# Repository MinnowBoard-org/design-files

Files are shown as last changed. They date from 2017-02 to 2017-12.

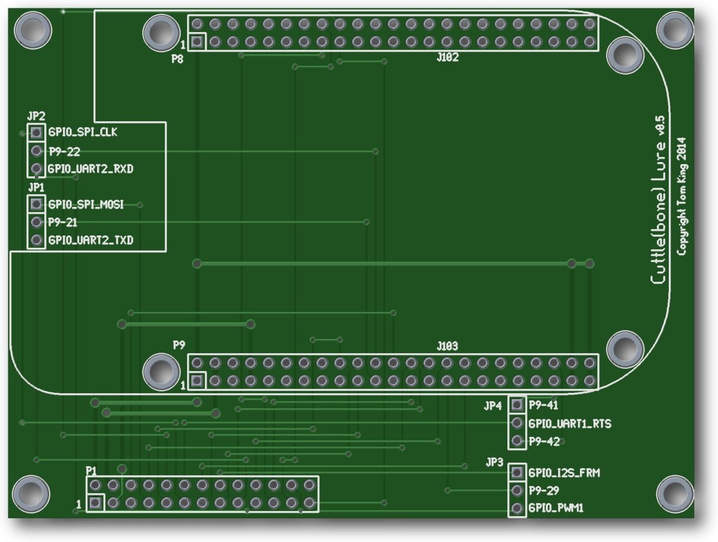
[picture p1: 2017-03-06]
expansion-boards-lures/cuttle-bone-lure/hardware/cuttle_lure_front.jpg

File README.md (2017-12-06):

# MinnowBoard.org Hardware Design Files

## PURPOSE:
The `/design-files` repository is the target folder for official [MinnowBoard.org] hardware design files. Such files may include: design schematics, printed circult board (PCB) design database(s), PCB gerber files, PCB manufacturing files, bill of materials (BOM), 3D models, mechanical step files, thermal models, multiple versions for different design tools, some firmware, CPLD code, FPGA code, etc. 

## LICENSING:
*All files are subject to the associated licensing stated within each directory.* [MinnowBoard.org] is founded with a goal for full open source, defaulting to [Creative Commons Attribution 4.0](https://creativecommons.org/licenses/by/4.0/) for hardware and [MIT](https://opensource.org/licenses/MIT) license for code....to let developers take the files and develop without licensing burden. We stick to this as much as possible. For a deep read, see MinnowBoard.org [Terms of Service and Intellectual Property Rights](https://www.minnowboard.org/terms-of-service). If you have questions, [Contact us.](https://www.minnowboard.org/help)

## SAFETY AND REGULATORY:
### The Disclaimer:
>The files for MinnowBoard reference designs do not guarantee regulatory compliance.  The developer is responsible for all aspects of regulatory evaluation, reporting and registration when modifying and/or incorporating any element of these reference designs into a host device.

### What it means:
Our goal is for developers to easily prototype their innovative idea with optimized MinnowBoard hardware/software/firmware, but this isn't the end goal. We ALSO want to enable developers to easily PRODUCTIZE and bring their idea to market. Such a product must meet the legal, safety, regulatory, commerce, etc, requirements for the target distribution geography. Thus, we spend extra time and effort to design our developer boards to already meet the electrical, EMI/EMC, safety, etc requirements for most global countries, and further, we test to those standards in licensed labs. We will often share the reports as reference baseline for developers considering design modifications. 
>Example: The current MinnowBoard target for EMI/EMC emissions in the United States is open board FCC Title 47 Part 15 Class B, which generally allows distribution to both commercial and residential environments. (Most developer boards are not even close to this).

*The Takeaway:* We do our best to minimize the effort required to achieve regulatory compliance on developer production design derivatives, but you are responsible for all aspects of regulatory compliance for your modification designs.

[MinnowBoard.org]: https://minnowboard.org/

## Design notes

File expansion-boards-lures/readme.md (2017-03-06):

Breakout boards called "Lures" expand functionality of the MinnowBoard MAX by connecting to either the low- or high-speed
expansion connectors. Lures are owned and supported by their respective owners and manufacturers. The community can give 
you best effort support; issues should be taken to the respective manufacturers and designers.

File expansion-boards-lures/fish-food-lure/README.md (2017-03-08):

# lure-fish-food

Fish Food Lure, breadboard adapter for the MinnowBoard MAX / Turbot compatible boards (because you feed bread to fish).   

Fish Food Lure enables fast prototyping on a breadboard, connects to the MinnowBoard using a ribbon cable.      

Designed and released by Jose Navarro. 

Released under the Creative Commons Attribution 3.0 License     
https://creativecommons.org/licenses/by/3.0/   

Designed using DipTrace 3.0

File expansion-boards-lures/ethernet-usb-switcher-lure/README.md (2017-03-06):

# lure-lse-eth-usb-switch
Ethernet and USB Switcher controlled via the LSE for MinnowBoard MAX / Turbot compatible boards  

This Lure enables the physical disconnection of the Ethernet and USB ports of the device connected to this Lure. You may use this Lure to remotely enable environments, testing tasks, etc. 

Diptrace was used for the creation of this project.

Licensed under the Creative Commons Attribution Share-Alike 3.0 License.

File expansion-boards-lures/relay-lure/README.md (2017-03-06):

# lure-lse-relay  
"Relay Lure" for MinnowBoard MAX / Turbot compatible boards Low Speed Expansion (LSE) header  

Features
4-channel Relay Lure that can handle ~6A, 110VAC / ~4A, 30VDC per channel(Take appropriate precautions when handling this board).  
Screw in Block terminals with Normally Closed and Normally open connections(5mm Pitch).   
GPIOs are protected using Optocouplers.    
Experimental header to connect an HC-06 type Bluetooth module to a UART port, to enable the control of the MinnowBoard with another Bluetooth enabled devices. 

---------------------------------------------

"Big Relay Lure" for MinnowBoard MAX / Turbot compatible boards Low Speed Expansion (LSE) header 

Features
8-channel Relay Lure that can handle ~6A, 110VAC / ~4A, 30VDC per channel(Take appropriate precautions when handling this board).  
Screw in Block terminals with Normally Closed and Normally open connections(9.52mm Pitch).   
GPIOs are protected using Optocouplers. 
1-Wire devices hub, devices can be hooked up via RJ11 connectors and/or screw in block terminals.
The "Big Relay Lure" is an external Lure with 4 holes(2.5mm diameter) for standoffs, connects to the MinnowBoard via a Ribbon Cable.  

Both Designs made in Diptrace 3.0

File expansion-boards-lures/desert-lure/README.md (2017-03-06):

# DesertLure
A lure for the MinnowBoard Max & MinnowBoard Turbot.  Copyright (C) 2015 Smallworks, LLC

This design is made with [EAGLE CAD](http://www.cadsoftusa.com/eagle-pcb-design-software/about-eagle/) 

This work is licensed under a Creative Commons Attribution-ShareAlike 4.0 International License
[  
*Licensing CC BY-SA 4.0*](http://creativecommons.org/licenses/by-sa/4.0/)

It may be used for Educational, Personal, or Commercial Use, provided you keep these notices,
attribution, and share-alike. When you apply these licenses to material you create, 
it meets the Freedom Defined definition of a "Free Cultural Work". 
Free cultural works are the ones that can be most readily used, shared, 
and remixed by others, and go furthest toward creating a commons of freely reusable materials.

-------------------------------------------------------------------------------------------

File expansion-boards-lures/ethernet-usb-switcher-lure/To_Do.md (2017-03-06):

To do list

Use Diptrace 2.9 Beta or wait for final relase to make use of the Differential Pairs utility. 

Move Ethernet and USB ports so they are closer together in order to keep the data paths shorter.

Use a separate transistor to drive each relay in order to prevent overloading the 2 transistors in darlington array.  

Done:
- Make power paths bigger to prevent power issues if 1 OZ copper manufacturing process is choosen(Which is the most common). 
- Remove the 5V regulator as it is an overkill part of the design.

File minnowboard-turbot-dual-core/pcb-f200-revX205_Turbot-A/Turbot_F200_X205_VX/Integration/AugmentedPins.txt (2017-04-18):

------------------------------------------------------------------------
            Part/Reference             | Pin | Augmented Net Name
------------------------------------------------------------------------
 Part 4124-0013                        |
       U41                             |    7| <unconnected pin>
       U41                             |   17| <unconnected pin>

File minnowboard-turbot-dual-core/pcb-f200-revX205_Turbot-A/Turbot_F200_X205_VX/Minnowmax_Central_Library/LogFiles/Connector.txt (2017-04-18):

	SLB2LMC  -  Add Symbol Information to LMC. Version 16.0.0.1
	(c) Copyright Mentor Graphics Corporation 2003.
	All Rights Reserved.

Reading Library Path Information...
Reading Font Information...
Reading Text Property Information...
Reading Pin Type Information...
Processing Connector
	Symbol CON_HIER_BI
	Symbol CON_HIER_I
	Symbol CON_HIER_IQ
	Symbol CON_HIER_O
	Symbol CON_HIER_OQ
	Symbol CON_HIER_T
	Symbol CON_INTER_BI
	Symbol CON_INTER_I
	Symbol CON_INTER_IQ
	Symbol CON_INTER_O
	Symbol CON_INTER_OQ
	Symbol CON_INTER_T
	Symbol CON_INTRA
	Symbol CONNP
	Symbol CONNS
	Symbol ESPL1
	Symbol ESROPE
	Symbol RWTERM
SLB2LMC utility complete

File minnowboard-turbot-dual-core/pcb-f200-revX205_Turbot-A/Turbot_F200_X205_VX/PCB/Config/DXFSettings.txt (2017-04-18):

.FILETYPE DXF_EXPORT_SETTINGS
.VERSION "VB99.1"
.DATE "09/17/2015 15:18:10"

!  This file contains settings for the most recent DXF export session

.UNITS in

.SCHEME "AssyBot"
 ..SCHEME_LOCATION Local

.FILL_PADS 0

.BOARD_CONTENTS 0

.MIRROR_OUTPUT 0

.ITEM "Assembly Outlines Btm"
 ..LAYER "Assembly_Outlines_Btm"
 ..EXPORT 1

.ITEM "Assembly Ref Des Btm"
 ..LAYER "Assembly_Ref_Des_Btm"
 ..EXPORT 1

.ITEM "Board Outline"
 ..LAYER "Board_Outline"
 ..EXPORT 1

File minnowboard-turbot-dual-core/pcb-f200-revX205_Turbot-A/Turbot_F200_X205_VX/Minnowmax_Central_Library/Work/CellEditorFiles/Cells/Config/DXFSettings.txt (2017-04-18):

.FILETYPE DXF_EXPORT_SETTINGS
.VERSION "VB99.1"
.DATE "05/28/2007 22:27:46"

!  This file contains settings for the most recent DXF export session

.UNITS th

.SCHEME "Default"
 ..SCHEME_LOCATION Local

.ITEM "Assembly Outlines Top"
 ..LAYER "Assembly_Outlines_Top"
 ..EXPORT 1

.ITEM "Board Origin"
 ..LAYER "Board_Origin"
 ..EXPORT 1

.ITEM "Board Outline"
 ..LAYER "Board_Outline"
 ..EXPORT 1

.ITEM "Cell_Info"
 ..LAYER "Cell_Info"
 ..EXPORT 1

.ITEM "Mounting Hole Pads Layer 1"
 ..LAYER "Mounting_Hole_Pads_Layer_Top"
 ..EXPORT 1

.ITEM "Mounting Hole Pads Layer 2"
 ..LAYER "Mounting_Hole_Pads_Layer_Bottom"
 ..EXPORT 1

.ITEM "Mounting Holes Layer 1"
 ..LAYER "Mounting_Holes_Layer_Top"
 ..EXPORT 1

.ITEM "Mounting Holes Layer 2"
 ..LAYER "Mounting_Holes_Layer_Bottom"
 ..EXPORT 1

.ITEM "NC Drill Origin"
 ..LAYER "NC_Drill_Origin"
 ..EXPORT 1

.ITEM "Placement Outlines Top"
 ..LAYER "Placement_Outlines_Top"
 ..EXPORT 1

.ITEM "Route Obstructs Layer 1"
 ..LAYER "Route_Obstructs_Layer_Top"
 ..EXPORT 1

.ITEM "Route Obstructs Layer 2"
 ..LAYER "Route_Obstructs_Layer_Bottom"
 ..EXPORT 1

.ITEM "Silkscreen Outlines Top"
 ..LAYER "Silkscreen_Outlines_Top"
 ..EXPORT 1

.ITEM "Soldermask Pads Btm"
 ..LAYER "Soldermask_Pads_Btm"
 ..EXPORT 1

.ITEM "Soldermask Pads Top"
 ..LAYER "Soldermask_Pads_Top"
 ..EXPORT 1

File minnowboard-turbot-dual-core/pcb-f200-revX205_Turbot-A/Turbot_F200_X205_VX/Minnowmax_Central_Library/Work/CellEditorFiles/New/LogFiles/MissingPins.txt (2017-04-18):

Missing Pins Log

Date : 11:19:29 AM Dec 01, 2012

During load of this design, cells within the design have been found missing pins or mounting holes
compared to the cell as defined in the cell library.  In order to maintain data integrity, these cells need
to be reset from the cell library and forward annotation needs to be run.  This process will cause any 
layout cell edits to be lost for the cells listed below.

"Ref Des" "qfn" has 48 pin(s) within Layout and 0 pin(s) within the Cell Library.

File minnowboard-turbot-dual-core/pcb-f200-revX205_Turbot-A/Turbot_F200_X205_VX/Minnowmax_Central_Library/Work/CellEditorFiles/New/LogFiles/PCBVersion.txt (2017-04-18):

 Version: EXP2005.3_070529.00 2005.3

Environment Variables:
----------------------
HOMEDRIVE = "C:"
HOMEPATH = "\Documents and Settings\XPMUser"
MGC_HOME = "C:/MentorGraphics/2005EXP/MGC_HOME.ixn"
OS = "Windows_NT"
PATH = "C:\MentorGraphics\2005EXP\SDD_HOME\common\win32\bin;C:\MentorGraphics\2005EXP\SDD_HOME\common\win32\lib;C:\MentorGraphics\2005EXP\SDD_HOME\common\win32\_bin;C:\MentorGraphics\2005EXP\SDD_HOME\wg\win32\bin;C:\MentorGraphics\2005EXP\SDD_HOME\wg\win32\lib;C:\MentorGraphics\2005EXP\SDD_HOME\common\win32\bin;C:\MentorGraphics\2005EXP\SDD_HOME\common\win32\lib;C:\WINDOWS\system32;C:\WINDOWS;C:\WINDOWS\System32\Wbem;C:/MentorGraphics/2005EXP/MGC_HOME.ixn\bin;C:/MentorGraphics/2005EXP/MGC_HOME.ixn\lib;C:/MentorGraphics/2005EXP/MGC_HOME.ixn\bin;C:/MentorGraphics/2005EXP/MGC_HOME.ixn\lib;C:\OrCAD\OrCAD_10.5\tools\bin;C:\OrCAD\OrCAD_10.5\tools\fet\bin;C:\OrCAD\OrCAD_10.5\tools\Capture;C:\Cadence\PSD_14.2\tools\pcb\bin;C:\Cadence\PSD_14.2\tools\bin;C:\Cadence\PSD_14.2\tools\jre\bin;C:\Cadence\PSD_14.2\tools\fet\bin;C:\Cadence\PSD_14.2\tools\specctra\bin;C:\Cadence\PSD_14.2\tools\libutil\bin"
SDD_HOME = "C:\MentorGraphics\2005EXP\SDD_HOME"
TEMP = "C:\DOCUME~1\XPMUser\LOCALS~1\Temp"
TMP = "C:\DOCUME~1\XPMUser\LOCALS~1\Temp"

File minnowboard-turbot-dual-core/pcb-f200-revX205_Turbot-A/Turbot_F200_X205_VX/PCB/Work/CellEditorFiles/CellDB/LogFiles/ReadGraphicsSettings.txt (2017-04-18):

                         Read Graphics Settings Log File
                         -------------------------------

                      10:01 AM Thursday, December 03, 2015
                                   Job Name: 

Attempting to read Graphics Settings file <Graphics Settings.hkp>

The settings file full pathname is <C:\Turbot\Turbot_F200_X205_VX\PCB\Work\CellEditorFiles\CellDB\Config\Graphics Settings.hkp>

Found 2 views, but 3 are required.

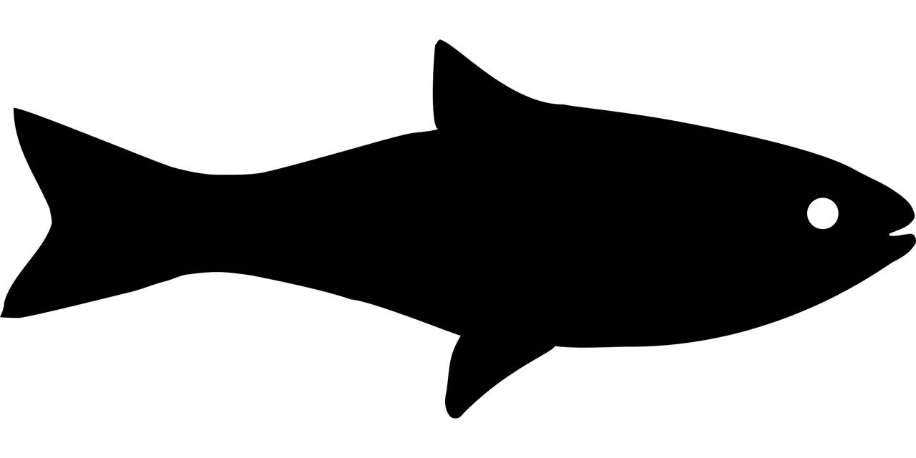
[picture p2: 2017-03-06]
expansion-boards-lures/relay-lure/Big Relay Board/Design Files/fish-1294822_1280.tiff

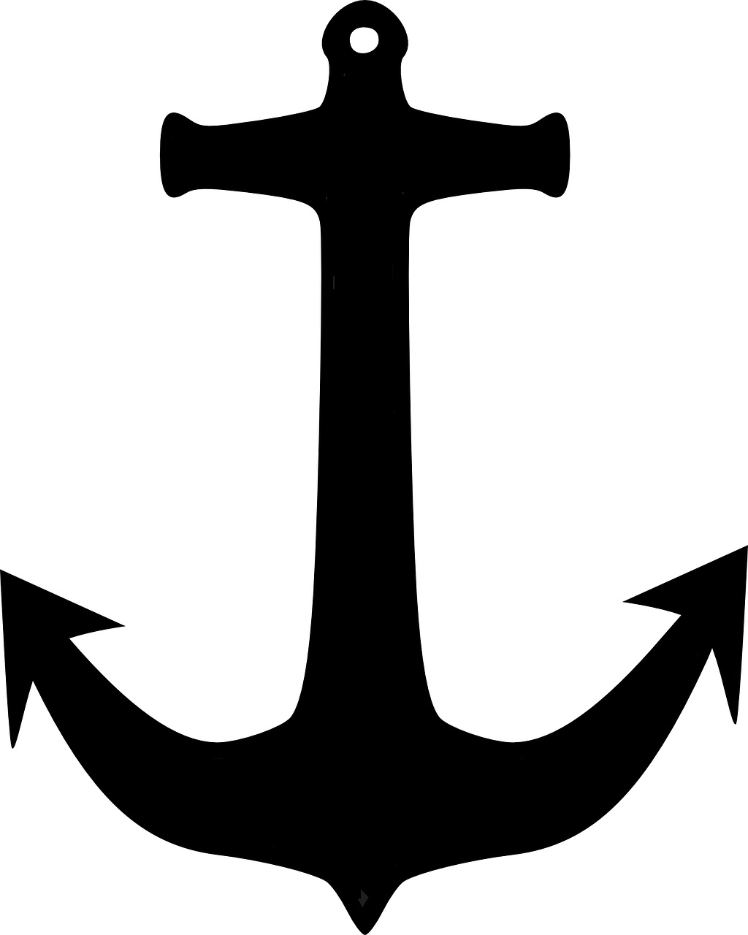
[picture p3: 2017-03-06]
expansion-boards-lures/fish-food-lure/Design files/anchor-297206_1280.jpg

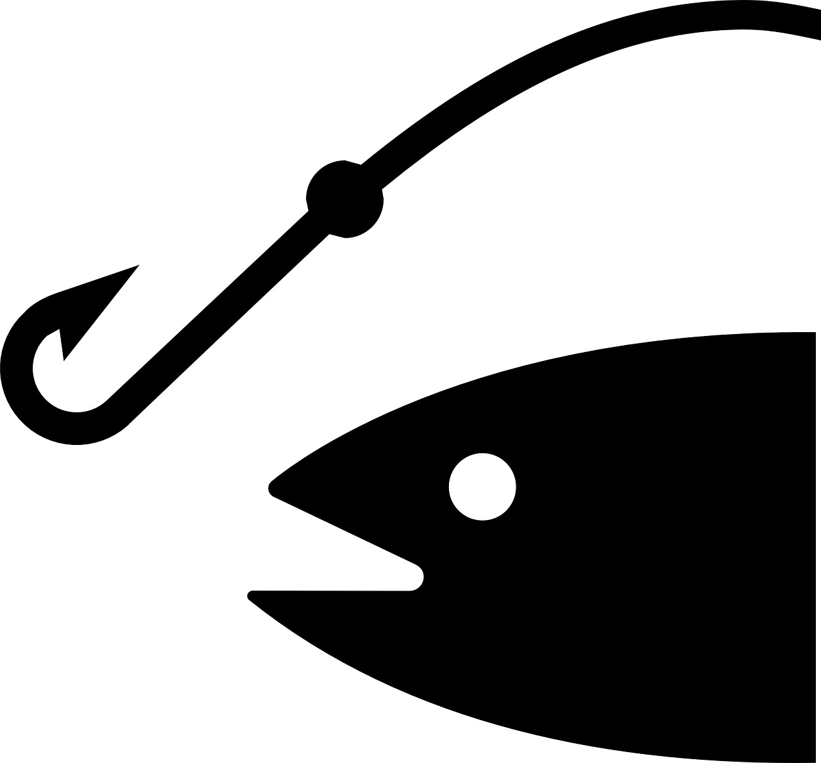
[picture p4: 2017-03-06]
expansion-boards-lures/fish-food-lure/Design files/fish-304097_1280.jpg

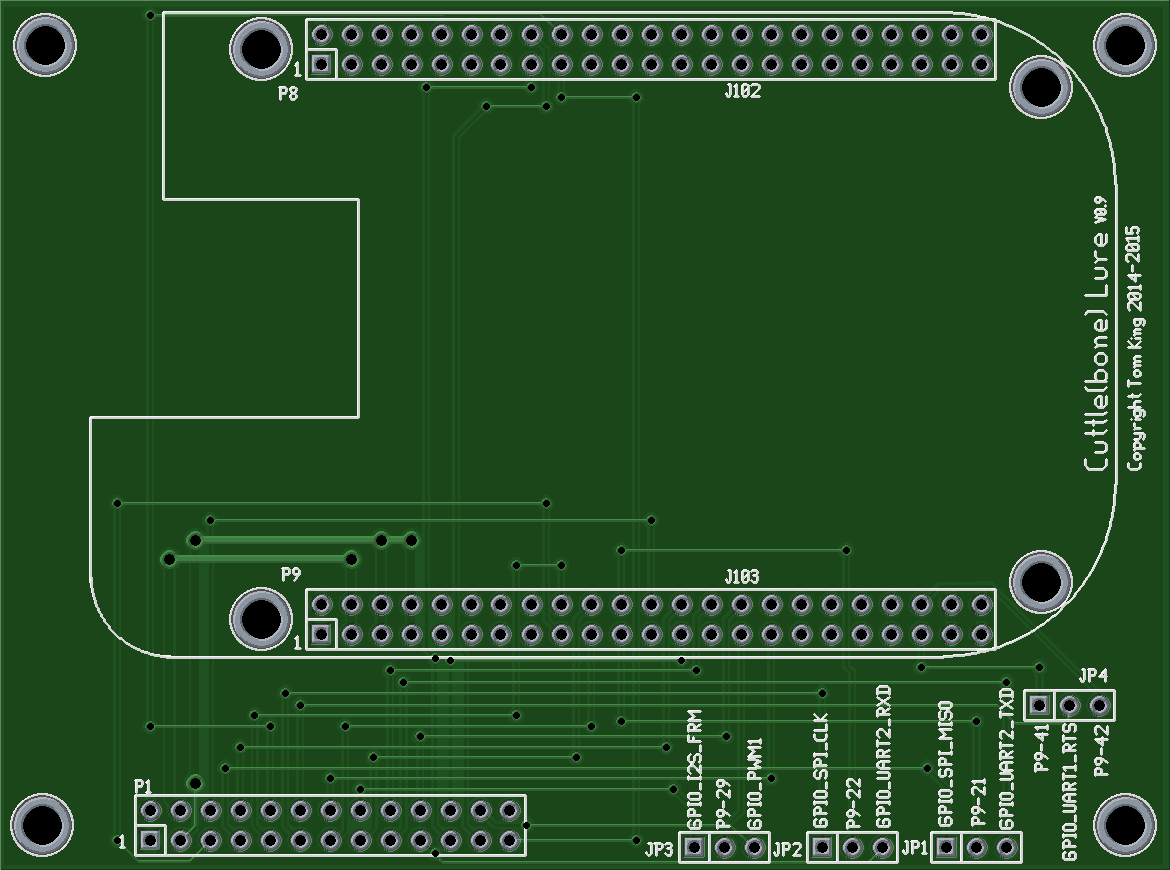
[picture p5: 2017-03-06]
expansion-boards-lures/cuttle-bone-lure/hardware/cuttle_lure_v0.9.png

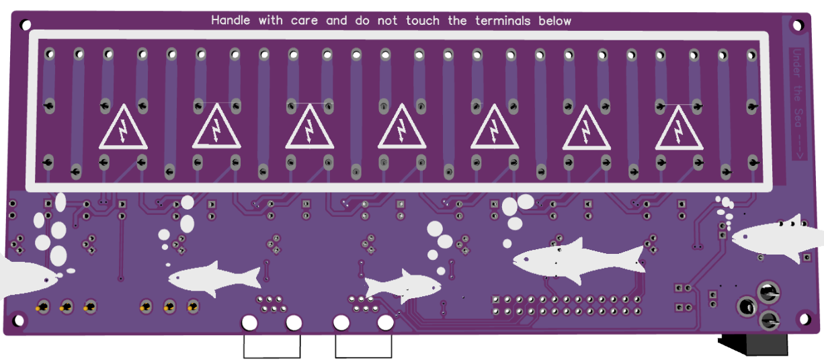
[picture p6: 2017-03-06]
expansion-boards-lures/relay-lure/Big Relay Board/Big Relay Lure back.png

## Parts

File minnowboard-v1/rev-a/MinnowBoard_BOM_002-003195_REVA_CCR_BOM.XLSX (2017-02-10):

Item_no | Part_class | Part_no | Rev | Descript | Partmfgr | Mfgr_pt_no | Qty | Ref_des
1 | PCB | 000-0002806 | A | MINNOW BOARD | GENR | 000-0002806 | 1 | PCB1
2 | BATTERY | 353-0003073 |  | BATT,COIN,12.5MM,VET MT | MPD | BS-1225-PC | 1 | BH1
3 | RES | 110-0002124 |  | 0603,0R00,JUMPER,1/10W | PANASONI | ERJ-3GEY0R00V | 2 | FB1, FB3
4 | CAP-SMT | 123-0001157 |  | 0805,10UF,10V,X5R,10% | KEMET | C0805C106K8PACTU | 41 | C1, C2, C22, C32, C41, C65, C66, C67, C68, C69, C70, C79, C81, C82, C88, C90, C115, C271, C272, C275, C276, C279, C280, C284, C297, C298, C303, C306, C307, C310, C323, C336, C337, C347, C348, C349, C361, C365, C380, C390, C391
5 | CAP-SMT | 123-0001144 |  | 0603,4.7UF,10V,X5R,10% | TAIYO_YUDEN | LMK107BJ475KA-T | 14 | C10, C20, C26, C109, C160, C376, C377, C379, C381, C386, C389, C397, C398, C409
6 | CAP-SMT | 123-0001032 |  | 0402,0.01UF,16V,X7R,10% | AVX | 0402YC103KAT2A | 20 | C100, C118, C119, C126, C132, C138, C139, C144, C149, C152, C155, C162, C166, C180, C181, C182, C183, C281, C282, C283
7 | CAP-SMT | 123-0001115 |  | 0402,47PF,50V,C0G/NP0,5% | MURATA | GRM1555C1H470JZ01D | 4 | C107, C108, C239, C290
8 | CAP-SMT | 123-0001045 |  | 0402,0.047UF,25V,X7R,10% | TAIYO_YUDEN | TMK105B7473KV-F | 2 | C141, C143
9 | CAP-SMT | 123-0001078 |  | 0402,12PF,50V,C0G/NP0,5% | MURATA | GRM1555C1H120JZ01D | 2 | C156, C157
10 | CAP-SMT | 123-0001095 |  | 0402,2.2UF,6.3V,X5R,20% | MURATA | GRM155R60J225ME15D | 17 | C16, C25, C104, C106, C135, C171, C203, C204, C206, C213, C218, C219, C223, C226, C228, C421, C422
11 | CAP-SMT | 123-0003096 |  | 1411,47UF,6.3V,10% | NICHICON | F930J476KBA | 8 | C174, C175, C338, C341, C343, C344, C345, C346
12 | CAP-SMT | 123-0003098 |  | 0402,820PF,50V,C0G/NPO,5% | MURATA | GRM1555C1H821JA01D | 3 | C185, C202, C212
13 | CAP-SMT | 123-0003097 |  | 0402,200PF,50V,C0G/NP0,5% | MURATA | GRM1555C1H201JA01D | 3 | C205, C208, C222
14 | CAP-SMT | 123-0001060 |  | 0402,0.22UF,6.3V,X5R,10% | TAIYO_YUDEN | JMK105BJ224KV-F | 4 | C247, C263, C378, C403
15 | CAP-SMT | 123-0003064 |  | 220UF,10V,20% | PANASONI | EEE-FK1A221XP | 8 | C350, C372, C384, C394, C395, C396, C417, C418
16 | CAP-SMT | 123-0003611 |  | 0402,1000PF,6.3V,X5R,10% | MURATA | GRM155R60J102KA01D | 1 | C388
17 | CAP-SMT | 123-0001074 |  | 0402,100PF,50V,C0G/NP0,5% | MURATA | GRM1555C1H101JA01D | 9 | C49, C51, C61, C63, C64, C148, C151, C161, C165
18 | CAP-SMT | 123-0003092 |  | 1206,1UF,16V,X7R,10% | TDK | C3216X7R1C105K/0.85 | 1 | C58
19 | CAP-SMT | 123-0001092 |  | 0402,1UF,6.3V,X5R,10% | MURATA | GRM155R60J105KE19D | 83 | C6, C17, C18, C19, C47, C50, C56, C80, C125, C140, C158, C163, C168, C169, C170, C178, C187, C191, C193, C194, C195, C196, C197, C198, C199, C200, C201, C234, C237, C238, C240, C241, C242, C243, C244, C245, C246, C248, C249, C250, C251, C252, C253, C254,C255, C256, C257, C258, C259, C260, C261, C262, C264, C265, C287, C288, C289, C291, C292, C293, C294, C295, C296, C314, C315, C316, C317, C318, C319, C320, C321, C322, C342, C351, C352, C356, C357, C370, C373, C400, C401, C402, C1044
20 | CAP-SMT | 123-0003093 |  | 0402,2700PF,50V,X7R,10% | MURATA | GRM155R71H272KA01D | 8 | C7, C13, C34, C35, C117, C137, C266, C268
21 | CAP-SMT | 123-0003102 |  | 0805,22UF,10V,X5R,20% | TAIYO_YUDEN | LMK212BJ226MG-T | 11 | C71, C87, C91, C92, C186, C231, C232, C360, C362, C405, C406
22 | CAP-SMT | 123-0001082 |  | 0402,18PF,50V,C0G/NP0,5% | AVX | 04025A180JAT2A | 2 | C72, C74
23 | CAP-SMT | 123-0003347 |  | 0402,20PF,50V,C0G/NP0,5% | YAGEO | CC0402JRNPO9BN200 | 2 | C75, C86
24 | CAP-SMT | 123-0001046 |  | 0402,0.1UF,16V,X5R,10% | MURATA | GRM155R61C104KA88B | 162 | C8, C14, C15, C23, C24, C27, C28, C29, C30, C31, C33, C36, C37, C38, C39, C40, C42, C43, C44, C45, C46, C48, C52, C53, C54, C55, C57, C59, C60, C62, C73, C76, C77, C78, C83, C84, C85, C94, C96, C97, C98, C99, C101, C102, C105, C114, C116, C122, C123, C124, C127, C128, C129, C130, C131, C133, C134, C136, C142, C145, C146, C147, C150, C153, C154, C159, C164, C167, C172, C173, C176, C177, C179, C184, C188, C189, C190, C192, C207, C209, C210, C211, C214, C215, C216, C217, C220, C221, C224, C225, C227, C229, C230, C233, C236, C267, C269, C270, C273, C274, C277, C278, C285, C286, C299, C300, C301, C302, C304, C305, C308, C309, C311, C312, C313, C324, C325, C326, C327, C328, C329, C330, C331, C332, C333, C334, C335, C339, C340, C353, C354, C355, C358, C359, C364, C366, C367, C368, C369, C371, C374, C375, C382, C385, C387, C392, C393, C399, C404, C407, C408, C410, C411, C412, C413, C414, C415, C420, C423, C424, C1043, C235
25 | CAP-SMT | 123-0003088 |  | 0402,470PF,50V,C0G/NP0,5% | MURATA | GRM1555C1H471JA01D | 4 | C89, C93, C95, C419
26 | LED | 131-0001743 |  | 0603,GREEN/CLEAR | LITEON | LTST-C190GKT | 4 | D11, D12, D13, D15
27 | LED | 131-0001747 |  | 0603,RED/CLEAR | LITEON | LTST-C190CKT | 1 | D14
28 | DIODE | 130-0001371 |  | 0603,TVS,24 VDC,ESD | LITTLEFUSE | PGB1010603MR | 4 | D2, D3, D4, D5
29 | DIODE | 130-0003105 |  | ZENER,3.3V,500MW,SOD123 | DIODES_I | MMSZ5226B-7-F | 1 | D6
30 | DIODE | 130-0003083 |  | TVS,1500W,5V,DO-214AB | LITTLEFUSE | SMCJ5.0CA | 1 | D7
31 | DIODE | 130-0003078 |  | SCHOTTKY,30V,200MA,SOT23 | DIODES_I | BAT54TA | 1 | D9
32 | FUSE | 152-0003279 |  | 1206,PTC RESET,0.75A,8V | LITTLEFUSE | 1206L075THYR | 1 | F2
33 | FERRITE | 126-0003085 |  | 0603,120R,500MA | MURATA | BLM18BB121SN1D | 8 | FB2, FB4, FB8, FB9, FB10, FB11, FB12, FB13
34 | FERRITE | 126-0001427 |  | 0805,150R,800MA | LAIRD_S | LI0805H151R-10 | 2 | FB6, FB7
35 | CONN/HDR | 158-0001276 |  | RCPT,HDMI,R/A | FCI | 10029449-001RLF | 1 | J1
36 | CONN/HDR | 258-0001299 |  | 3 POS,SGLE,STR,TIN | SULLINS | PEC03SAAN | 1 | J10
37 | CONN/HDR | 258-0003129 |  | 8 POS,DUAL,TIN | FCI | 67997-408HLF | 1 | J11
38 | CONN/HDR | 258-0003669 |  | MAG45 JACK W/LED GIGABIT | LINK-PP | LPJG16314A4NL | 1 | J12
39 | CONN/HDR | 158-0003076 |  | RCPT,STD,MICRO,USB,TYPE B | FCI | 10103594-0001LF | 1 | J14
40 | CONN/HDR | 258-0001330 |  | JACK,PWR,2.1MM | CUI | PJ-002A | 1 | J15
41 | CONN/HDR | 258-0002513 |  | 2 POS,DUAL,TIN | FCI | 67997-402HLF | 2 | J2, J13
42 | CONN/HDR | 258-0003610 |  | 7 POS,SERIAL,GOLD,SATA | MOLEX | 0470804005 | 1 | J3
43 | CONN/HDR | 258-0002845 |  | 4 POS,SGLE,STR,TIN | SULLINS | PEC04SAAN | 1 | J4
44 | CONN/HDR | 158-0003130 |  | 100 POS,FH,GOLD,.8MM | TE_CONN | 1-5177986-4 | 1 | J8
45 | CONN/HDR | 258-0002540 |  | 10 POS,DUAL,TIN | FCI | 67997-410HLF | 1 | J9
46 | INDUCTOR | 125-0003114 |  | 4.7UH,30%,1.5A | TDK | VLCF4028T-4R7N1R5-2 | 1 | L12
47 | INDUCTOR | 125-0003106 |  | 1.5UH,30%,3.6A | TAIYO_YUDEN | NR5040T1R5N | 3 | L13, L14, L17
48 | INDUCTOR | 125-0003066 |  | 1.5UH,30%,2.5A | PANASONIC | ELL-6PG1R5N | 2 | L15, L16
49 | INDUCTOR | 125-0003169 |  | 1.0UH,30%,2.0A | TDK | VLF3012ST-1R0N2R0 | 1 | L19
50 | FILTER | 127-0003065 |  | COM MODE 90R0 | PANASONIC | EXC-24CG900U | 4 | L2, L3, L4, L5
51 | INDUCTOR | 125-0003117 |  | 1.8UH,30%,2A | TDK | VLCF5020T-1R8N2R0 | 1 | L20
52 | INDUCTOR | 125-0003103 |  | 1210,20%,4.7UH,1000MA | MURATA | LQH32PN4R7NN0L | 1 | L21
53 | FERRITE | 126-0001421 |  | 0603,300R,500MA | TDK | MMZ1608R301A | 7 | L6, L7, L8, L9, L10, L11, L18
54 | CONN/HDR | 158-0001269 |  | MICRO SD,PUSH-PUSH | ALPS | SCHA5B0200 | 1 | P1
55 | CONN/HDR | 158-0003524 |  | 5 POS,STEREO JACK,3.5MM,GRN | CUI | SJ1-3515-SMT-TR-GR | 1 | P3
56 | CONN/HDR | 158-0003523 |  | 5 POS,STEREO JACK,3.5MM,BLE | CUI | SJ1-3515-SMT-TR-BE | 1 | P2
57 | CONN/HDR | 158-0001279 |  | RCPT,USB MINI,R/A | HIROSE | UX60SC-MB-5ST(80) | 1 | PP4
58 | CONN/HDR | 258-0001344 |  | RCPT,USB,TYPE A,R/A,DUAL | FCI | 72309-8034BLF | 1 | P5
59 | TRANSIS | 132-0002279 |  | NPN/NPN,W/RES,50V,SMINI6 | PANASONIC | DMC564040R | 3 | Q1, Q2, Q8
60 | TRANSIS | 132-0002268 |  | MOSFET,N-CH,50V,200MA,SOT23 | DIODES_INC | BSS138-7-F | 5 | Q3, Q4, Q5, Q6, Q7
61 | TRANSIS | 132-0003412 |  | MOSFET,P-CH,20V,460MA,SOT523 | DIODES_INC | DMG1013T-7 | 1 | Q9
62 | RES | 110-0003145 |  | 0402,56R2,1/16W,1% | VISHAY_T | CRCW040256R2FKTD | 31 | R1, R2, R3, R4, R5, R6, R7, R8, R9, R15, R16, R17, R18, R19, R22, R23, R24, R35, R36, R39, R40, R43, R66, R67, R84, R86, R332, R333, R21, R334, R340
63 | RES | 110-0001877 |  | 0402,10K0,1/16W,1% | KOA | RK73H1ETTP1002F | 84 | R10, R11, R25, R31, R32, R46, R50, R51, R61, R62, R70, R75, R92, R106, R108, R118, R122, R164, R165, R171, R182, R188, R213, R214, R215, R216, R224, R229, R231, R242, R243, R244, R245, R246, R247, R248, R256, R260, R274, R280, R281, R287, R295, R297, R299, R303, R315, R321, R322, R323, R324, R327, R339, R345, R347, R348, R349, R350, R372, R374, R375, R377, R386, R387, R388, R393, R411, R415, R416, R417, R420, R422, R430, R431, R432, R433, R444, R449, R451, R452, R454, R457, R467, R629
64 | RES | 110-0002076 |  | 0402,51K0,1/16W,1% | STACKPOLE | RMCF0402FT51K0 | 1 | R12
65 | RES | 110-0002014 |  | 0402,33R0,1/16W,1% | KOA | RK73HETTP33R0F | 20 | R140, R142, R284, R285, R286, R289, R290, R291, R292, R293, R294, R298, R312, R313, R355, R358, R413, R414, R438, R439
66 | RES | 110-0003049 |  | 0402,249R,1/10W,1% | PANASONIC | ERJ-2RKF2490X | 1 | R141
67 | RES | 110-0003137 |  | 0402,24R9,1/16W,1% | VISHAY_T | CRCW040224R9FKED | 4 | R167, R169, R425, R426
68 | RES | 110-0002002 |  | 0402,330R,1/16W,1% | KOA | RK73H1ETTP3300F | 4 | R173, R174, R195, R210
69 | RES | 110-0003196 |  | 0402,0R56,1/10W,5% | CTS | 73L1R56J | 6 | R175, R185, R186, R196, R197, R212
70 | RES | 110-0003167 |  | 0805,0R01,1/8W,1% | VISHAY_T | RL0805FR-070R01L | 4 | R176, R187, R211, R241
71 | RES | 110-0002558 |  | 0402,22R0,1/10W,1% | PANASONIC | ERJ-2RKF22R0X | 14 | R179, R180, R189, R190, R191, R192, R329, R330, R338, R346, R351, R352, R353, R354
72 | RES | 110-0002625 |  | 0402,470R,1/16W,1% | VISHAY_T | CRCW0402470RFKED | 1 | R184
73 | RES | 110-0002048 |  | 0402,49K9,1/16W,1% | STACKPOLE | RMCF0402FT49K9 | 5 | R199, R202, R203, R206, R207
74 | RES | 110-0003143 |  | 0402,39R2,1/16W,1% | VISHAY_T | CRCW040239R2FKED | 6 | R20, R33, R34, R37, R38, R55
75 | RES | 110-0002047 |  | 0402,499R,1/16W,1% | ROHM | MCR01MZPF4990 | 5 | R200, R201, R204, R205, R208
76 | RES | 110-0003655 |  | 0402,39K0,1/16W,1% | YAGEO | RC0402FR-0739KL | 1 | R234
77 | RES | 110-0002103 |  | 0402,68K0,1/10W,1% | PANASONIC | ERJ-2RKF6802X | 1 | R235
78 | RES | 110-0003656 |  | 0402,5K10,1/16W,1% | YAGEO | RC0402FR-075K1L | 1 | R249
79 | RES | 110-0003140 |  | 0402,300R,1/16W,1% | VISHAY_T | CRCW0402300RFKED | 5 | R250, R251, R252, R253, R263
80 | RES | 110-0001985 |  | 0402,2K20,1/16W,1% | STACKPOLE | RMCF0402FT2K20 | 3 | R254, R255, R626
81 | RES | 110-0002050 |  | 0402,49R9,1/16W,1% | KOA | RK73H1ETTP49R9F | 10 | R26, R74, R116, R117, R145, R146, R364, R365, R391, R392
82 | RES | 110-0002090 |  | 0402,5K60,1/16W,1% | KOA | RK73H1ETTP5601F | 2 | R268, R269
83 | RES | 110-0003657 |  | 0603,10M0,1/10W,5% | PANASONIC | ERJ-3GEYJ106V | 1 | R27
84 | RES | 110-0003141 |  | 0402,35R7,1/16W,1% | VISHAY_T | CRCW040235R7FKED | 2 | R275, R361
85 | RES | 110-0003136 |  | 0402,191R,1/16W,1% | VISHAY_T | CRCW0402191RFKED | 1 | R277
86 | RES | 110-0002576 |  | 0402,20K0,1/16W,1% | VISHAY_T | CRCW040220K0FKED | 2 | R28, R266
87 | RES | 110-0002074 |  | 0402,510R,1/16W,1% | YAGEO | RC0402FR-07510RL | 2 | R29, R48
88 | RES | 110-0001925 |  | 0402,1K00,1/16W,1% | STACKPOLE | RMCF0402FT1K00 | 46 | R30, R45, R49, R71, R77, R89, R90, R101, R107, R114, R115, R130, R131, R132, R133, R135, R181, R193, R209, R236, R262, R267, R270, R271, R272, R310, R317, R320, R337, R368, R369, R394, R395, R396, R397, R398, R399, R403, R447, R468, R623, R624, R625,R473,R474,R475
89 | RES | 110-0003062 |  | 0402,750R,1/10W,1% | PANASONIC | ERJ-2RKF7500X | 1 | R304
90 | RES | 110-0001896 |  | 0402,12K0,1/16W,1% | ROHM | MCR01MZPF1202 | 7 | R341, R344, R371, R378, R380, R382, R383
91 | RES | 110-0003144 |  | 0402,54R9,1/16W,1% | VISHAY_T | CRCW040254R9FKED | 2 | R356, R363
92 | RES | 110-0003139 |  | 0402,27R4,1/16W,1% | VISHAY_T | CRCW040227R4FKED | 2 | R357, R362
93 | RES | 110-0003048 |  | 0402,2K43,1/10W,1% | PANASONIC | ERJ-2RKF2431X | 1 | R359
94 | RES | 110-0001884 |  | 0402,10R0,1/16W,1% | KOA | RK73H1ETTP10R0F | 5 | R406, R407, R408, R409, R442
95 | RES | 110-0002061 |  | 0402,4K70,1/16W,1% | KOA | RK73H1ETTP4701F | 4 | R412, R436, R437, R465
96 | RES | 110-0001935 |  | 0402,1K50,1/16W,1% | NIC | NRC04F1501TRF | 1 | R421
97 | RES | 110-0001860 |  | 0402,100K,1/16W,1% | KOA | RK73H1ETTP1003F | 2 | R427, R428
98 | RES | 110-0001988 |  | 0402,2K37,1/16W,1% | STACKPOLE | RMCF0402FT2K37 | 1 | R435
99 | RES | 110-0003142 |  | 0402,374R,1/16W,1% | VISHAY_T | CRCW0402374RFKED | 1 | R443
100 | RES | 110-0002166 |  | 0805,0R00,JUMPER,1/8W | ROHM | MCR10EZPJ000 | 1 | R462
101 | RES | 110-0003138 |  | 0402,27R0,1/16W,1% | VISHAY_T | CRCW040227R0FKED | 2 | R469, R470
102 | RES | 110-0003135 |  | 0402,18R2,1/16W,1% | VISHAY_T | CRCW040218R2FKED | 2 | R47, R360
103 | RES | 110-0002038 |  | 0402,470K,1/16W,1% | NIC | NRC04F4703TRF | 1 | R471
104 | RES | 110-0001979 |  | 0402,280K,1/16W,1% | NIC | NRC04F2803TRF | 1 | R472
106 | RES | 110-0003053 |  | 0402,3K16,1/10W,1% | PANASONIC | ERJ-2RKF3161X | 2 | R53, R54
107 | RES | 110-0001853 |  | 0402,0R00,JUMPER,1/16W | KOA | RK73Z1ETTP | 3 | R58, R73, R459
108 | RES | 110-0001962 |  | 0402,220R,1/16W,1% | KOA | RK73H1ETTP2200F | 3 | R60, R237, R238
109 | RES | 110-0001869 |  | 0402,100R,1/16W,1% | ROHM | MCR01MZPF1000 | 15 | R72, R111, R258, R259, R283, R288, R296, R300, R307, R308, R309, R331, R400, R401, R448
110 | RES | 110-0001983 |  | 0402,2K00,1/16W,1% | VISHAY_T | CRCW04022K00FKED | 4 | R88, R134, R336, R404
111 | FUSE | 152-0003075 |  | 0805,PTC RESET,0.1A,15VDC | BEL_FUSE | 0ZCE0010FF2G | 1 | RT1
112 | SWITCH | 150-0003112 |  | TACTILE,SPST-NO,0.05A,12V | E-SWITCH | TL3320AF100Q | 6 | S1, S2, S3, S4, S5, S6
113 | MEMORY | 142-0003128 |  | DDR2,SDRAM,2GB,800MHZ,60FBGA | MICRON | MT47H256M8EB-25E:C | 4 | U1, U4, U26, U27
114 | IC | 140-0001653 |  | SWITCH,PWR DIST,QUAD,16-SOIC | TI | TPS2054BD | 1 | U10
115 | IC | 140-0003118 |  | FLASH SPI,32MBIT,8WSON | WINBOND | W25Q32FVZPIG | 1 | U11
116 | IC | 140-0001576 |  | INVTR,SGLE,1INPUT,SC705 | TI | SN74LVC1G06DCKR | 1 | U12
117 | IC | 140-0003032 |  | PMIC FOR INTEL ATOM PROCESSOR | DIALOG_SEMI | DA6011-03HDA2 | 1 | U13
118 | IC | 140-0003126 |  | NON-INV,TRANSLTR,4BIT,14TSSOP | TI | TXS0104EPWR | 2 | U14, U36
119 | IC | 140-0003343 |  | INVTR,SCHMITT,TRIG,SOT23-5 | TI | SN74LVC1G14DBVR | 2 | U15, U16
120 | IC | 140-0001631 |  | REG,LDO,FIXED,3.3V,400MA,SOT23 | TI | TPS73633DBVR | 1 | U17
121 | IC | 140-0003168 |  | 2-INPUT,AND,GATE,SOT-23-5 | TI | SN74LVC1G08DBVR | 3 | U18, U19, U30
122 | TRANSMIT | 143-0003110 |  | SDVO-DVI VAST LANE | SIL_IMAG | SII1362ACLU | 1 | U2
123 | IC | 140-0001566 |  | ESD SOLUTION,4CH,W/CLAMP,6-SON | TI | TPD4S012DRYR | 3 | U20, U21, U23
124 | IC | 140-0003132 |  | USB TO EART,1CH,5V,SSOP | FTDI | FT230XS-R | 1 | U22
125 | IC | 140-0001562 |  | ESD PROTECTION,ARRAY,6CH,10-UQFN | TI | TPD6E001RSER | 1 | U24
126 | IC | 140-0001560 |  | ESD PROTECTION,ARRAY,2CH,SOT-5 | TI | TPD2E001DRL | 1 | U25
127 | IC | 140-0003101 |  | TEMP,SENSE,DIGITAL,W/TT,8MSOP | TI | LM95245CIMM/NOPB | 1 | U28
128 | IC | 140-0003124 |  | SWITCH,LOAD,ULOW,RDS,6-DSBGA | TI | TPS22922YZPR | 1 | U29
129 | AUDIO | 159-0003120 |  | CODEC,HD,2CH | REALTEK | ALC262-VD2-GR | 1 | U3
130 | TRANSIS | 132-0003109 |  | MOSFET,N/P-CH,12V,8-SOIC | VISHAY_T | SI7540DP-T1-E3 | 3 | U31, U32, U33
131 | IC | 140-0001625 |  | REG,LDO,500MA,8-SOIC | TI | TL5209DR | 1 | U34
132 | IC | 140-0003125 |  | REG,LDO,1.8V,0.2A,SOT23-5 | TI | TPS79318DBVR | 1 | U35
133 | IC | 140-0003649 |  | XLATR,QUAD,BI-DIREC,14-TSSOP | NXP | GTL2005PW,118 | 1 | U37
134 | IC | 140-0003127 |  | PROCESSOR,ATOM,1000MHZ,676-FCBGA | INTEL | CT80618005841AA-SLJ33 | 1 | U5
135 | IC | 140-0003134 |  | PLATFORM CONTROLLER HUB | INTEL | CS82TPCF-SLJ42 | 1 | U6
136 | IC | 140-0001520 |  | BUFF/DVR,NON-INVERT,SC705 | TI | SN74LVC1G07DCKR | 2 | U7, U8
137 | IC | 140-0001672 |  | TRANSCVR,PHY,10/100/1000 | ATHEROS | AR8031-AL1A | 1 | U9
138 | CRYSTAL | 245-0003350 |  | 14.31818MHZ,20PF | ECS | ECS-143-20-46X | 1 | Y1
139 | CRYSTAL | 245-0003349 |  | 25.00000MHZ,20PF | ECS | ECS-250-20-46X | 1 | Y3
140 | CRYSTAL | 145-0003173 |  | 32.768 KHZ,12.5PF,CYLINDER | CITIZEN | CFS308-32.768KDZF-UB | 1 | Y5
141 | RES | 110-0002124 |  | 0603,0R00,JUMPER,1/10W | PANASONIC | ERJ-3GEY0R00V | 2 | FB1, FB3
999 | DNI | 997-0001407 |  | DO NOT INSTALL | CCO | DNI | 221 | C11, C12, C120, C121, C3, C4, C21, C110, C111, C113, C5, C112, C9, C103, D1, D10, D8, F1, FB5, GH1, GH2, GH3, GH4, J5, J7, L1, MTG1, MTG2, MTG3, MTG4, R119, R143, R144, R178, R198, R223, R239, R240, R278, R279, R301, R302, R314, R316, R328, R445, R446, R154, R155, R156, R157, R158, R159, R160, R161, R162, R163, R170, R177, R217, R218, R219, R220, R221, R222, R226, R227, R230, R232, R233, R318, R319, R325, R326, R335, R342, R343, R366, R384, R385, R402, R423, R429, R434, R461, R622,TP25, Y2, Y4, Y6, R56, R57, R68, R69, R78, R80, R81, R83, R87, R91, R93, R94, R95, R96, R98, R99, R100, R102, R103, R104, R109, R110, R113, R120, R121, R123, R124, R125, R126, R127, R128, R129, R136, R137, R138, R139, R147, R148, R149, R150, R151, R152,R621, R418, R44, R52, R63, R76, R172, R183, R228, R261, R311, R410, R450, R627, R628, R476, R59, R618, R619, R620, R97, R112, TP2, TP3, TP4, TP5, TP6, TP7, TP8, TP9, TP10, TP11, TP12, TP13, TP14, TP15, TP16, TP17, TP18, TP19, TP20, TP21, TP22, TP23, TP24

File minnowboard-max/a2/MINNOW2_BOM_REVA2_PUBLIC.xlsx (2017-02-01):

MINNOWBOARD2 Revised: Sunday, November 16, 2014
002-0004205 Revision: A2
Bill Of Materials November 16,2014 21:23:32
Item | Quantity | Reference | Part | PCB Footprint | TOLERANCE | VOLTAGE | CURRENT | CCO_NUMBER | INSTALLED
1 | 45 | R5,FB12,R18,R20,R22,R26,R36,R41,R42,R43,R46,R48,R51,R59,R65,R66,R72,R73,R74,R91,R98,R99,R103,R107,R108,R122,R127,R128,R129,R130,R151,R178,R192,R199,R216,R227,R243,R248,R261,R293,R300,R302,R306,R353,R354 | 0R0 | R0402 |  |  |  | 110-0001853
2 | 17 | R50,R82,R119,R147,R155,R156,R157,R173,R174,R180,R182,R273,R274,R309,R322,R324,R340 | 100K | R0402 | 1% |  |  | 110-0001859
3 | 45 | R2,R13,R14,R28,R29,R30,R55,R71,R75,R83,R84,R97,R102,R116,R118,R120,R123,R124,R133,R152,R163,R164,R165,R190,R191,R211,R220,R221,R231,R237,R254,R266,R267,R268,R276,R295,R296,R319,R323,R334,R335,R336,R337,R338,R339 | 10K0 | R0402 | 1% |  |  | 110-0001875
4 | 1 | R294 | 150K | R0402 |  |  |  | 110-0001904
5 | 20 | R6,R7,R15,R16,R17,R69,R78,R87,R94,R134,R162,R186,R187,R208,R234,R253,R259,R278,R288,R321 | 1K00 | R0402 |  |  |  | 110-0001923
6 | 2 | R188,R264 | 1M00 | R0402 |  |  |  | 110-0001941
7 | 2 | R68,R88 | 1R00 | R0402 |  |  |  | 110-0001950
8 | 1 | R206 | 200K | R0402 |  |  |  | 110-0001951
9 | 3 | R3,R90,R196 | 200R | R0402 |  |  |  | 110-0001954
10 | 4 | R60,R61,R256,R279 | 20K0 | R0402 |  |  |  | 110-0001957
11 | 2 | R100,R228 | 20R0 | R0402 |  |  |  | 110-0001959
12 | 3 | R179,R207,R252 | 220R | R0402 |  |  |  | 110-0001960
13 | 4 | R11,R12,R269,R270 | 22R0 | R0402 |  |  |  | 110-0001967
14 | 4 | R139,R140,R327,R332 | 240R | R0402 |  |  |  | 110-0001971
15 | 19 | R27,R44,R45,R47,R49,R52,R53,R54,R56,R57,R111,R113,R117,R171,R172,R177,R236,R257,R307 | 2K20 | R0402 |  |  |  | 110-0001984
16 | 1 | R193 | 2K70 | R0402 |  |  |  | 110-0001989
17 | 1 | R106 | 330R | R0402 |  |  |  | 110-0002000
18 | 1 | R142 | 33K | R0402 | 1% |  |  | 110-0002007
19 | 7 | R158,R159,R160,R175,R176,R181,R308 | 33R0 | R0402 |  |  |  | 110-0002012
20 | 1 | R136 | 40K2 | R0402 |  |  |  | 110-0002029
21 | 1 | R109 | 499K | R0402 |  |  |  | 110-0002045
22 | 1 | R215 | 4K02 | R0402 |  |  |  | 110-0002053
23 | 16 | R23,R32,R33,R125,R126,R137,R138,R143,R144,R149,R282,R283,R310,R325,R326,R333 | 4K70 | R0402 |  |  |  | 110-0002058
24 | 2 | R146,R148 | 4K75 | R0402 |  |  |  | 110-0002067
25 | 5 | R8,R9,R10,R19,R21 | 51R0 | R0402 | 1% |  |  | 110-0002078
26 | 3 | R104,R197,R224 | 69R8 | R0402 |  |  |  | 110-0002104
27 | 14 | FB7,FB8,FB9,FB10,R204,R222,R230,R251,R263,R265,R275,R277,R286,R297 | 0R00 | R0603 |  |  |  | 110-0002124
28 | 1 | R80 | 1R00 | R0603 |  |  |  | 110-0002140
29 | 1 | R205 | 0R00 | R0805 |  |  |  | 110-0002166
30 | 1 | R226 | 37K4 | R0402 |  |  |  | 110-0002543
31 | 3 | R24,R150,R225 | 12K1 | R0402 |  |  |  | 110-0002560
32 | 3 | R38,R39,R213 | 150R | R0402 |  |  |  | 110-0002631
33 | 2 | R202,R244 | 18K7 | R0402 |  |  |  | 110-0002725
34 | 1 | R153 | 27K4 | R0402 |  |  |  | 110-0002726
35 | 5 | R37,R64,R81,R89,R320 | 10R0 | R0402 |  |  |  | 110-0003033
36 | 1 | R200 | 2K43 | R0402 | 1% |  |  | 110-0003048
37 | 5 | R238,R240,R241,R242,R258 | 49R9 | R0402 |  |  |  | 110-0003059
38 | 1 | R145 | 0R01 | R0805 | 1% |  |  | 110-0003167
39 | 1 | R34 | 6K04 | R0402 |  |  |  | 110-0003781
40 | 2 | R198,R245 | 6K98 | R0402 |  |  |  | 110-0003933
41 | 1 | R132 | 2R20 | R1206 |  |  |  | 110-0004465
42 | 2 | R271,R290 | 2R20 | R0603 |  |  |  | 110-0004466
43 | 2 | R291,R298 | 4R70 | R0603 |  |  |  | 110-0004467
44 | 2 | R101,R201 | 16R9 | R0402 |  |  |  | 110-0004468
45 | 1 | R284 | 29R4 | R0402 |  |  |  | 110-0004470
46 | 2 | R304,R305 | 30R0 | R0402 |  |  |  | 110-0004471
47 | 2 | R77,R185 | 45R3 | R0402 |  |  |  | 110-0004472
48 | 1 | R214 | 47R5 | R0402 |  |  |  | 110-0004473
49 | 1 | R255 | 73R2 | R0402 |  |  |  | 110-0004474
50 | 1 | R281 | 162R | R0402 |  |  |  | 110-0004475
51 | 3 | R217,R218,R239 | 402R | R0402 |  |  |  | 110-0004476
52 | 1 | R212 | 1K24 | R0402 |  |  |  | 110-0004478
53 | 2 | R95,R96 | 1K91 | R0402 |  |  |  | 110-0004479
54 | 1 | R280 | 23R2 | R0402 |  |  |  | 110-0004480
55 | 1 | R92 | 2K32 | R0402 |  |  |  | 110-0004481
56 | 1 | R105 | 2K49 | R0402 |  |  |  | 110-0004482
57 | 1 | R70 | 2K55 | R0402 |  |  |  | 110-0004483
58 | 2 | R85,R250 | 2K61 | R0402 |  |  |  | 110-0004484
59 | 2 | R203,R229 | 3K83 | R0402 |  |  |  | 110-0004489
60 | 1 | R25 | 9K53 | R0402 |  |  |  | 110-0004490
61 | 2 | R67,R86 | 11K0 | R0402 |  |  |  | 110-0004493
62 | 1 | R35 | 23K7 | R0402 |  |  |  | 110-0004494
63 | 3 | R194,R246,R247 | 80K6 | R0402 |  |  |  | 110-0004496
64 | 1 | R131 | 121K | R0402 |  |  |  | 110-0004497
65 | 1 | R135 | 143K | R0402 |  |  |  | 110-0004498
66 | 1 | R195 | 169K | R0402 |  |  |  | 110-0004499
67 | 1 | R76 | 10M0 | R0402 |  |  |  | 110-0004500
68 | 1 | R40 | 357R | R0402 | 1% |  |  | 110-0004695
69 | 24 | R311,R312,R313,R314,R315,R316,R317,R318,R328,R329,R330,R331,R341,R342,R343,R344,R345,R346,R347,R348,R349,R350,R351,R352 | 36R0 | R0402 | 1% |  |  | 110-0004790
70 | 1 | R63 | 2K67 | R0402 | 1% |  |  | 110-0005198
71 | 1 | R93 | 2K21 | R0402 | 1% |  |  | 110-0005199
72 | 2 | R262,R285 | NTC-10K | R0402 |  |  |  | 113-0004491
73 | 2 | R272,R287 | NTC-470K | R0402 |  |  |  | 113-0004492
74 | 11 | C10,C11,C12,C13,C35,C47,C173,C177,C178,C179,C180 | 0.01uF | C0402 |  | 25V |  | 123-0001038
75 | 2 | C40,C59 | 0.047uF | C0402 | 10% | 16V |  | 123-0001044
76 | 106 | C1,C3,C4,C5,C14,C15,C17,C18,C20,C22,C25,C29,C30,C31,C32,C38,C41,C50,C51,C52,C53,C54,C55,C56,C58,C60,C65,C70,C71,C72,C73,C82,C84,C92,C93,C94,C96,C104,C105,C122,C124,C131,C133,C136,C138,C139,C153,C154,C155,C158,C165,C167,C168,C191,C192,C202,C203,C205,C206,C207,C208,C210,C212,C232,C234,C235,C237,C254,C275,C277,C283,C284,C287,C288,C289,C291,C293,C300,C301,C306,C307,C309,C311,C320,C323,C327,C329,C332,C337,C339,C343,C344,C345,C346,C347,C348,C349,C350,C351,C352,C353,C354,C355,C356,C357,C375 | 0.1uF | C0402 |  | 25V |  | 123-0001056
77 | 70 | C2,C26,C27,C34,C37,C44,C46,C57,C97,C113,C116,C117,C160,C163,C170,C171,C172,C174,C181,C182,C183,C193,C194,C195,C196,C197,C198,C199,C200,C213,C214,C215,C216,C217,C218,C219,C220,C221,C222,C223,C236,C239,C242,C243,C244,C245,C246,C255,C256,C257,C258,C259,C260,C261,C262,C263,C264,C265,C266,C271,C272,C273,C274,C276,C285,C286,C292,C338,C340,C341 | 1.0uF | C0402 |  | 16V |  | 123-0001066
78 | 4 | C48,C184,C189,C226 | 1000pF | C0402 |  | 50V |  | 123-0001069
79 | 1 | C49 | 10pF | C0402 |  | 50V |  | 123-0001076
80 | 2 | C42,C43 | 18pF | C0402 |  | 50V |  | 123-0001082
81 | 2 | C270,C296 | 2200pF | C0402 |  | 50V |  | 123-0001099
82 | 1 | C63 | 220pF | C0402 |  | 50V |  | 123-0001101
83 | 2 | C106,C152 | 22pF | C0402 |  | 50V |  | 123-0001102
84 | 5 | C119,C175,C176,C252,C253 | 27pF | C0402 |  | 50V |  | 123-0001107
85 | 1 | C228 | 33pF | C0402 |  | 50V |  | 123-0001110
86 | 1 | C188 | 470pF | C0402 |  | 50V |  | 123-0001113
87 | 3 | C157,C238,C240 | 4.7uF | C0603 | 10% | 10V |  | 123-0001144
88 | 59 | C7,C21,C66,C67,C68,C74,C75,C78,C79,C80,C81,C83,C86,C88,C89,C90,C91,C98,C99,C101,C102,C103,C120,C121,C126,C127,C128,C137,C140,C141,C164,C201,C224,C225,C248,C249,C268,C269,C278,C279,C280,C281,C282,C294,C295,C297,C298,C303,C304,C305,C308,C312,C313,C314,C315,C316,C317,C328,C334 | 22uF | C0805 |  | 16V |  | 123-0001176
89 | 2 | C149,C150 | 2.2uF | C0402 |  | 10V |  | 123-0003258
90 | 5 | C45,C190,C204,C325,C342 | 0.22uF | C0402 |  | 16V |  | 123-0003769
91 | 1 | C358 | 4700PF | C0402 |  | 25V |  | 123-0004458
92 | 2 | C187,C227 | 560PF | C0402 |  | 50V |  | 123-0004461
93 | 29 | C6,C8,C19,C28,C95,C107,C115,C118,C151,C156,C159,C162,C230,C241,C247,C250,C251,C267,C299,C302,C324,C326,C335,C336,C359,C360,C361,C362,C367 | 10uF | C0603 | 20% | 16V |  | 123-0004691
94 | 32 | C108,C109,C110,C111,C123,C125,C130,C132,C134,C135,C142,C143,C144,C145,C146,C147,C318,C319,C321,C322,C330,C333,C363,C364,C365,C366,C368,C369,C370,C371,C372,C373 | 0.47uF | C0603 | 10% | 10V |  | 123-0004765
95 | 4 | C36,C39,C61,C62 | 0.033uF | C0603 | 10% | 25V |  | 123-0004777
96 | 4 | C76,C77,C87,C129 | 330uF | C7343 | 20% | 2V |  | 123-0005035
97 | 1 | C185 | 68pF | 402 |  | 50V |  | 123-0005081
98 | 2 | L9,L10 | 0.33uH | CHOKE_PT5D1MM_SMD |  |  | 20A | 125-0004453
99 | 1 | L11 | PIND-1U-SMD-0603-11A-MAG-X | CHOKE_PT6D2MM_SMD_2P |  |  |  | 125-0004454
100 | 1 | L8 | IND-4.7U-S-X | CHOKE_NLC252018_SMD_2P |  |  |  | 125-0004455
101 | 1 | L3 | PIND-2.2U-SMD-0603-8A-MAG | CHOKE_PT6D2MM_SMD_2P |  |  |  | 125-0004501
102 | 1 | L7 | FB_220R_2.2A | SM-7351-IND-0603 | 25% |  |  | 126-0001418
103 | 1 | FB3 | FB_600R_1.3A | FB0603 |  |  |  | 126-0001423
104 | 10 | FB1,FB2,L4,FB4,L5,FB5,L6,FB11,L12,L13 | FB_120R_3A | FB0603 |  |  |  | 126-0004457
105 | 2 | L1,L2 | BKP2125HS221-T | FB0805 |  |  | 2A | 126-0004781
106 | 4 | CHOKE1,CHOKE2,CHOKE3,CHOKE4 | ACM2012-900 | CHOKE4_0805 |  |  | 400mA | 127-0004392
107 | 5 | D3,D4,D6,D11,D12 | BAT54A-S | BAT54_132_2 |  |  |  | 130-0004403
108 | 2 | Q2,Q9 | BAV99-7-F-S-X | SOT23_3L |  |  |  | 130-0004413
109 | 2 | D7,D9 | D5V0L1B2LP-7B | 2-XFDFN |  |  |  | 130-0004506
110 | 3 | D5,D8,D10 | BAT54C-S | BAT54_132_2 |  |  |  | 130-0004793
111 | 2 | D1,D2 | LTST-C191TBKT | LED_0603 |  |  |  | 131-0004505
112 | 1 | Q8 | BSS138 | SOT23_GSD |  |  |  | 132-0002268
113 | 1 | U36 | IRF9321 | SOP8_W150_PT50 |  |  |  | 132-0004414
114 | 2 | U11,U12 | SK8603190L | HSO8-F4-B |  |  |  | 132-0004418
115 | 5 | Q7,Q10,Q11,Q12,Q14 | 2N7002K | SOT23_GSD |  |  |  | 132-0004419
116 | 1 | Q4 | MMBT3904 | SOT23_EBC |  |  |  | 132-0004420
117 | 3 | Q5,Q6,Q13 | RXR035N03 | SOT23_GDS_2 |  |  |  | 132-0004421
118 | 2 | U31,U34 | FDMS3660S | PQFN8 |  |  |  | 132-0004423
119 | 2 | Q1,Q3 | MBT3904 | SOT-363 |  |  |  | 132-0004425
120 | 1 | U23 | TPD2E001 | U_5_DRL |  |  |  | 140-0001560
121 | 1 | U22 | TPD6E001 | U_10_RSE |  |  |  | 140-0001562
122 | 2 | U8,U9 | TPD4S012 | U_6_DRY |  |  |  | 140-0001566
123 | 2 | U26,U30 | 74LVC1G08DBVR | SOT23-5 |  |  |  | 140-0003168
124 | 3 | U25,U28,U39 | SN74LVC1G14DBVR | SOT23-5 |  |  |  | 140-0003343
125 | 1 | U2 | TPD12S016PW | SSOP24_256P_222LS |  |  |  | 140-0004333
126 | 1 | U29 | TPD4USB30 | FPC_4P10_R_1 |  |  |  | 140-0004396
127 | 1 | U13 | NB670 | FCQFN16_RT7290A_NB669 |  |  |  | 140-0004416
128 | 1 | U35 | NCT3012S-X | ESOP8_W150_PT50-90X90 |  |  |  | 140-0004417
129 | 1 | U27 | ISL95837HRZ-T | QFN40_PT04-92HD89C_1 |  |  |  | 140-0004422
130 | 1 | U37 | NB675-X | QFN21_NB675 |  |  |  | 140-0004424
131 | 1 | U33 | M24C02-WMN6TP-X | SOP8_W150_PT50 |  |  |  | 140-0004507
132 | 1 | LAN1 | RTL8111GS-CG-X | QFN32_PT04_NCP81102 |  |  |  | 140-0004509
133 | 1 | U38 | APL5912KAC-TRGS-X | SOP8_W150_PT50_3X2D5MM |  |  |  | 140-0004525
134 | 2 | U21,U24 | APL5933 | SOP8_W150_PT50-104X120 |  |  |  | 140-0004526
135 | 1 | U1 | SN74AUP1G34 | SOT23-5 |  |  |  | 140-0004540
136 | 2 | U5,U6 | TXS0102YZP | DSBGA-8 |  |  |  | 140-0004571
137 | 8 | U7,U10,U14,U15,U16,U17,U18,U19 | TXS0104EYZT | DSBGA-12 |  |  |  | 140-0004575
138 | 1 | U4 | TS3A27518EZQS | bga24_E5_P5_3x3 |  |  |  | 140-0004579
139 | 1 | CPU1 | BAYTRAIL_I | FCBGA-1170 |  |  |  | 140-0004628
140 | 1 | U20 | NCP606 | DFN6_3x3P3MM |  |  | 500mA | 140-0004677
141 | 1 | U32 | TPS2066DR | so8-25x75 |  |  |  | 140-0004778
142 | 4 | MEM1,MEM2,MEM3,MEM4 | MICRON MT41K256M16HA | FBGA96_DDR3 |  |  |  | 142-0002686
143 | 1 | U3 | MICRON N25Q064A | so8_w200 |  |  |  | 142-0004364
144 | 1 | Y1 | 32.768KHz, ABRACON | 2-SMD |  |  |  | 145-0004789
145 | 2 | Y2,Y3 | 25.00MHz | XTAL-FSX3M_4P_SMD |  |  |  | 145-0004792
146 | 1 | F1 | FUSE-2A-08-LR-X | FUSE_0805 |  |  |  | 152-0001482
147 | 1 | P2 | SCHA5B0200 | SD-MICRO-SCHA5B0300 |  |  |  | 158-0001269
148 | 1 | P1 | microHDMI_TH | CONN19_HDMI-1 |  |  |  | 158-0004513
149 | 1 | J10 | 5177985-2 | SMT-5177985-2 |  |  |  | 158-0004534
150 | 1 | SW1 | B3F-1000 | SM-SW-SPST-4-4 |  |  |  | 250-0002256
151 | 1 | J9 | RAPC712 | RAPC712 |  |  |  | 258-0001330
152 | 1 | J3 | 470804005 | SATA_RA |  |  |  | 258-0003610
153 | 1 | J8 | RJ-45 Gigabit | 6605814-6 |  |  |  | 258-0003669
154 | 1 | USB1 | DUAL_USB_2.0_3.0 | usb13_dual |  |  |  | 258-0004503
155 | 1 | J1 | HEADER 4x2 | HDR2x4 |  |  |  | 258-0004612
156 | 1 | J4 | SIP6_RA | SIP6 |  |  |  | 258-0004869
157 | 1 | JP1 | HDR-26 | HDR2x13 |  |  |  | 258-0005019
158 | 1 | MP1 | GDT-X8 | SMT_HEATSINK |  |  |  | 356-0005295
159 | 68 | SEE DNI PARTS EXPANDED LIST BELOW |  |  |  |  |  | DO NOT INSTALL
DNI PARTS EXPANDED LIST
Item | Quantity | Reference | Part | PCB Footprint | TOLERANCE | VOLTAGE | CURRENT | CCO_NUMBER | INSTALLED
1 | 6 | R121,R166,R167,R168,R232,R235 | 0R0 | R0402 |  |  |  | 110-0001853 | DNI
2 | 5 | R154,R292,R299,R301,R303 | 100K | R0402 | 1% |  |  | 110-0001859 | DNI
3 | 11 | R31,R112,R114,R169,R170,R183,R189,R209,R210,R219,R260 | 10K0 | R0402 | 1% |  |  | 110-0001875 | DNI
4 | 1 | R79 | 15K | R0402 |  |  |  | 110-0001909 | DNI
5 | 2 | R233,R289 | 1K00 | R0402 |  |  |  | 110-0001923 | DNI
6 | 1 | R141 | 200K | R0402 |  |  |  | 110-0001951 | DNI
7 | 1 | R161 | 20K0 | R0402 |  |  |  | 110-0001957 | DNI
8 | 3 | R1,R58,R115 | 2K20 | R0402 |  |  |  | 110-0001984 | DNI
9 | 1 | R110 | 499K | R0402 |  |  |  | 110-0002045 | DNI
10 | 1 | R4 | 4K70 | R0402 |  |  |  | 110-0002058 | DNI
11 | 1 | R223 | 69R8 | R0402 |  |  |  | 110-0002104 | DNI
12 | 1 | R184 | 402R | R0402 |  |  |  | 110-0004476 | DNI
13 | 2 | R62,R249 | 649R | R0402 |  |  |  | 110-0004477 | DNI
14 | 8 | C85,C100,C112,C114,C166,C209,C231,C290 | 0.1uF | C0402 |  | 25V |  | 123-0001056 | DNI
15 | 1 | C33 | 1.0uF | C0402 |  | 16V |  | 123-0001066 | DNI
16 | 1 | C310 | 100pF | C0402 |  | 50V |  | 123-0001074 | DNI
17 | 2 | C69,C374 | 10pF | C0402 |  | 50V |  | 123-0001076 | DNI
18 | 2 | C9,C23 | 150pF | C0402 |  | 50V |  | 123-0001079 | DNI
19 | 2 | C24,C229 | 2200pF | C0402 |  | 50V |  | 123-0001099 | DNI
20 | 2 | C64,C186 | 330pF | C0402 |  | 50V |  | 123-0001109 | DNI
21 | 5 | C148,C161,C169,C211,C233 | 8200pF | C1808 |  | 1000V |  | 123-0004408 | DNI
22 | 1 | C16 | 150pF | C1808 |  | 1000V |  | 123-0004415 | DNI
23 | 1 | C331 | 3.3PF | C0402 |  | 25V |  | 123-0004462 | DNI
24 | 1 | FB6 | FB_120R_3A | FB0603 |  |  |  | 126-0004457 | DNI
25 | 3 | J5,J6,J7 | JUMPER | SIP2 |  |  |  | 258-0002513 | DNI
26 | 1 | J2 | SIP2_FAN | WALL2_100LS |  |  |  | 258-0004524 | DNI
27 | 1 | BAT1 | COIN BATTERY, BR-1225 | N/A |  | 3V |  | 353-0003072 | DNI
28 | 1 | BH1 | BATT HOLDER, BS-1225-PC | BATT3_190X610 |  | 3V |  | 353-0003073 | DNI

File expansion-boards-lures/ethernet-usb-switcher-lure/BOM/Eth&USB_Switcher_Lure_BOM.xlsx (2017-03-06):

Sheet: Project
Ethernet&USB remote switcher
Mouser # | Mfr. # | Manufacturer | Desc. | RoHS | Lifecycle | Customer Part # | Order Qty. | Price (USD)
755-BA033CC0FP-E2 | BA033CC0FP-E2 | ROHM Semiconductor | LDO Voltage Regulators REG 1A 3.3V | RoHS Compliant |  |  | 1 | $1.10
279-CBT25J10K | CBT25J10K | TE Connectivity | Carbon Composition Resistors 10 KOhms 1/4W 250V | RoHS Compliant |  |  | 2 | $0.16
279-CBT25J68R | CBT25J68R | TE Connectivity | Carbon Composition Resistors 68 Ohms 1/4W 250V | RoHS Compliant |  |  | 1 | $0.29
610-2N2222 | 2N2222 | Central Semiconductor | Bipolar Transistors - BJT NPN Silicon | RoHS Compliant |  |  | 4 | $1.79
696-SLX-LX5093ID | SLX-LX5093ID | Lumex | Standard LEDs - Through Hole 5mm LED Lamps | RoHS Compliant |  |  | 1 | $0.06
512-1N4001 | 1N4001 | Fairchild Semiconductor | Rectifiers Vr/50V Io/1A T/R | RoHS Compliant |  |  | 3 | $0.16
77-VJ1206Y104KXJPBC | VJ1206Y104KXJPW1BC | Vishay | Multilayer Ceramic Capacitors MLCC - SMD/SMT 1206 0.1uF 16volts X7R 10% | RoHS Compliant |  |  | 1 | $0.10
647-UMA1C4R7MCD2TP | UMA1C4R7MCD2TP | Nichicon | Aluminum Electrolytic Capacitors - Leaded 4.7UF 16V 85c | RoHS Compliant |  |  | 2 | $0.12
647-UFG1C470MEM | UFG1C470MEM | Nichicon | Aluminum Electrolytic Capacitors - Leaded 16volts 47uF 85c 6.3x11 2.5LS | RoHS Compliant |  |  | 1 | $0.45
750-1N4001T-G | 1N4001T-G | Comchip Technology | Rectifiers 1A 50V Rectifier Diode | RoHS Compliant |  |  | 2 | $0.24
769-TXD2-3V | TXD2-3V | Panasonic | Low Signal Relays - PCB 2 Form C 2A 30VDC 3VDC | RoHS Compliant |  |  | 6 | $3.77
512-2N3904BU | 2N3904BU | Fairchild Semiconductor | Bipolar Transistors - BJT NPN Transistor General Purpose | RoHS Compliant |  |  | 4 | $0.17
538-43202-8816 | 43202-8816 | Molex | Modular Connectors / Ethernet Connectors RA L-PRO MOD JCK SHLDED FNT POS | RoHS Compliant |  |  | 2 | $2.55
571-292304-1 | 292304-1 | TE Connectivity | USB Connectors 4P 'B' RECEPTACLE | RoHS Compliant |  |  | 1 | $1.70
571-292303-3 | 292303-3 | TE Connectivity | USB Connectors TYPE A R/A RCPT ASSY THRU HOLE | RoHS Compliant |  |  | 1 | $1.21
855-M20-7831346 | M20-7831346 | Harwin | Headers & Wire Housings 13+13 DIL VERTICAL SOCKET TIN | RoHS Compliant |  |  | 1 | $2.36
490-PJ-002B | PJ-002B | CUI Inc. | DC Power Connectors Power Jacks | RoHS Compliant | New At Mouser |  | 1 | $0.93

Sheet: Reference
RefDes | Name | Value | Part | Manufacturer | Quantity | Datasheet
3V | BA033CC0FP-E2 | 3.3V | Part 1 |  | 1
5V | UA78M05CKVURG3 | 5V | Part 1 |  | 1 | http://www.mouser.com/ds/2/405/ua78m05-534325.pdf
C1 | CAP100RP | 47uF | Part 1 |  | 1
C2 | CAP100RP | 4.7uF | Part 1 |  | 1
C3 | CAP100RP | 4.7uF | Part 1 |  | 1
C4 | CAP_1206 | 0.1uF | Part 1 |  | 1
D1 | DIODE | 1N4001 | Part 1 |  | 1
D2 | LED |  | Part 1 |  | 1
D3 | DIODE | 1N4001 | Part 1 |  | 1
D4 | DIODE | 1N4001 | Part 1 |  | 1
J1 | 43202-8816 |  | Part 1 |  | 1
J2 | 292304-1 |  | Part 1 | TE Connectivity | 1 | http://documents.tycoelectronics.com/commerce/DocumentDelivery/DDEController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
J3 | 292303-3 |  | Part 1 | TE Connectivity | 1 | http://documents.tycoelectronics.com/commerce/DocumentDelivery/DDEController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
J4 | PJ-002B |  | Part 1 |  | 1
J5 | 5-146253-4 |  | Part 1 |  | 1
J6 | 5-146253-1 |  | Part 1 |  | 1
J7 | 43202-8816 |  | Part 1 |  | 1
K1 | TXD2-3V |  | Part 1 |  | 1
K2 | TXD2-3V |  | Part 1 |  | 1
K3 | TXD2-3V |  | Part 1 |  | 1
K4 | TXD2-3V |  | Part 1 |  | 1
K5 | TXD2-3V |  | Part 1 |  | 1
K6 | TXD2-3V |  | Part 1 |  | 1
Q1 | 2N2222 |  | Part 1 |  | 1
Q2 | 2N2222 |  | Part 1 |  | 1
Q3 | 2N2222 |  | Part 1 |  | 1
Q4 | 2N2222 |  | Part 1 |  | 1
R1 | RES | 330 | Part 1 |  | 1
R9 | RES | 10k | Part 1 |  | 1
R10 | RES | 10k | Part 1 |  | 1
U2 | MBoardMaxHDR26 | 26pinHeader | Part 1 |  | 1

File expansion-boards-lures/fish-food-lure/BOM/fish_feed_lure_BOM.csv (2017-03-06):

RefDes | Value | Name | Manufacturer part | Manufacturer | Quantity | Link | Replacement
26pin | 929834-01-13 | 13 position pin strip | 929834-01-13 | 3M Electronic Solutions Division | 2 | http://www.mouser.com/ProductDetail/3M/929834-01-13/?qs=FRjC07T2dBSSXUzZuwV4UQ%3d%3d | http://www.mouser.com/ProductDetail/Wurth-Electronics/61301311121/
D1 | Green LED | DIODE_0805 | SML-LXT0805GW-TRLumex |  | 1 | http://www.mouser.com/Search/ProductDetail.aspx
D2 | Red LED | DIODE_0805 | SML-LXT0805IW-TR | Lumex | 1 | http://www.mouser.com/Search/ProductDetail.aspx
R1 | 180 ohms | RES_0805 ERJ-6GEYJ181V | ERJ-6GEYJ181V | Panasonic | 1 | http://www.mouser.com/Search/ProductDetail.aspx
R2 | 68 ohms | RES_0805 SG73S2ATTD680J | SG73S2ATTD680J | KOA Speer | 1 | http://www.mouser.com/Search/ProductDetail.aspx
ShroudedHeader | 61202621621 | Shrouded MAX / Turbot Compatible LSE | 61202621621 | Wurth Electronics | 1 | http://www.mouser.com/Search/ProductDetail.aspx

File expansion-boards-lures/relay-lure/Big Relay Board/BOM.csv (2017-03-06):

RefDes | Value | Name | Pattern | Manufacturer | Quantity | Datasheet
3.3V | 3.3V | BA033CC0FP-E2 | TO252-3(4)/10x6.6x2.28 | ROHM | 1
3pin5mm1 | BT1 | 1935174 | 3pin5mm | Phoenix Contact | 1
3pin5mm2 | BT2 | 1935174 | 3pin5mm | Phoenix Contact | 1
3pin9.52mm1 |  | ESPM03200 | 3pin9.52mm | Amphenol Pcd | 1
3pin9.52mm2 |  | ESPM03200 | 3pin9.52mm | Amphenol Pcd | 1
3pin9.52mm3 |  | ESPM03200 | 3pin9.52mm | Amphenol Pcd | 1
3pin9.52mm4 |  | ESPM03200 | 3pin9.52mm | Amphenol Pcd | 1
3pin9.52mm5 |  | ESPM03200 | 3pin9.52mm | Amphenol Pcd | 1
3pin9.52mm6 |  | ESPM03200 | 3pin9.52mm | Amphenol Pcd | 1
3pin9.52mm7 |  | ESPM03200 | 3pin9.52mm | Amphenol Pcd | 1
3pin9.52mm8 |  | ESPM03200 | 3pin9.52mm | Amphenol Pcd | 1
F1 |  | FUSE F1206A2R00FWTR\500 | RES_1206 | AVX | 1
J1 |  | PJ-002AH | PJ-002A | CUI | 1
J2 |  | 87758-02 | HDR-2x1T/2x2/2x4 | Molex | 1
J3 |  | 87758-02 | HDR-2x1T/2x2/2x4 | Molex | 1
J4 |  | 87758-02 | HDR-2x1T/2x2/2x4 | Molex | 1
J5 |  | 87758-02 | HDR-2x1T/2x2/2x4 | Molex | 1
K1 |  | G5LE-14-DC5 | G5LE | Omron | 1
K2 |  | G5LE-14-DC5 | G5LE | Omron | 1
K3 |  | G5LE-14-DC5 | G5LE | Omron | 1
K4 |  | G5LE-14-DC5 | G5LE | Omron | 1
K5 |  | G5LE-14-DC5 | G5LE | Omron | 1
K6 |  | G5LE-14-DC5 | G5LE | Omron | 1
K7 |  | G5LE-14-DC5 | G5LE | Omron | 1
K8 |  | G5LE-14-DC5 | G5LE | Omron | 1
OC1 |  | VO617A | DIP-4 | Vishay Semiconductors | 1 | http://www.vishay.com/doc?83666
OC2 |  | VO617A | DIP-4 | Vishay Semiconductors | 1 | http://www.vishay.com/doc?83666
OC3 |  | VO617A | DIP-4 | Vishay Semiconductors | 1 | http://www.vishay.com/doc?83666
OC4 |  | VO617A | DIP-4 | Vishay Semiconductors | 1 | http://www.vishay.com/doc?83666
OC5 |  | VO617A | DIP-4 | Vishay Semiconductors | 1 | http://www.vishay.com/doc?83666
OC6 |  | VO617A | DIP-4 | Vishay Semiconductors | 1 | http://www.vishay.com/doc?83666
OC7 |  | VO617A | DIP-4 | Vishay Semiconductors | 1 | http://www.vishay.com/doc?83666
OC8 |  | VO617A | DIP-4 | Vishay Semiconductors | 1 | http://www.vishay.com/doc?83666
RJ-1 |  | RJE01-660-01 | RJE01-660-01 | Amphenol | 1
RJ-2 |  | RJE01-660-01 | RJE01-660-01 | Amphenol | 1
ShroudedHeader |  | 61202621621 | Copy_of_shroudedheader26 | Wurth Electronics | 1
U1 |  | MMBD4148 | MMBD4148 | Fairchild | 1
U2 |  | MMBD4148 | MMBD4148 | Fairchild | 1
U3 |  | MMBD4148 | MMBD4148 | Fairchild | 1
U4 |  | MMBD4148 | MMBD4148 | Fairchild | 1
U5 |  | MMBD4148 | MMBD4148 | Fairchild | 1
U6 |  | MMBD4148 | MMBD4148 | Fairchild | 1
U7 |  | MMBD4148 | MMBD4148 | Fairchild | 1
U8 |  | MMBD4148 | MMBD4148 | Fairchild | 1
U9 |  | DS2482S-100 | SOIC-8/150mil | Maxim | 1 | http://datasheets.maxim-ic.com/en/ds/DS2482-100.pdf
U11 |  | OKI-78SR-5/1.5-W36H-C | OKI-78SR-5/1.5-W36H-C | Murata | 1
C1 | 4.7uF | CAP_0805 | CAP_0805 |  | 1
C2 | 4.7uF | CAP_0805 | CAP_0805 |  | 1
C3 | 0.1uF | CAP_0805 | CAP_0805 |  | 1
C4 | 4.7uF | CAP_0805 | CAP_0805 |  | 1
D1 | 1N4001 | DIODE | DO-35 |  | 1
LED1 |  | DIODE_0805 | DIO_0805 |  | 1
LED2 |  | DIODE_0805 | DIO_0805 |  | 1
LED3 |  | DIODE_0805 | DIO_0805 |  | 1
LED4 |  | DIODE_0805 | DIO_0805 |  | 1
LED5 |  | DIODE_0805 | DIO_0805 |  | 1
LED6 |  | DIODE_0805 | DIO_0805 |  | 1
LED7 |  | DIODE_0805 | DIO_0805 |  | 1
LED8 |  | DIODE_0805 | DIO_0805 |  | 1
Q1 |  | 2N2222 | TO-18 |  | 1
Q2 |  | 2N2222 | TO-18 |  | 1
Q3 |  | 2N2222 | TO-18 |  | 1
Q4 |  | 2N2222 | TO-18 |  | 1
Q5 |  | 2N2222 | TO-18 |  | 1
Q6 |  | 2N2222 | TO-18 |  | 1
Q7 |  | 2N2222 | TO-18 |  | 1
Q8 |  | 2N2222 | TO-18 |  | 1
R1 | Rup | RES_0805 | RES_0805 |  | 1
R2 | Rup | RES_0805 | RES_0805 |  | 1
R3 | 390 | RES_0805 | RES_0805 |  | 1
R4 | 180 | RES_0805 | RES_0805 |  | 1
R5 | 390 | RES_0805 | RES_0805 |  | 1
R6 | 180 | RES_0805 | RES_0805 |  | 1
R7 | 390 | RES_0805 | RES_0805 |  | 1
R8 | 180 | RES_0805 | RES_0805 |  | 1
R9 | 390 | RES_0805 | RES_0805 |  | 1
R10 | 180 | RES_0805 | RES_0805 |  | 1
R11 | 390 | RES_0805 | RES_0805 |  | 1
R12 | 180 | RES_0805 | RES_0805 |  | 1
R13 | 390 | RES_0805 | RES_0805 |  | 1
R14 | 180 | RES_0805 | RES_0805 |  | 1
R15 | 390 | RES_0805 | RES_0805 |  | 1
R16 | 180 | RES_0805 | RES_0805 |  | 1
R17 | 390 | RES_0805 | RES_0805 |  | 1
R18 | 180 | RES_0805 | RES_0805 |  | 1

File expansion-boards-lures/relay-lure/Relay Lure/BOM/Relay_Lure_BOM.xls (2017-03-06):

MinnowBoard MAX/Turbot Relay Lure
Mouser # | Mfr. # | Manufacturer | Desc. | RoHS | Lifecycle | Customer Part # | Order Qty. | Price (USD) | Ext.: (USD) | Direct Link
651-1935174 | 1935174 | Phoenix Contact | Fixed Terminal Blocks PT 1.5/3-5.0-H | RoHS Compliant |  |  | 4 | $0.52 | $2.08 | http://www.mouser.com/Search/ProductDetail.aspx?R=1935174virtualkey65100000virtualkey651-1935174
653-G5LE-14-DC5 | G5LE-14-DC5 | Omron | General Purpose Relays Power PCB Relay SPDT Sealed 5VDC | RoHS Compliant |  |  | 4 | $1.35 | $5.40 | http://www.mouser.com/Search/ProductDetail.aspx
610-2N2222 | 2N2222 | Central Semiconductor | Bipolar Transistors - BJT NPN Silicon | RoHS Compliant |  |  | 4 | $1.79 | $7.16 | http://www.mouser.com/Search/ProductDetail.aspx?R=2N2222virtualkey61000000virtualkey610-2N2222
855-M20-7831346 | M20-7831346 | Harwin | Headers & Wire Housings 13+13 DIL VERTICAL SOCKET TIN | RoHS Compliant |  |  | 1 | $2.36 | $2.36 | http://www.mouser.com/Search/ProductDetail.aspx
512-MMBD4148 | MMBD4148 | Fairchild Semiconductor | Diodes - General Purpose, Power, Switching High Cond Ult Fst Di | RoHS Compliant |  |  | 4 | $0.17 | $0.68 | http://www.mouser.com/Search/ProductDetail.aspx?R=MMBD4148virtualkey51210000virtualkey512-MMBD4148
652-CR0805JW-391ELF | CR0805-JW-391ELF | Bourns | Thick Film Resistors - SMD 390ohm 5% | RoHS Compliant By Exemption |  |  | 4 | $0.10 | $0.40 | http://www.mouser.com/Search/ProductDetail.aspx
78-VO617A | VO617A | Vishay | Transistor Output Optocouplers Phototransistor Out CTR 50-600% | RoHS Compliant |  |  | 4 | $0.60 | $2.40 | http://www.mouser.com/Search/ProductDetail.aspx?R=VO617Avirtualkey61370000virtualkey78-VO617A
667-ERJ-6GEYJ181V | ERJ-6GEYJ181V | Panasonic | Thick Film Resistors - SMD 0805 180ohms 5% Tol | RoHS Compliant By Exemption |  |  | 4 | $0.09 | $0.36 | http://www.mouser.com/Search/ProductDetail.aspx
696-SML-LXT0805IW | SML-LXT0805IW-TR | Lumex | Standard LEDs - SMD 0805 Thin PCB Red | RoHS Compliant |  |  | 4 | $0.35 | $1.40 | http://www.mouser.com/Search/ProductDetail.aspx

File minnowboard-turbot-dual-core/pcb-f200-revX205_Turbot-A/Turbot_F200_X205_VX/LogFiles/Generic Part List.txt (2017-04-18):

# Output for Turbot
# Generated 7/28/2015 1:50:33 PM
# Part Number	Cell	Symbol	Reference Designator	Partition
#-------------------------------------------------------------------
110-0001853	RES_1	R0402	Turbot_F200_X200
999-0000002	TEST_PAD_1	TP30-SMD	Turbot_F200_X200
123-0001056	CAP_1	C0402	Turbot_F200_X200
110-0004695	RES_2	R0402	Turbot_F200_X200
110-0002631	RES_1	R0402	Turbot_F200_X200
110-0001984	RES_1	R0402	Turbot_F200_X200
140-0004628	INTEL_ATOM_E3825_5C,INTEL_ATOM_E3825_5A,INTEL_ATOM_E3825_5B,INTEL_ATOM_E3825_5D,INTEL_ATOM_E3825_5E,INTEL_ATOM_E3825_5F,INTEL_ATOM_E3825_5G,INTEL_ATOM_E3825_5H,INTEL_ATOM_E3825_5K,INTEL_ATOM_E3825_5L,INTEL_ATOM_E3825_5M,INTEL_ATOM_E3825_5J,INTEL_ATOM_E3825_5I	FCBGA-1170	Turbot_F200_X200
110-0004476	RES_1	R0402	Turbot_F200_X200
110-0001875	RES_2	R0402	Turbot_F200_X200
4222-0059	74_1G14	SC70_5A	Turbot_F200_X200
110-0004480	RES_1	R0402	Turbot_F200_X200
130-0004403	BAT54A_2	BAT54_132_2	Turbot_F200_X200
110-0002058	RES_1	R0402	Turbot_F200_X200
110-0004470	RES_1	R0402	Turbot_F200_X200
110-0001859	RES_2	R0402	Turbot_F200_X200
110-0004475	RES_1	R0402	Turbot_F200_X200
123-0001038	CAP_NP	C0402	Turbot_F200_X200
110-0001923	RES_1	R0402	Turbot_F200_X200
110-0001960	RES_2	R0402	Turbot_F200_X200
123-0004408	CAP_NP	C1808	Turbot_F200_X200
258-0003610	SATA_HEADER_RA_0	SATA_RA	Turbot_F200_X200
110-0003059	RES_1	R0402	Turbot_F200_X200
258-0002513	JUMPER1x2_0	SIP2	Turbot_F200_X200
110-0004474	RES_1	R0402	Turbot_F200_X200
123-0001107	CAP_1	C0402	Turbot_F200_X200
110-0001957	RES_1	R0402	Turbot_F200_X200
123-0001082	CAP_1	C0402	Turbot_F200_X200
123-0001066	CAP_1	C0402	Turbot_F200_X200
110-0002078	RES_2	R0402	Turbot_F200_X200
353-0003073	BATTERY_2	BATT3_190X610	Turbot_F200_X200
130-0004793	DIODE_DUAL_BAT54C_S	BAT54_132_2	Turbot_F200_X200
110-0002104	RES_1	R0402	Turbot_F200_X200
110-0004500	RES_1	R0402	Turbot_F200_X200
123-0001076	CAP_1	C0402	Turbot_F200_X200
353-0003072	COIN_BATTERY_1	N/A	Turbot_F200_X200
145-0004792	XTAL_4P	XTAL-FSX3M_4P_SMD	Turbot_F200_X200
110-0001959	RES_1	R0402	Turbot_F200_X200
110-0001941	RES_1	R0402	Turbot_F200_X200
145-0004789	XTAL_2P	2-SMD	Turbot_F200_X200
110-0004473	RES_1	R0402	Turbot_F200_X200
110-0004468	RES_1	R0402	Turbot_F200_X200
110-0002053	RES_1	R0402	Turbot_F200_X200
4327-0010	NTB0104_QFN12	SOT1174_12A	Turbot_F200_X200
110-0004478	RES_1	R0402	Turbot_F200_X200
110-0001967	RES_1	R0402	Turbot_F200_X200
258-0004869	SIP6_RA	SIP6	Turbot_F200_X200
110-0004472	RES_1	R0402	Turbot_F200_X200
4327-0009	TXS0102_D8	SOT833_8A	Turbot_F200_X200
110-0002000	RES_1	R0402	Turbot_F200_X200
123-0001176	CAP_1	C0805	Turbot_F200_X200
999-0000003	TEST_PAD_1	TP30-SMD	Turbot_F200_X200
123-0004691	CAP_NP	C0603	Turbot_F200_X200
123-0001144	CAP_NP	C0603	Turbot_F200_X200
110-0002124	RES_1	R0603	Turbot_F200_X200
126-0004457	FB0805	FB0603	Turbot_F200_X200
126-0001423	INDUCTOR_1	FB0603	Turbot_F200_X200
999-0000004	UP_HOLE_CPU_HS	HOLE_C276D165PTB	Turbot_F200_X200
258-0004524	FAN_JUMPER1x2	WALL2_100LS	Turbot_F200_X200
356-0005295	UP_CPU_HEATSINK_SMALL	SMT_HEATSINK	Turbot_F200_X200
130-0004506	ESD_SOD_XFDFN_P	2-XFDFN	Turbot_F200_X200
142-0002686	MICRON_MT41K256M16HA	FBGA96_DDR3	Turbot_F200_X200
123-0004765	CAP_NP	C0603	Turbot_F200_X200
110-0001971	RES_1	R0402	Turbot_F200_X200
140-0004507	IC_SOP8_EEPROM_M24C02_WMN6TP_1	SOP8_W150_PT50	Turbot_F200_X200
123-0004462	CAP_1	C0402	Turbot_F200_X200
110-0004790	RES_2	R0402	Turbot_F200_X200
110-0004471	RES_1	R0402	Turbot_F200_X200
110-0002012	RES_2	R0402	Turbot_F200_X200
140-0001560	TPD2E001DRL_1	U_5_DRL	Turbot_F200_X200
140-0001562	TPD6E001RSE_1	U_10_RSE	Turbot_F200_X200
158-0001269	microSD_CONN_BOTTOM	SD-MICRO-SCHA5B0300	Turbot_F200_X200
127-0004392	COM_CHOKE_90_OHM	CHOKE4_0805	Turbot_F200_X200
2222-0016	CAP_VERT_HORIZ	C_0402G,C_0402H,C_0402C,C_0402D,C_0402F,C_0402J	Turbot_F200_X200
123-0004415	CAP_1	C1808	Turbot_F200_X200
140-0004333	TPD12S016_24TSSOP	SSOP24_256P_222LS	Turbot_F200_X200
158-0004513	CONN_HDMI_TYPED_TH	CONN19_HDMI-1	Turbot_F200_X200
126-0001418	BEAD_1	SM-7351-IND-0603	Turbot_F200_X200
1120-0119	RES_VERT_HORIZ	R_0402G,R_0402H,R_0402C,R_0402D,R_0402F,R_0402J	Turbot_F200_X200
132-0004419	2N7002K	SOT23_GSD	Turbot_F200_X200
140-0001566	PROT_TPD4S012_3	U_6_DRY	Turbot_F200_X200
126-0004781	BEAD_2	FB0805	Turbot_F200_X200
140-0004396	TPD4EUSB30_0	FPC_4P10_R_1	Turbot_F200_X200
258-0004503	USB_LPP_LPUSB1013_3	USB13_DUAL,usb13_dual	Turbot_F200_X200
152-0001482	FUSE_0	FUSE_0805	Turbot_F200_X200
4158-0037	TPS2052_D8HS	MSOP8A_HS_BV,MSOP8A_HS	Turbot_F200_X200
158-0004534	CONN_5177985_2	SMT-5177985-2	Turbot_F200_X200
140-0004540	SN74AUP1G34_DBV	SOT23-5	Turbot_F200_X200
110-0001954	RES_1	R0402	Turbot_F200_X200
4222-0046	74_1G08	SC70_5A	Turbot_F200_X200
258-0003669	CONN_RJ45_MAGJACK_GIGABIT	6605814-6	Turbot_F200_X200
140-0004509	RTL8111GS_0	QFN32_PT04_NCP81102	Turbot_F200_X200
125-0004455	INDUCTOR_IRON_1	CHOKE_NLC252018_SMD_2P	Turbot_F200_X200
110-0004482	RES_1	R0402	Turbot_F200_X200
4327-0008	NTB0104_QFN12	SOT1174_12A	Turbot_F200_X200
4318-0010	PCA9306_D8	VSSOP8A	Turbot_F200_X200
4356-0059	W25Q64B_D8	SO8_W200,SOIC8C,SOIC8C_SKT	Turbot_F200_X200
258-0004612	HEADER_4x2_1	HDR2X4,HDR2x4	Turbot_F200_X200
258-0005019	HDR13x2_0p1	HDR2X13,HDR2x13	Turbot_F200_X200
110-0001951	RES_1	R0402	Turbot_F200_X200
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

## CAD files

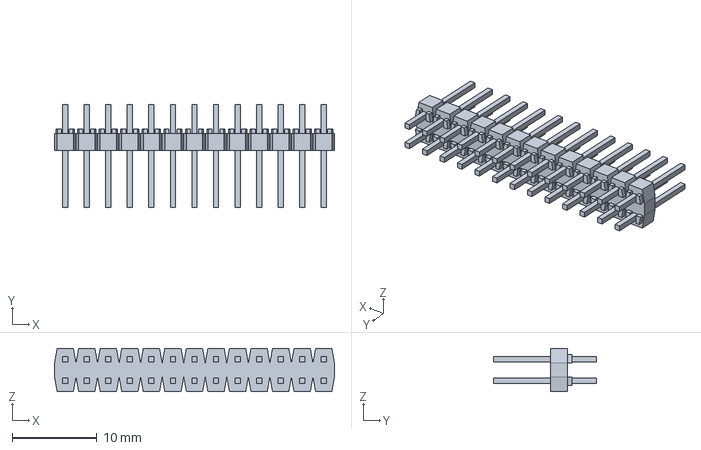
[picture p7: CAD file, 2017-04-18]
minnowboard-turbot-dual-core/pcb-f200-revX205_Turbot-A/STEPLibrary/HDR2X13_2p54mm.stp
33.0 x 12.2 x 5.08 mm

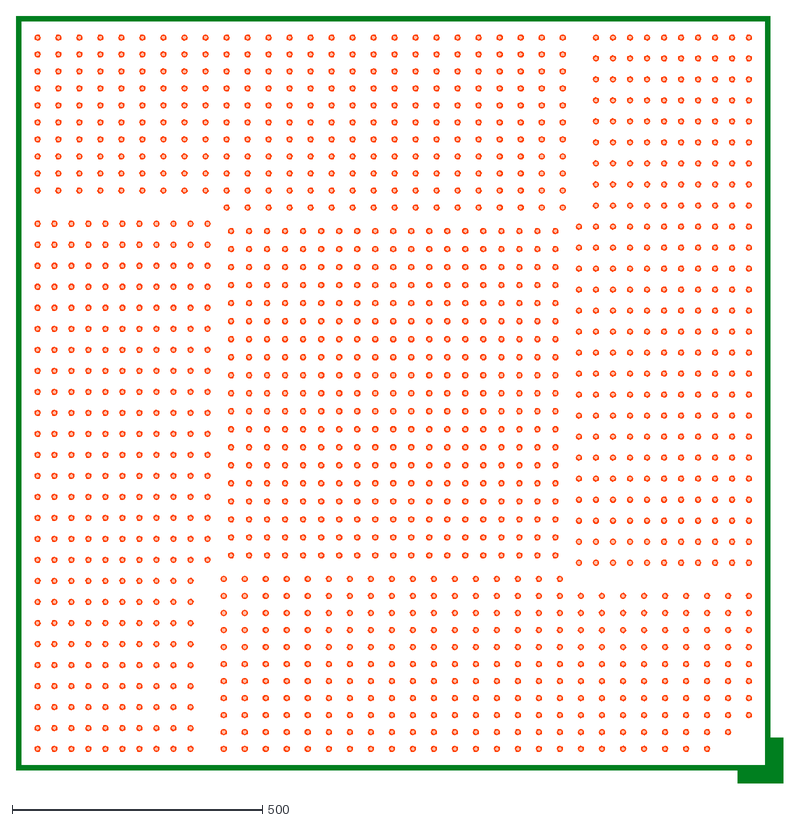
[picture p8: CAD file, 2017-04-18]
minnowboard-turbot-dual-core/pcb-f200-revX205_Turbot-A/Turbot_F200_X205_VX/Minnowmax_Central_Library/Output/TH_CONN184A_DDR.dxf
1533.0 x 1533.0

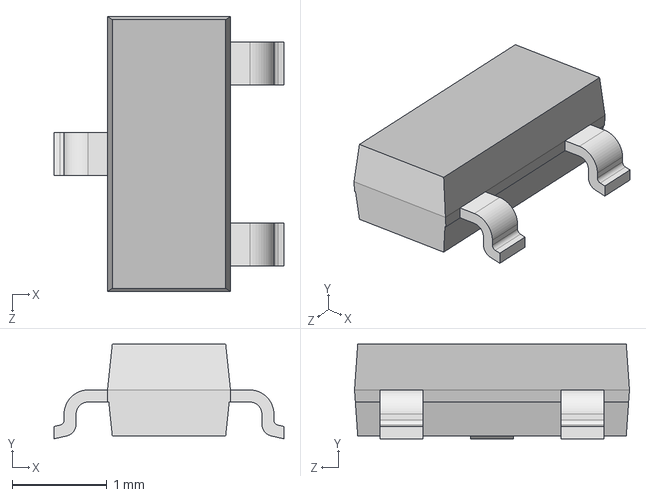
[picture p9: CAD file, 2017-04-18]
minnowboard-turbot-dual-core/pcb-f200-revX205_Turbot-A/Turbot_F200_X205_VX/PCB/Layout/3D/ImportedPartModels/SOT23.step
2.42 x 0.997 x 2.90 mm

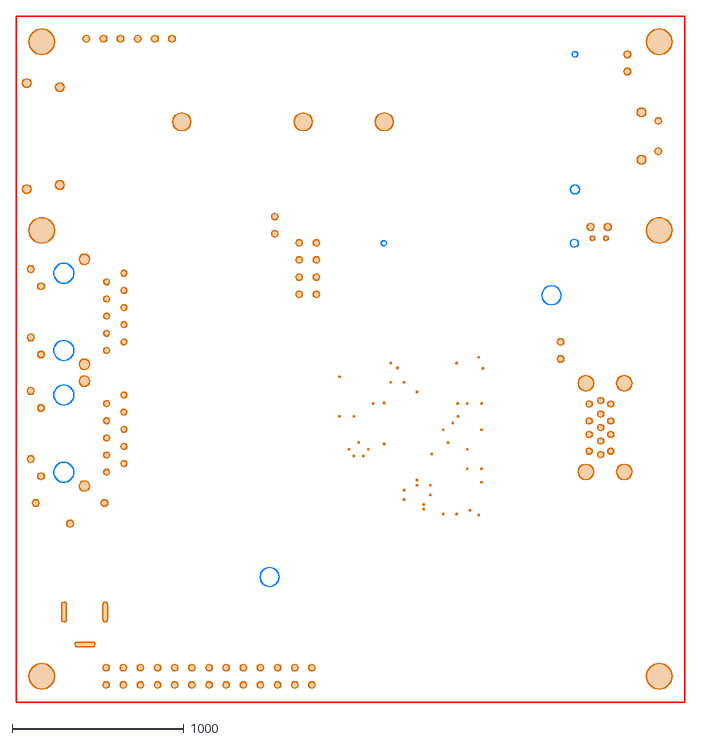
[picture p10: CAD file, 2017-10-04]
minnowboard-turbot-dual-E-Dual-and-Quadcore/F300_R201/Turbot-DualE_F300_Mounting_Part_Holes.dxf
3900.0 x 4000.0

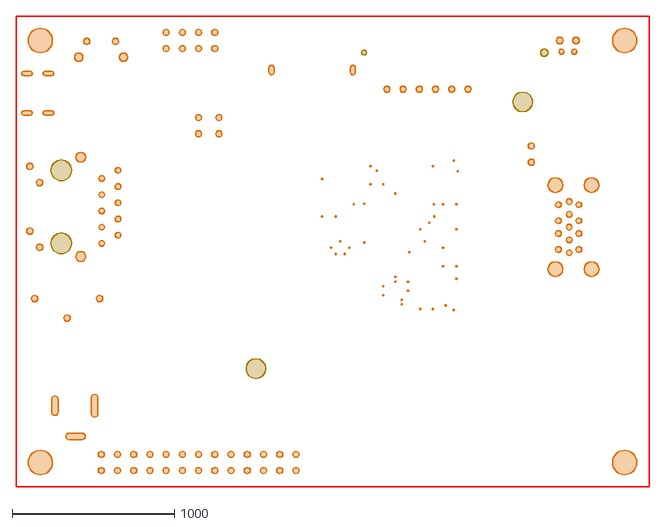
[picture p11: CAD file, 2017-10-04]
minnowboard-turbot-quad-core/F400_R302/TurbotB_F400.dxf
3900.0 x 2900.0

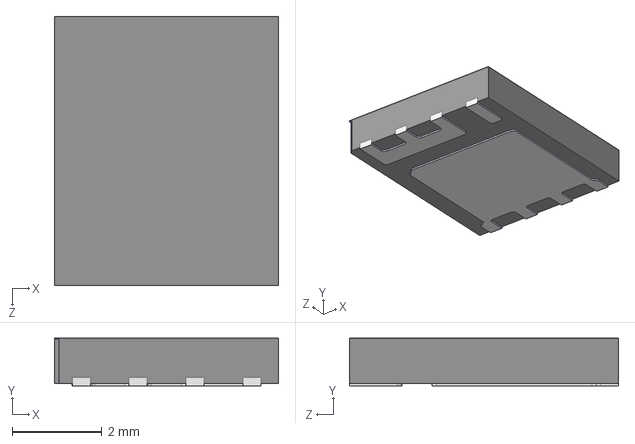
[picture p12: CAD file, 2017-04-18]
minnowboard-turbot-dual-core/pcb-f200-revX205_Turbot-A/STEPLibrary/PQFN5x6_V2.STEP
5.00 x 1.06 x 6.00 mm

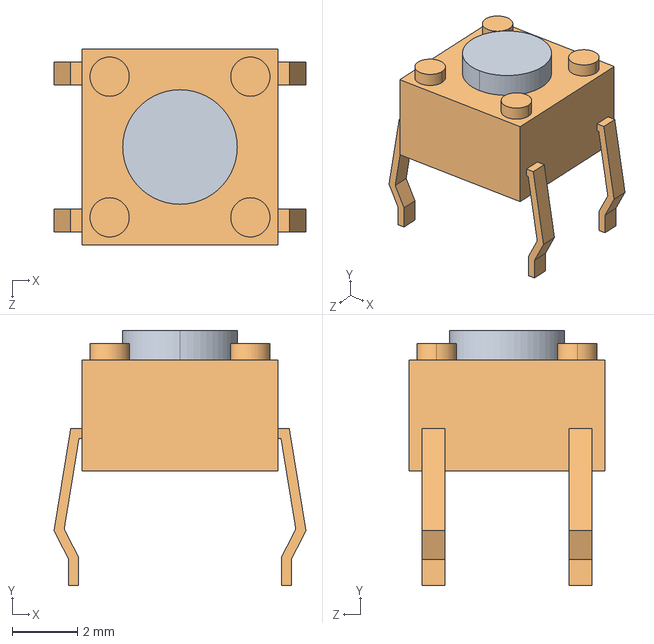
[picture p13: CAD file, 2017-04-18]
minnowboard-turbot-dual-core/pcb-f200-revX205_Turbot-A/Turbot_F200_X205_VX/PCB/Layout/3D/ImportedPartModels/B3F_1000.step
7.70 x 7.80 x 6.00 mm
B3F_1000_BUTTON
B3F_1000_BASE

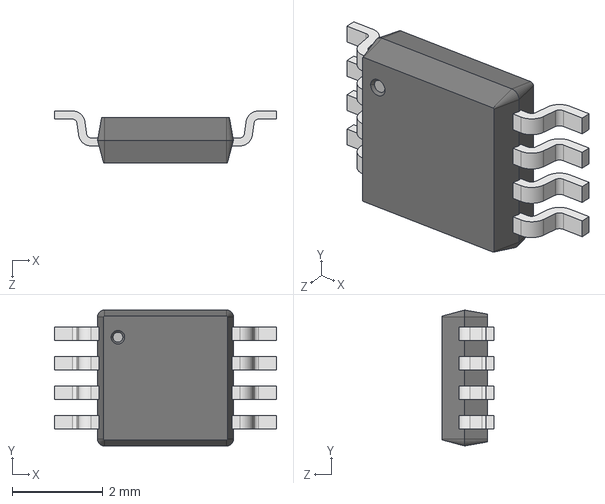
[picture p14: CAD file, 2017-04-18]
minnowboard-turbot-dual-core/pcb-f200-revX205_Turbot-A/STEPLibrary/MSOP8_3X3.step
4.90 x 3.00 x 1.15 mm

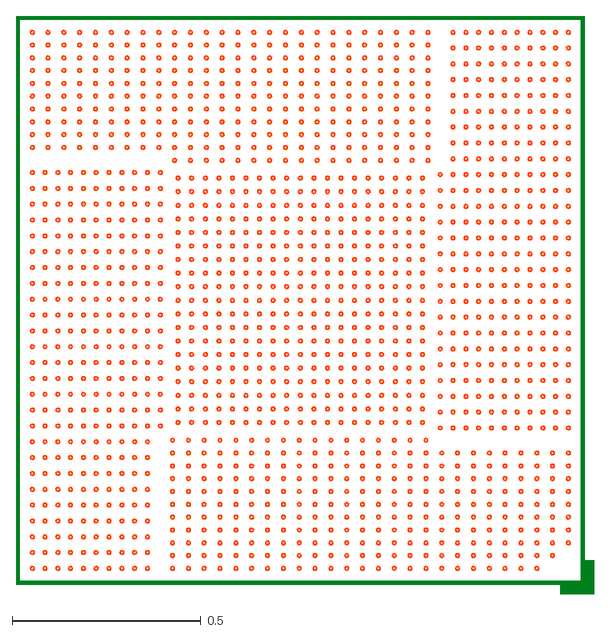
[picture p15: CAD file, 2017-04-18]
minnowboard-turbot-dual-core/pcb-f200-revX205_Turbot-A/Turbot_F200_X205_VX/Minnowmax_Central_Library/Output/1466_in.dxf
1.53 x 1.53

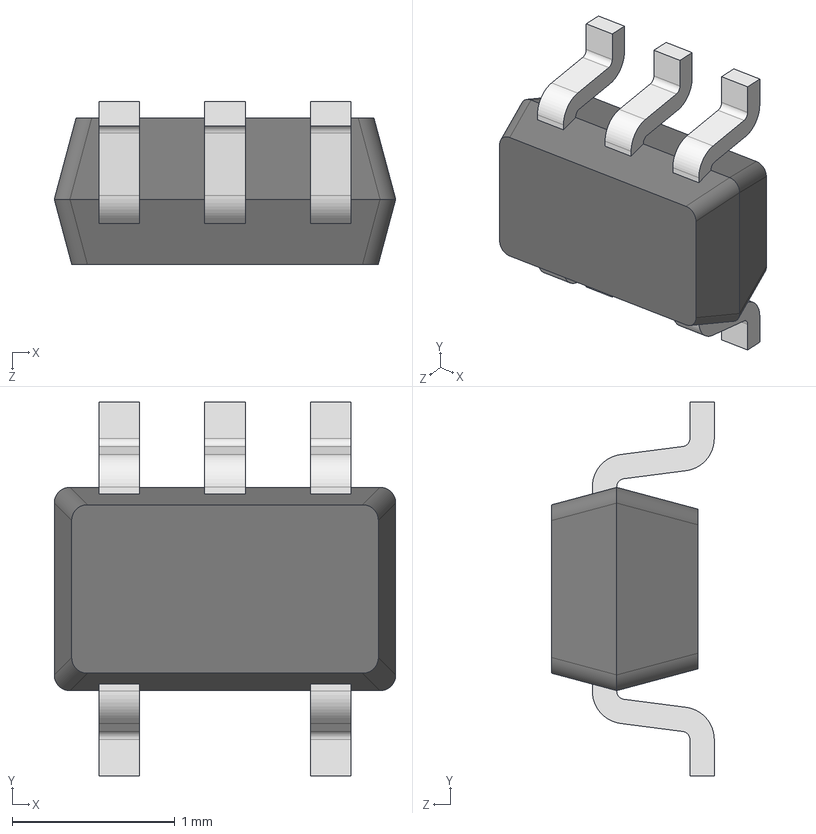
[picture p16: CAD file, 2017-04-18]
minnowboard-turbot-dual-core/pcb-f200-revX205_Turbot-A/Turbot_F200_X205_VX/PCB/Layout/3D/ImportedPartModels/SOT353_SC70_5.step
2.10 x 2.30 x 1.00 mm

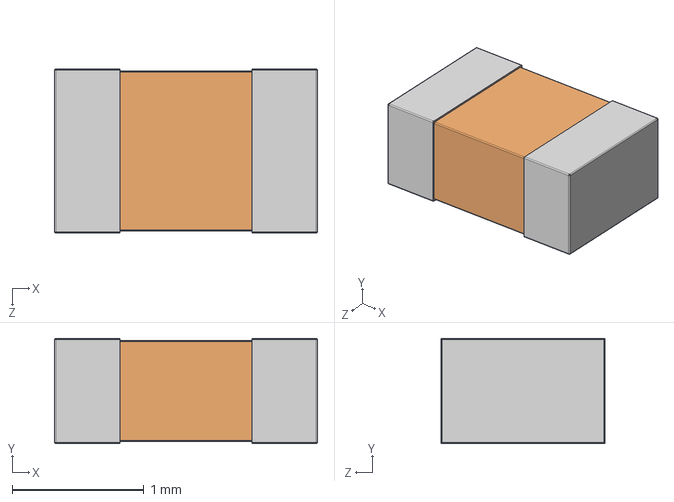
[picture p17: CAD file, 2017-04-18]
minnowboard-turbot-dual-core/pcb-f200-revX205_Turbot-A/STEPLibrary/0805C.step
2.00 x 0.8 x 1.25 mm

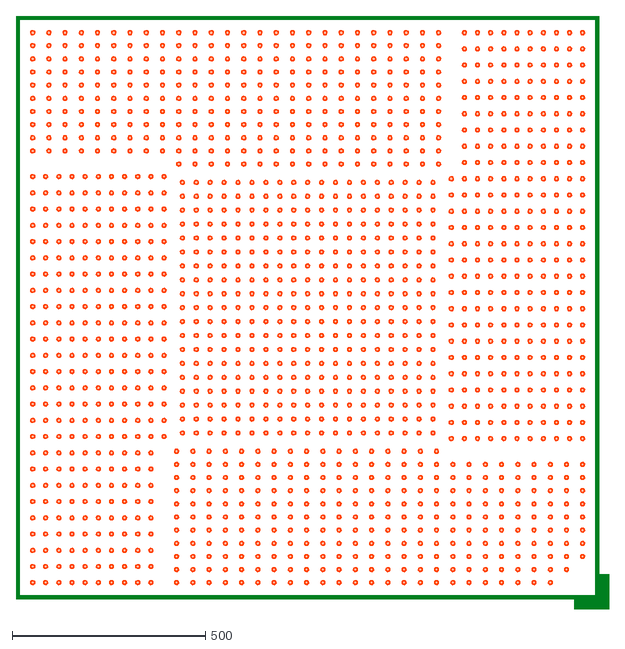
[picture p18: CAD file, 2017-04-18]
minnowboard-turbot-dual-core/pcb-f200-revX205_Turbot-A/Turbot_F200_X205_VX/Minnowmax_Central_Library/Output/1466.dxf
1533.0 x 1533.0

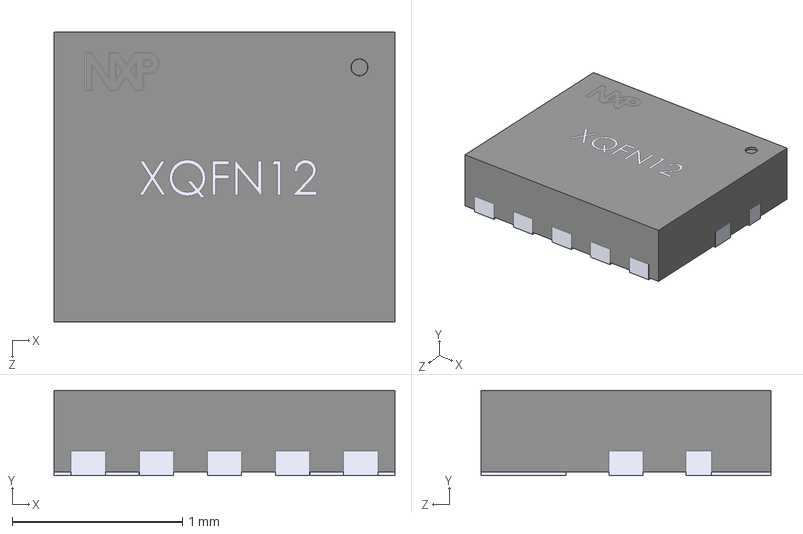
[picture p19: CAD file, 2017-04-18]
minnowboard-turbot-dual-core/pcb-f200-revX205_Turbot-A/Turbot_F200_X205_VX/PCB/Layout/3D/ImportedPartModels/XQFN12.step
2.00 x 0.5 x 1.70 mm

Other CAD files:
minnowboard-v1/rev-a/MinnowBoard_RevA_MFG/Minnow_RevA_DXF/Minnow_RevA_ASSY.dxf
minnowboard-v1/rev-a/MinnowBoard_RevA_MFG/Minnow_RevA_DXF/Minnow_RevA_FAB.dxf
minnowboard-turbot-dual-core/pcb-f200-revX205_Turbot-A/Turbot_F200_X205_VX/Minnowmax_Central_Library/Output/female.dxf
minnowboard-turbot-dual-core/pcb-f200-revX205_Turbot-A/STEPLibrary/0402C.step
minnowboard-turbot-dual-core/pcb-f200-revX205_Turbot-A/STEPLibrary/0402C_V3.step
minnowboard-turbot-dual-core/pcb-f200-revX205_Turbot-A/STEPLibrary/0402R.step
minnowboard-turbot-dual-core/pcb-f200-revX205_Turbot-A/STEPLibrary/0603C.step
minnowboard-turbot-dual-core/pcb-f200-revX205_Turbot-A/STEPLibrary/0603I.stp
minnowboard-turbot-dual-core/pcb-f200-revX205_Turbot-A/STEPLibrary/0603R.step
minnowboard-turbot-dual-core/pcb-f200-revX205_Turbot-A/STEPLibrary/0805R.step
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

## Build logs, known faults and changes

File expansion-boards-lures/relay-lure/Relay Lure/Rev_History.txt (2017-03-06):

Revision History:  

Rev 1.01 fixes:  
Removed 2  90 degree angles in 2 traces in the bottom layer, changes reflected in the PCB design file.   
In the top layer improved some of the traces entry points to the some pads of the relays.   
Improved U5 header trace routing.   

Rev 1.02:
Added dots as pin 1 identifier for the VO617A Optocouplers and added lettering on the bottom silk mentioning that this Lure is compatible with MinnowBoard MAX and Turbot.    

Rev 1.05: 
Updated library(minnowboard_lse.eli) that matches the pin numbering in the MinnowBoard MAX / Turbot boards, Schematic and PCB design files updated with this component, Schematic PDF and Gerber files updated.

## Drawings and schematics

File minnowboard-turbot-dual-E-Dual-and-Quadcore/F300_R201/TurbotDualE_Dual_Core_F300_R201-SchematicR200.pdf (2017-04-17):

# Rev : R200 TURBOT Dual-E

# DC-DC VOLTAGE

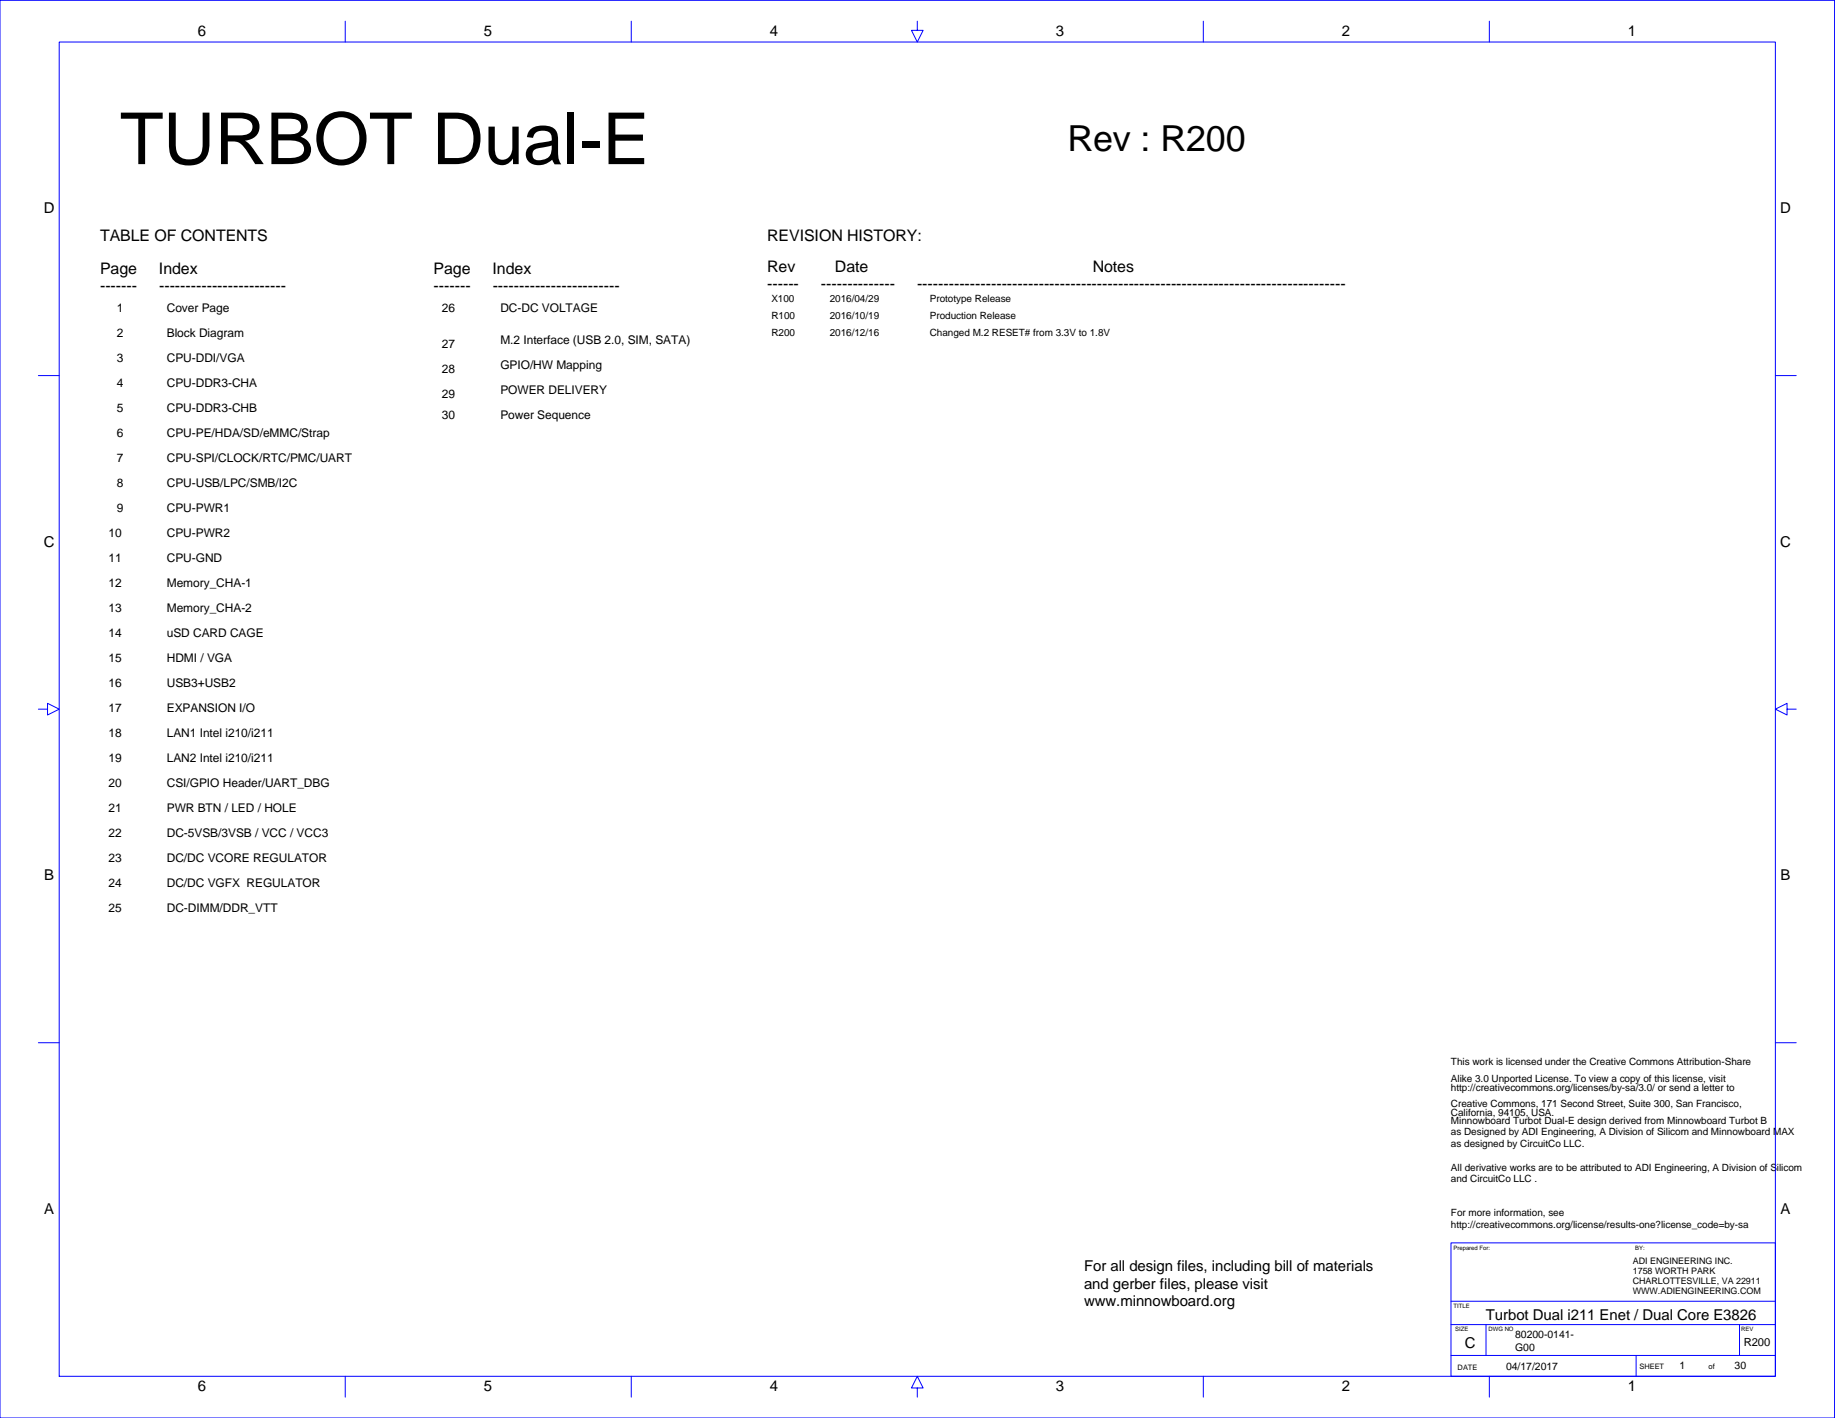
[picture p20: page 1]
REVISION HISTORY:; Page; Index; Rev; Date; Notes; TABLE OF CONTENTS; DATE; SHEET; SIZE; DWG NO; REV; Prepared For:; Prototype Release; Production Release; Changed M.2 RESET# from 3.3V to 1.8V

Cover Page
Block Diagram
CPU-DDI/VGA
CPU-DDR3-CHA
CPU-DDR3-CHB
CPU-PE/HDA/SD/eMMC/Strap
CPU-SPI/CLOCK/RTC/PMC/UART
CPU-USB/LPC/SMB/I2C
CPU-PWR1
CPU-PWR2
CPU-GND
Memory_CHA-1
Memory_CHA-2
uSD CARD CAGE
HDMI / VGA
USB3+USB2
EXPANSION I/O
LAN1 Intel i210/i211
LAN2 Intel i210/i211
CSI/GPIO Header/UART_DBG
PWR BTN / LED / HOLE
DC-5VSB/3VSB / VCC / VCC3
DC/DC VCORE REGULATOR
DC/DC VGFX REGULATOR
DC-DIMM/DDR_VTT

M.2 Interface (USB 2.0, SIM, SATA)
GPIO/HW Mapping
POWER DELIVERY
Power Sequence

This work is licensed under the Creative Commons Attribution-Share
Alike 3.0 Unported License. To view a copy of this license, visit
http://creativecommons.org/licenses/by-sa/3.0/ or send a letter to
Creative Commons, 171 Second Street, Suite 300, San Francisco,
California, 94105, USA.
Minnowboard Turbot Dual-E design derived from Minnowboard Turbot B
as Designed by ADI Engineering, A Division of Silicom and Minnowboard MAX
as designed by CircuitCo LLC.

All derivative works are to be attributed to ADI Engineering, A Division of Silicom
and CircuitCo LLC .

For more information, see
http://creativecommons.org/license/results-one?license_code=by-sa

ADI ENGINEERING INC.
1758 WORTH PARK
CHARLOTTESVILLE, VA 22911
WWW.ADIENGINEERING.COM

For all design files, including bill of materials
and gerber files, please visit
www.minnowboard.org

TITLE
Turbot Dual i211 Enet / Dual Core E3826

## page12/13

# Memory CH0

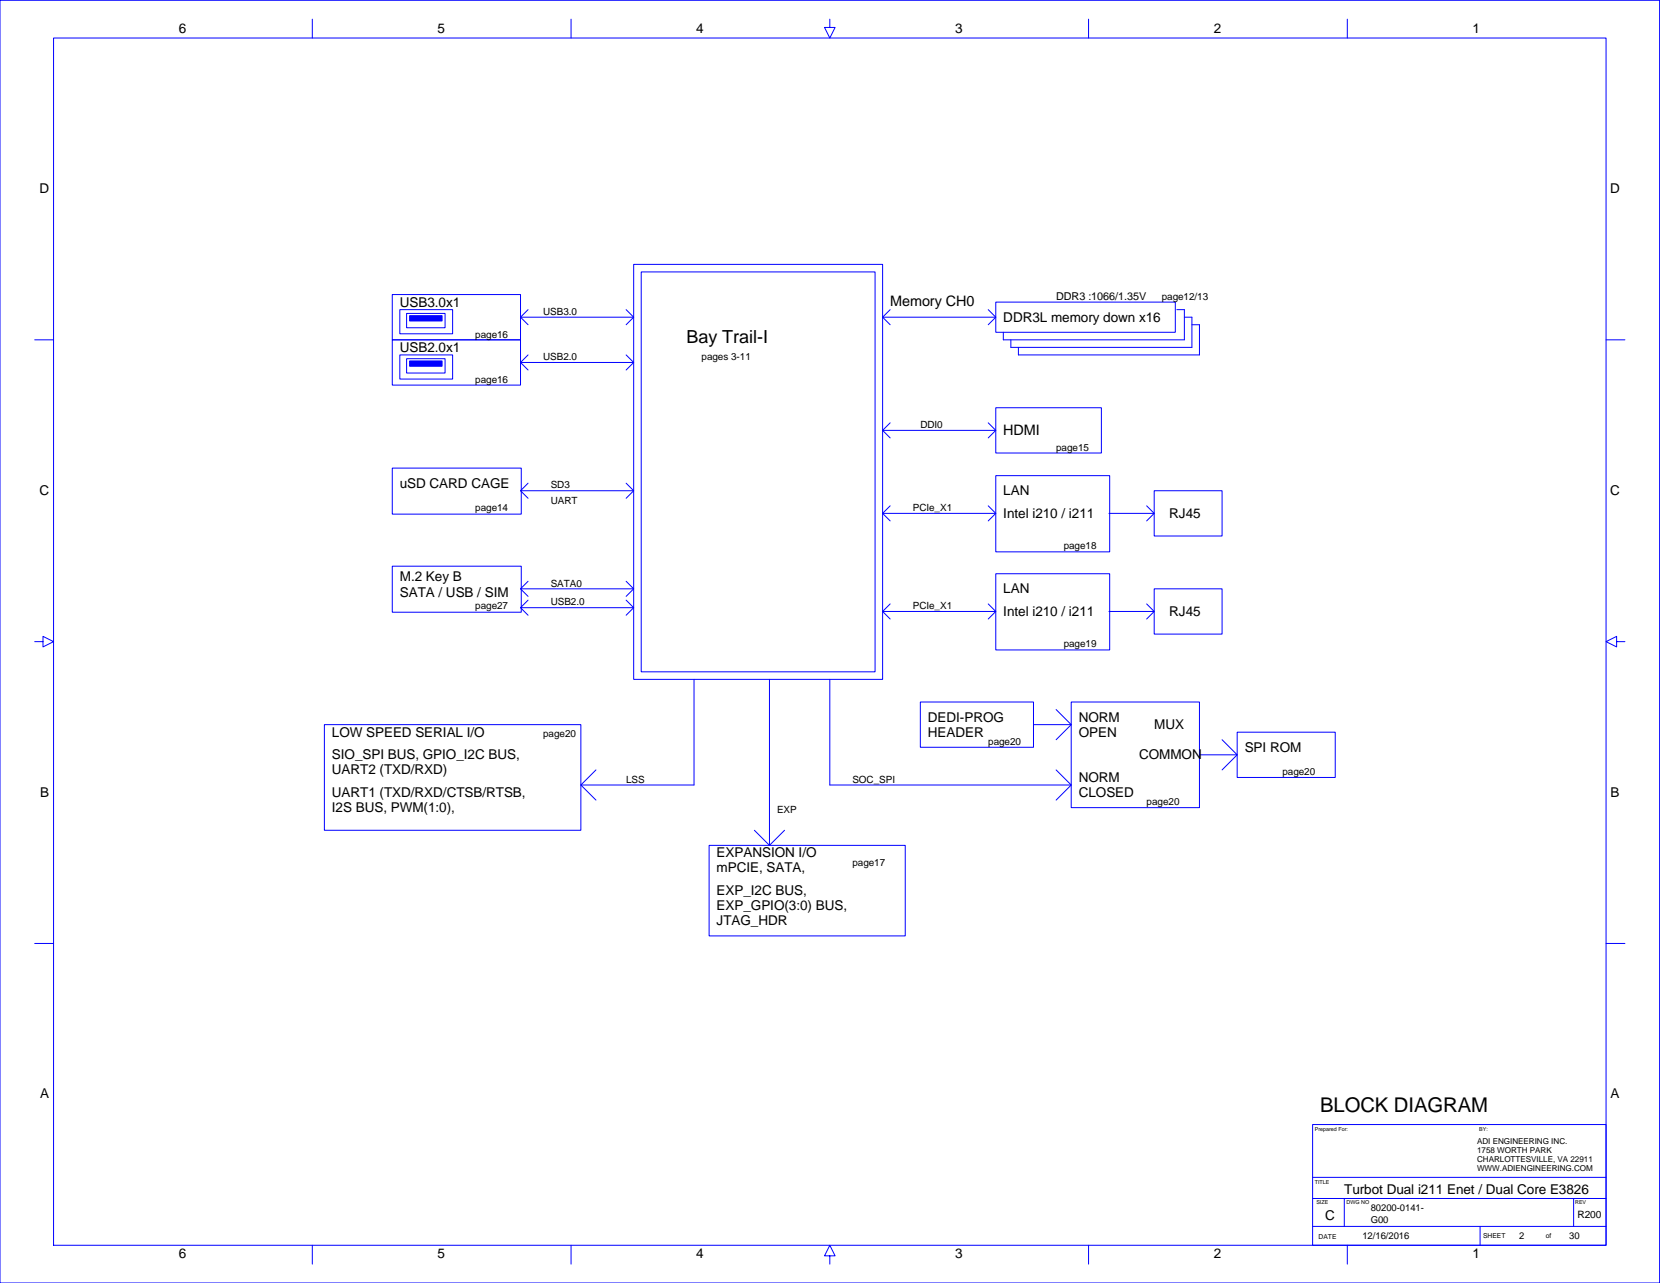
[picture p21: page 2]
pages 3-11; page20; COMMON; CLOSED; NORM; OPEN; MUX; HEADER; DEDI-PROG; EXP; LSS; page17; JTAG_HDR; EXP_GPIO(3:0) BUS,; EXP_I2C BUS,; mPCIE, SATA,; EXPANSION I/O; M.2 Key B; SATA0; page27; page19; page15; page14; page16; UART; USB2.0; USB2.0x1; USB3.0x1; USB3.0; DDI0; HDMI; SOC_SPI; SPI ROM; PCIe_X1; Intel i210 / i211; LAN; DDR3 :1066/1.35V DDR3L memory down x16; Bay Trail-I; BLOCK DIAGRAM; Prepared For:; page18; RJ45 PCIe_X1

uSD CARD CAGE

SATA / USB / SIM

LOW SPEED SERIAL I/O
SIO_SPI BUS, GPIO_I2C BUS,
UART2 (TXD/RXD)
UART1 (TXD/RXD/CTSB/RTSB,
I2S BUS, PWM(1:0),

ADI ENGINEERING INC.
1758 WORTH PARK
CHARLOTTESVILLE, VA 22911
WWW.ADIENGINEERING.COM

## for EDP ONLY

## STRAIGHT BIT ORDER is

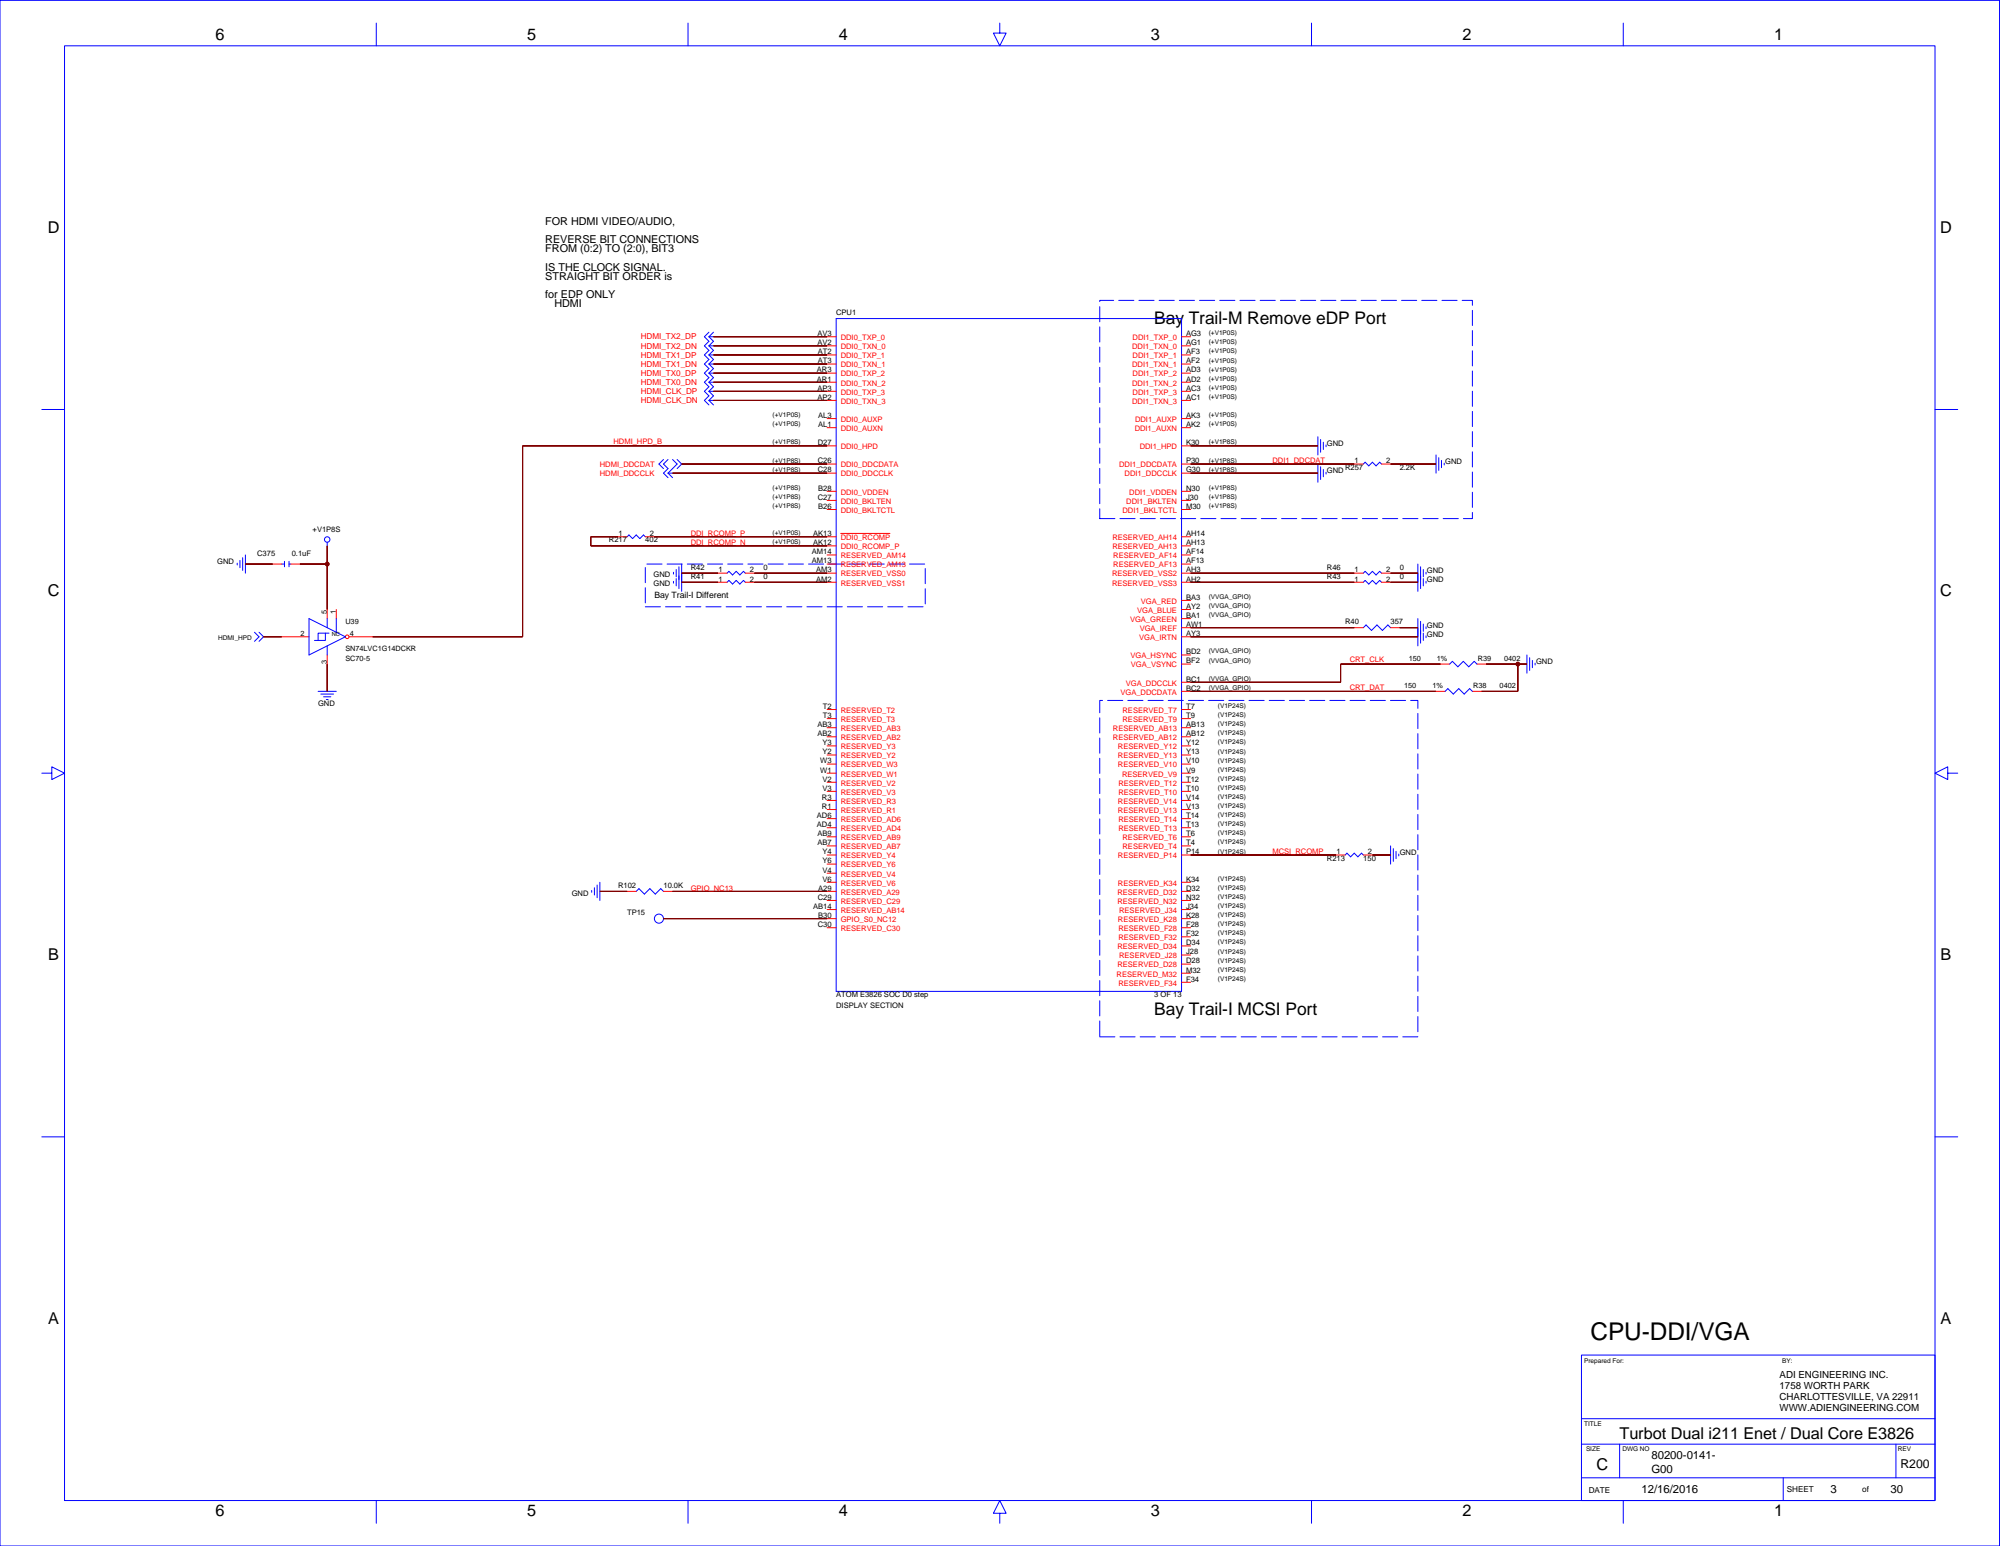
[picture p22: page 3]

FOR HDMI VIDEO/AUDIO,
REVERSE BIT CONNECTIONS
FROM (0:2) TO (2:0), BIT3
IS THE CLOCK SIGNAL.

Bay Trail-M Remove eDP Port

## ABCD

CD

## ABCD

CD

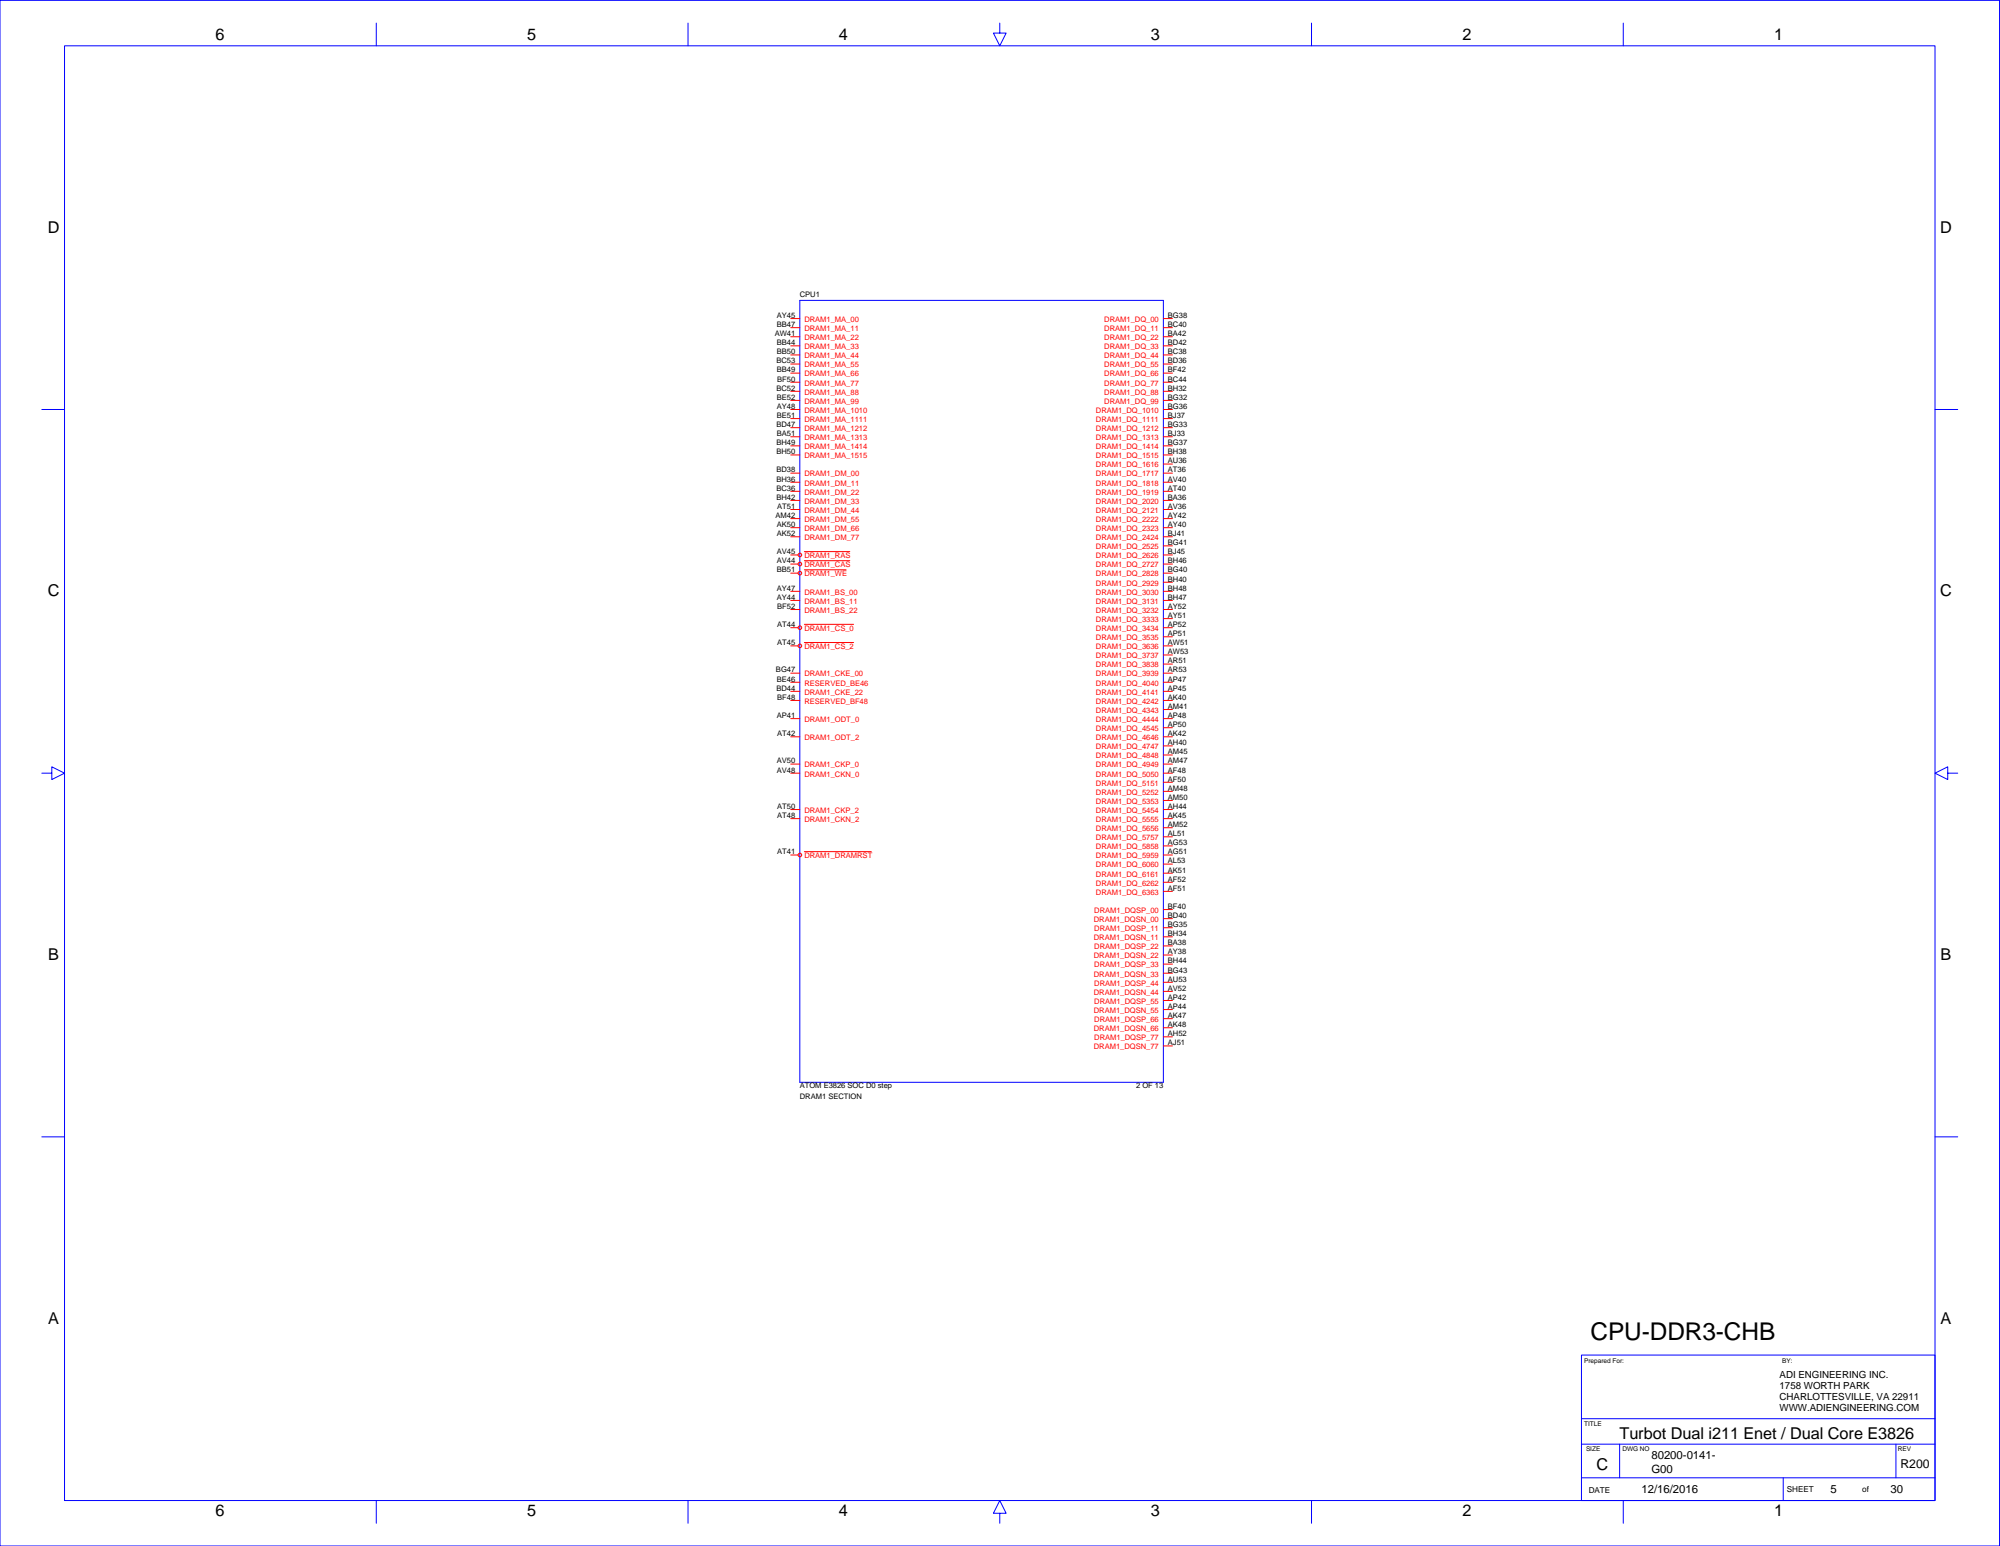
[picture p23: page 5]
DRAM1 SECTION; DRAM1_ODT_0; DRAM1_CKN_0; DRAM1_CKP_0; DRAM1_DRAMRST; DRAM1_CKN_2; DRAM1_CKP_2; DRAM1_DQSN_77; DRAM1_DQSP_77; DRAM1_DQSN_66; DRAM1_DQSP_66; DRAM1_DQSN_55; DRAM1_DQSP_55; DRAM1_DQSN_44; DRAM1_DQSP_44; DRAM1_DQSN_33; DRAM1_DQSP_33; DRAM1_DQSN_22; DRAM1_DQSP_22; DRAM1_DQSN_11; DRAM1_DQSP_11; DRAM1_DQSN_00; DRAM1_DQSP_00; DRAM1_DQ_6363; DRAM1_DQ_6262; DRAM1_DQ_6161; DRAM1_DQ_6060; DRAM1_DQ_5959; DRAM1_DQ_5858; DRAM1_DQ_5757; DRAM1_DQ_5656; DRAM1_DQ_5555; DRAM1_DQ_5454; DRAM1_DQ_5353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

ADI ENGINEERING INC.
1758 WORTH PARK
CHARLOTTESVILLE, VA 22911
WWW.ADIENGINEERING.COM

D

D

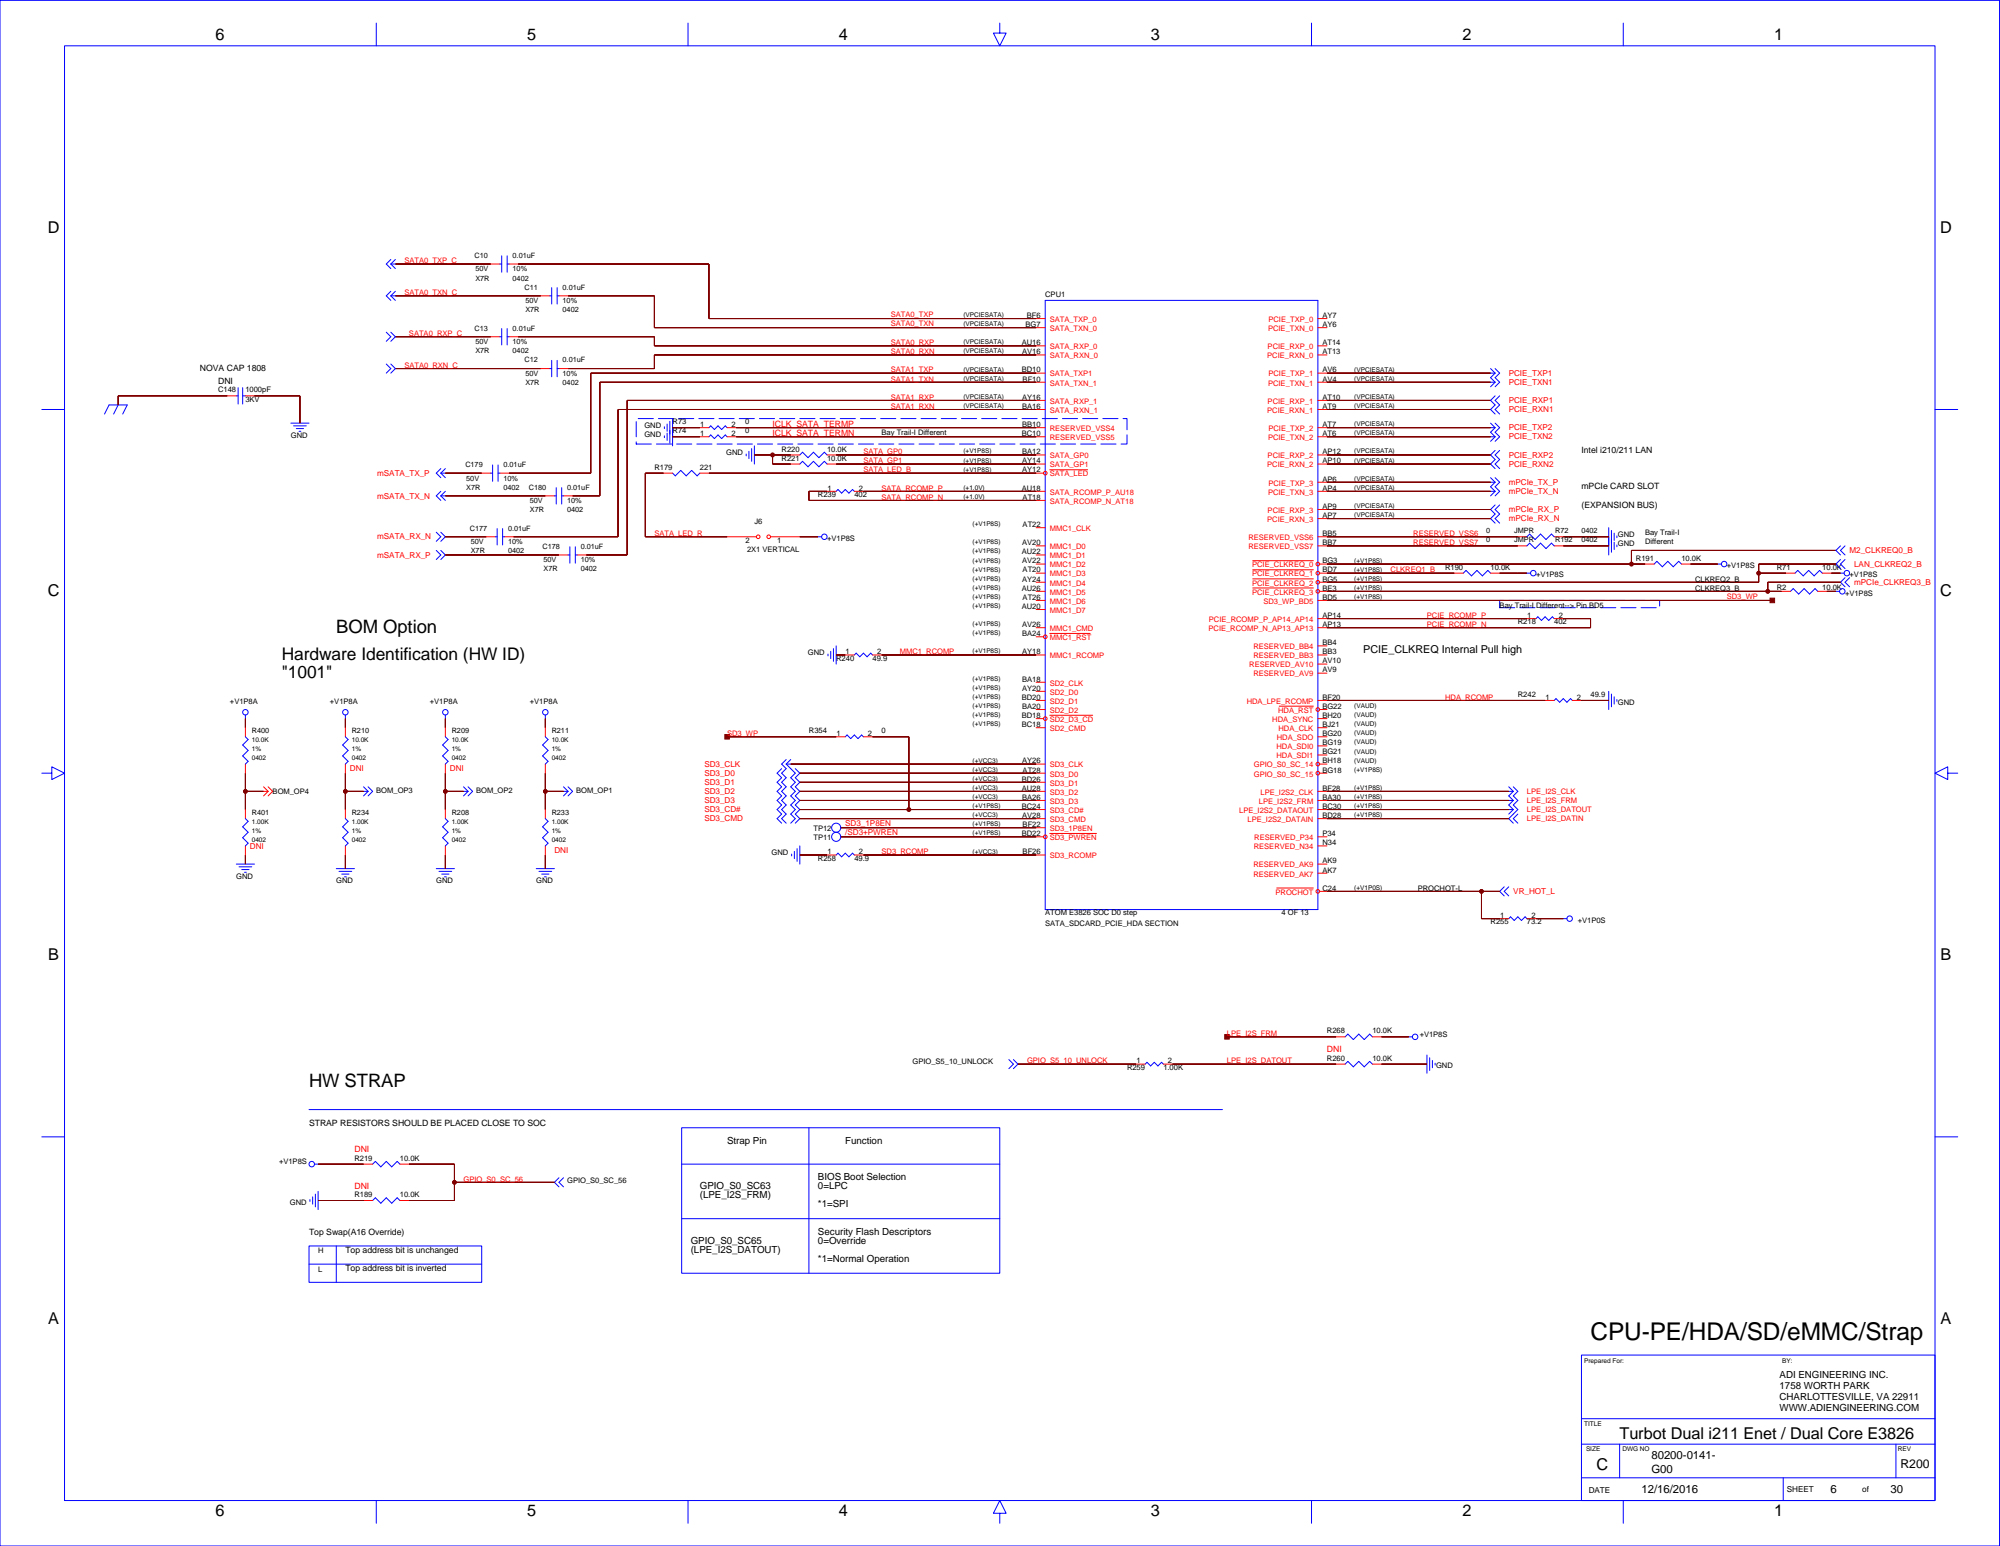
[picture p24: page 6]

Bay Trail-I Different--> Pin BD5

BOM Option
Hardware Identification (HW ID)

STRAP RESISTORS SHOULD BE PLACED CLOSE TO SOC

Top address bit is inverted

Top address bit is unchanged

CPU-PE/HDA/SD/eMMC/Strap

D

D

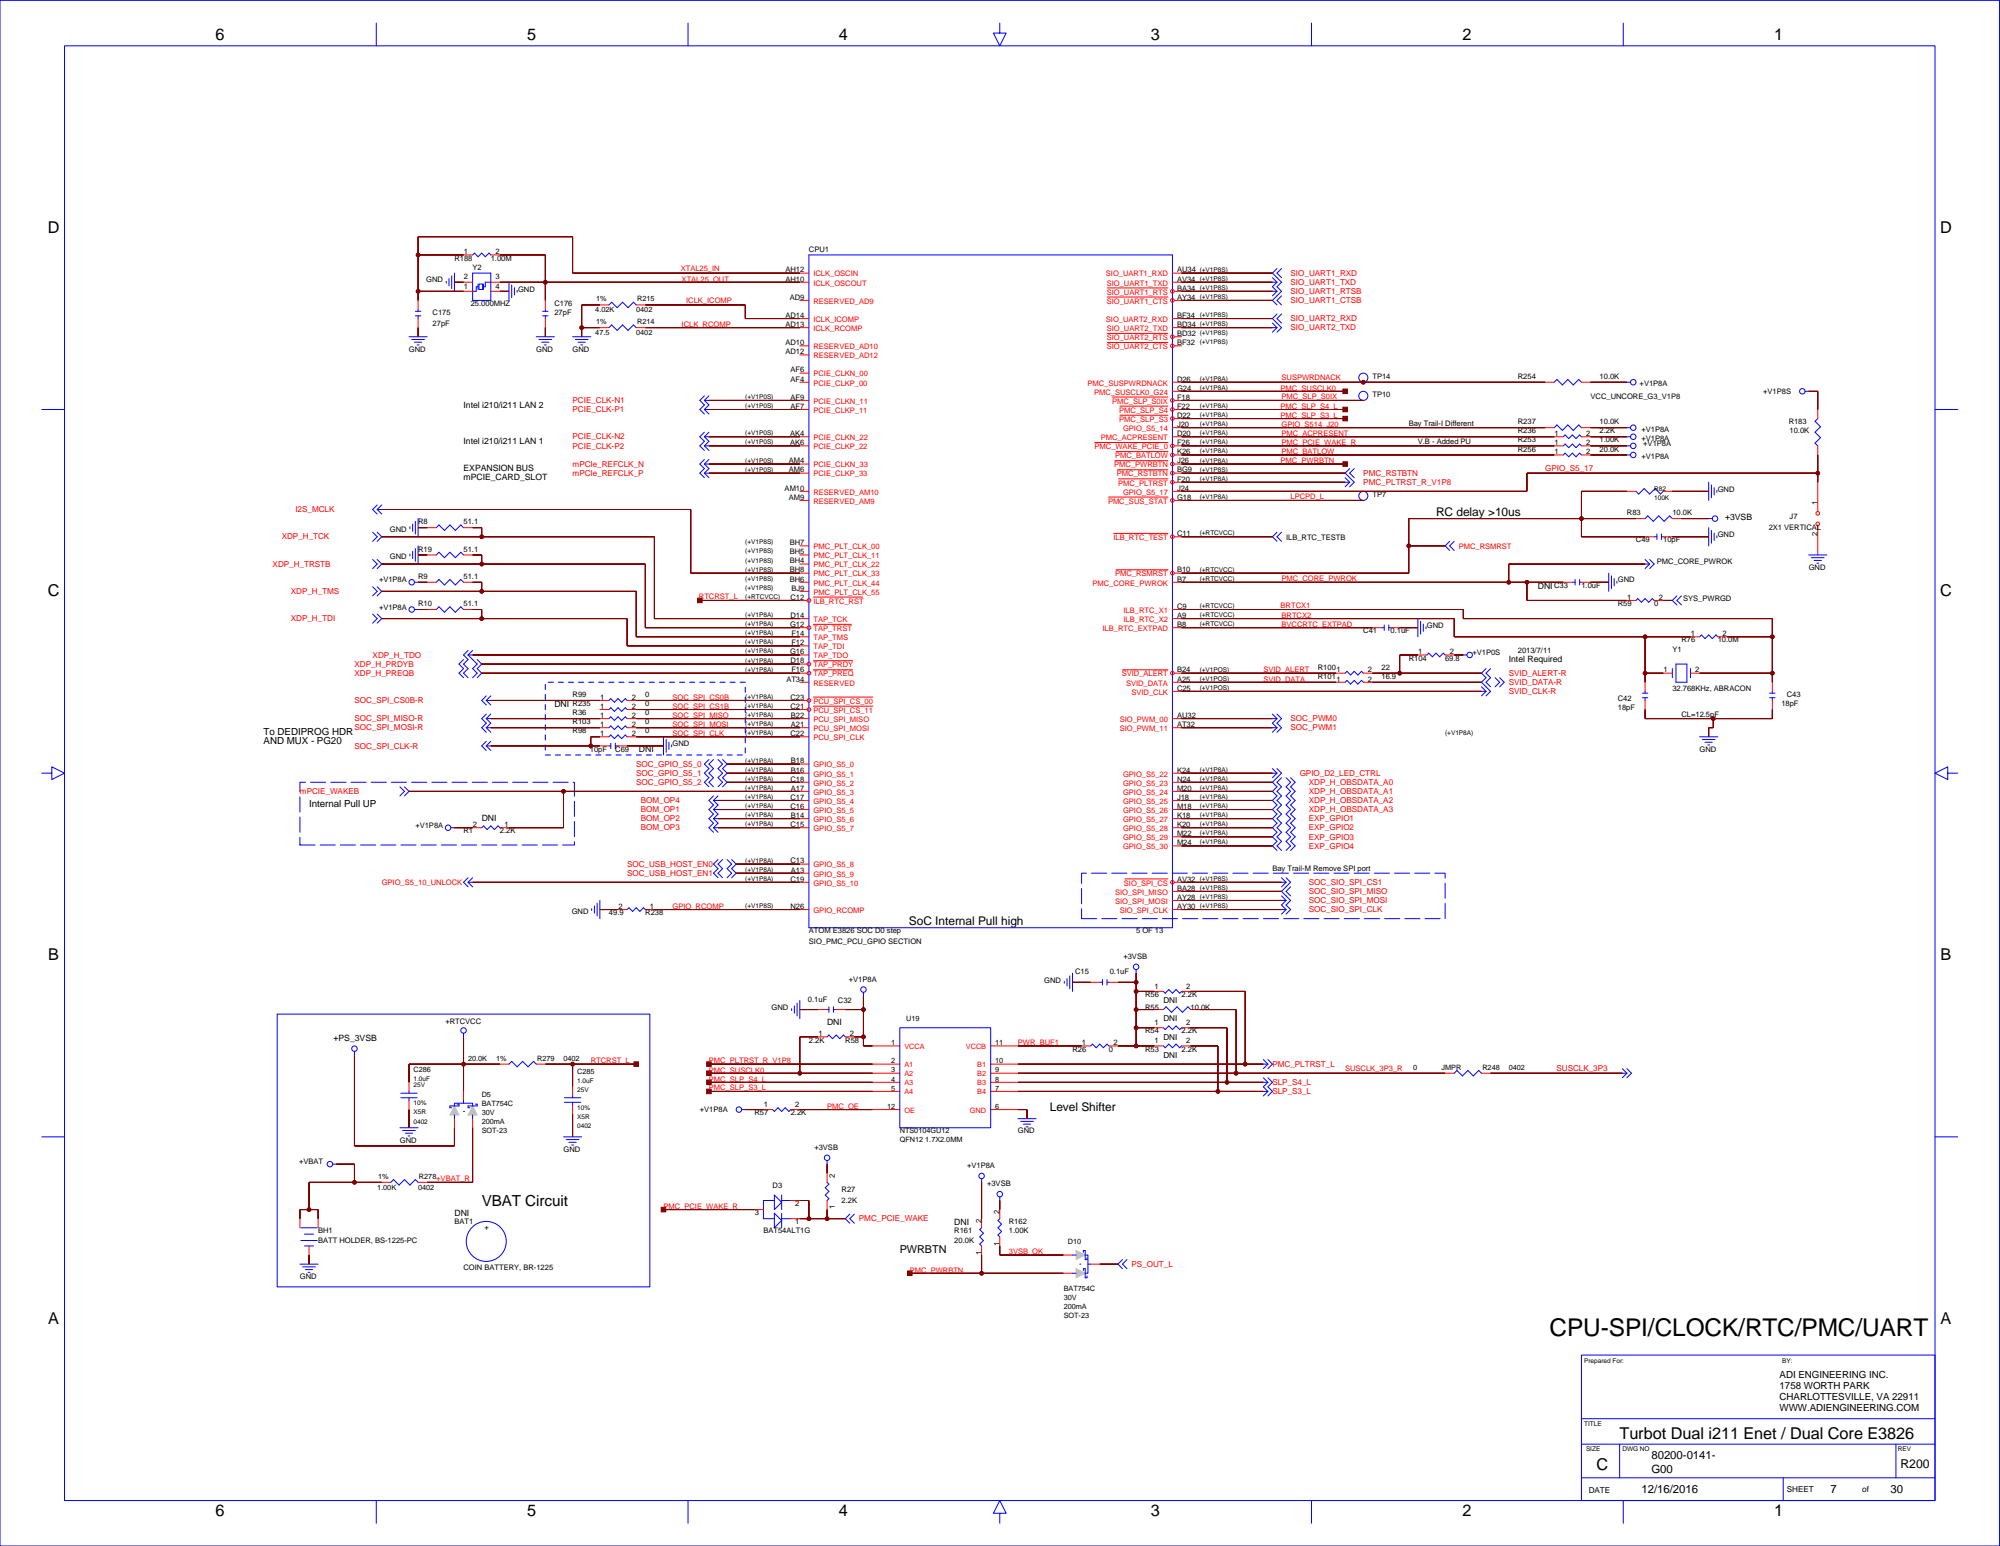
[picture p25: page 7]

Bay Trail-M Remove SPI port

SoC Internal Pull high

BATT HOLDER, BS-1225-PC

CPU-SPI/CLOCK/RTC/PMC/UART

## TX and RX LINES
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

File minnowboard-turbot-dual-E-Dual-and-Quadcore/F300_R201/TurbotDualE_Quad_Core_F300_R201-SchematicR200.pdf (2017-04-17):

# Rev : R200 TURBOT Dual-E

# DC-DC VOLTAGE

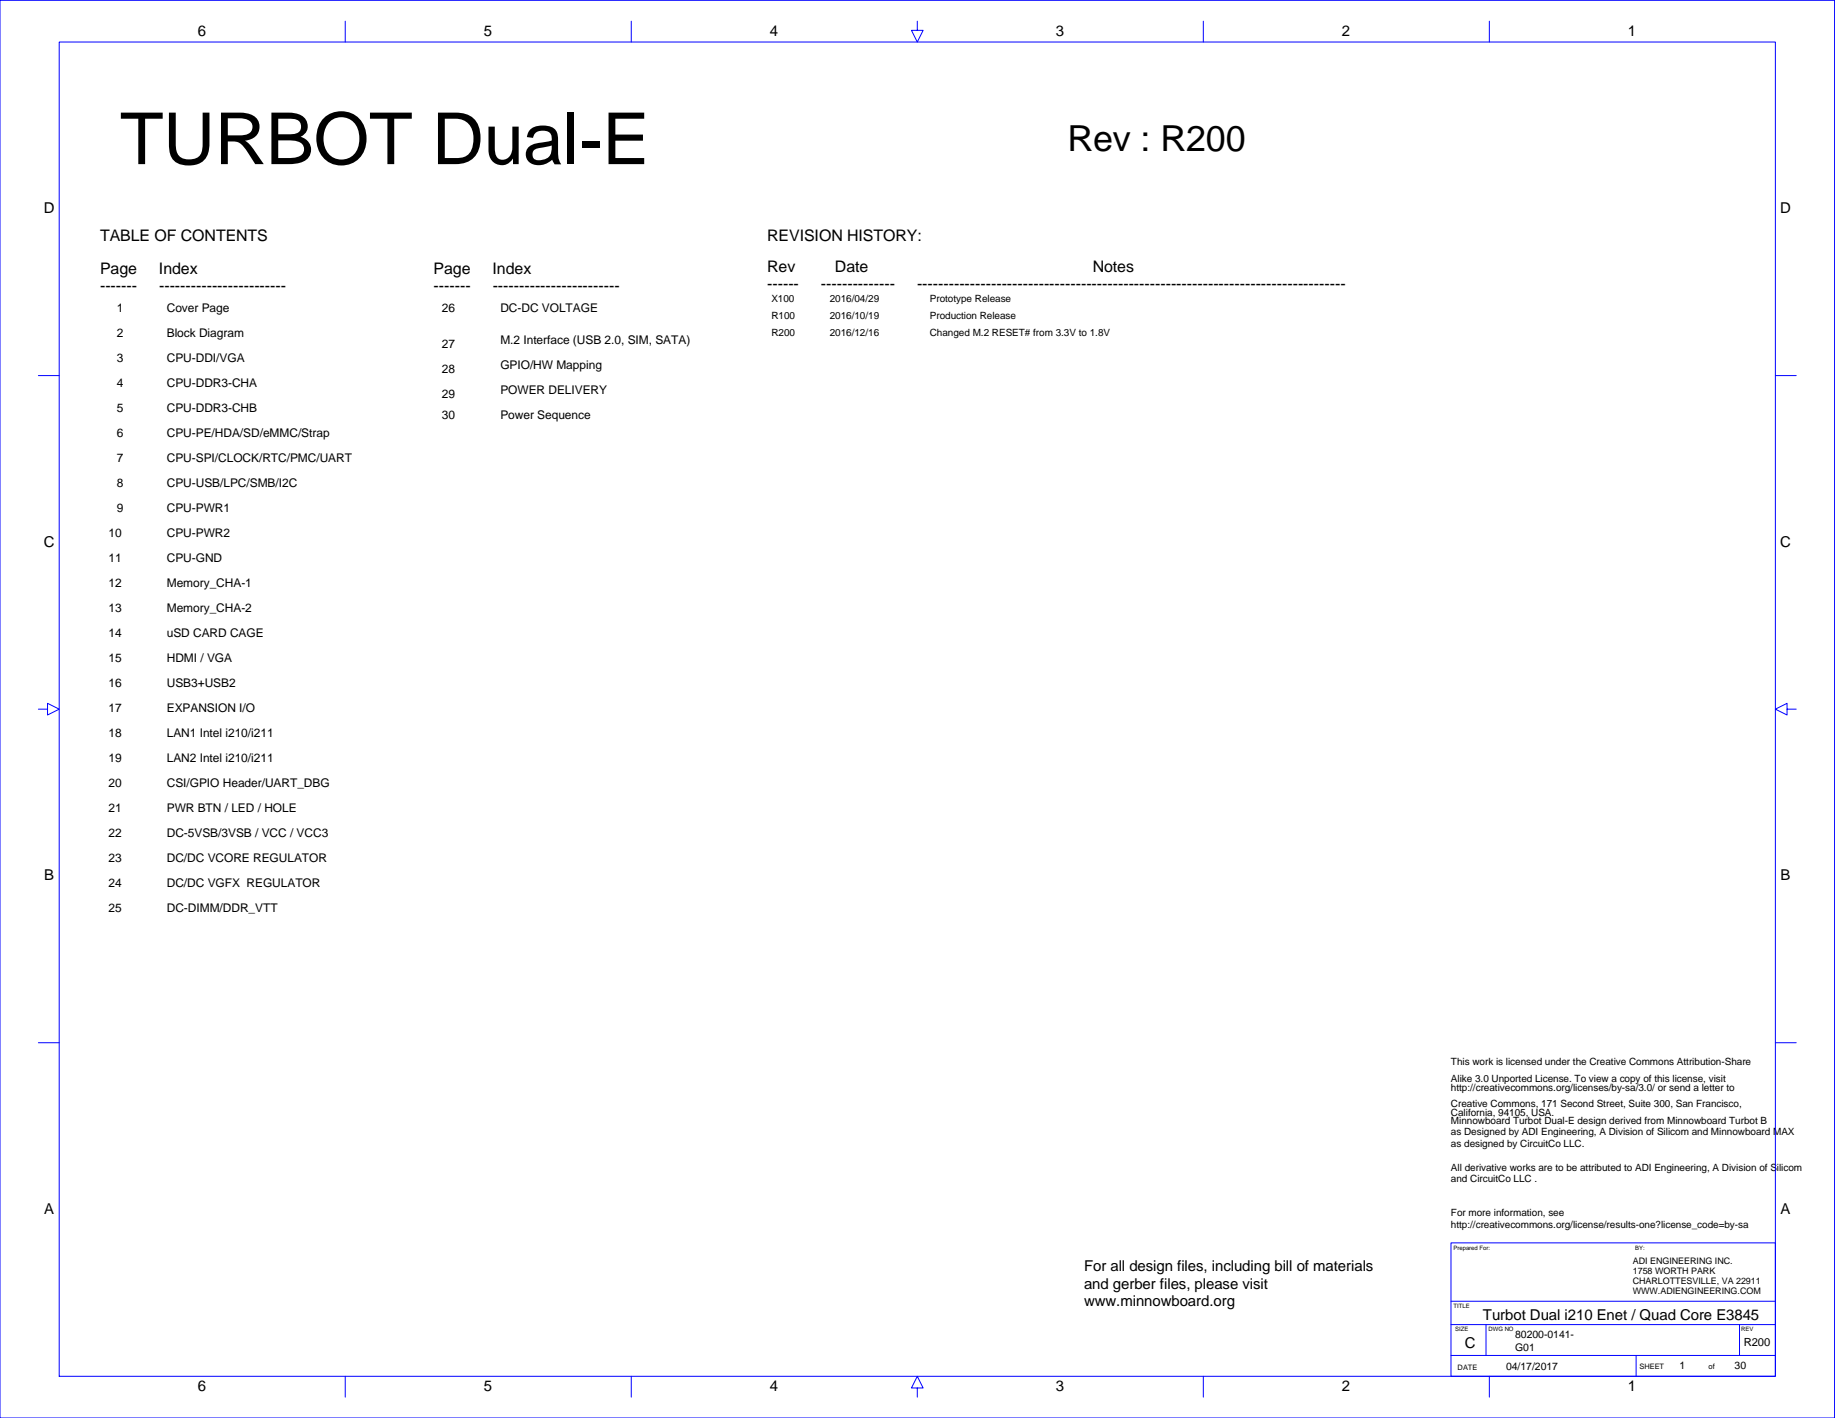
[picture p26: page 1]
REVISION HISTORY:; Page; Index; Rev; Date; Notes; TABLE OF CONTENTS; DATE; SHEET; SIZE; DWG NO; REV; Prepared For:; Prototype Release; Production Release; Changed M.2 RESET# from 3.3V to 1.8V

Cover Page
Block Diagram
CPU-DDI/VGA
CPU-DDR3-CHA
CPU-DDR3-CHB
CPU-PE/HDA/SD/eMMC/Strap
CPU-SPI/CLOCK/RTC/PMC/UART
CPU-USB/LPC/SMB/I2C
CPU-PWR1
CPU-PWR2
CPU-GND
Memory_CHA-1
Memory_CHA-2
uSD CARD CAGE
HDMI / VGA
USB3+USB2
EXPANSION I/O
LAN1 Intel i210/i211
LAN2 Intel i210/i211
CSI/GPIO Header/UART_DBG
PWR BTN / LED / HOLE
DC-5VSB/3VSB / VCC / VCC3
DC/DC VCORE REGULATOR
DC/DC VGFX REGULATOR
DC-DIMM/DDR_VTT

M.2 Interface (USB 2.0, SIM, SATA)
GPIO/HW Mapping
POWER DELIVERY
Power Sequence

This work is licensed under the Creative Commons Attribution-Share
Alike 3.0 Unported License. To view a copy of this license, visit
http://creativecommons.org/licenses/by-sa/3.0/ or send a letter to
Creative Commons, 171 Second Street, Suite 300, San Francisco,
California, 94105, USA.
Minnowboard Turbot Dual-E design derived from Minnowboard Turbot B
as Designed by ADI Engineering, A Division of Silicom and Minnowboard MAX
as designed by CircuitCo LLC.

All derivative works are to be attributed to ADI Engineering, A Division of Silicom
and CircuitCo LLC .

For more information, see
http://creativecommons.org/license/results-one?license_code=by-sa

ADI ENGINEERING INC.
1758 WORTH PARK
CHARLOTTESVILLE, VA 22911
WWW.ADIENGINEERING.COM

For all design files, including bill of materials
and gerber files, please visit
www.minnowboard.org

TITLE
Turbot Dual i210 Enet / Quad Core E3845

## page12/13

# Memory CH0

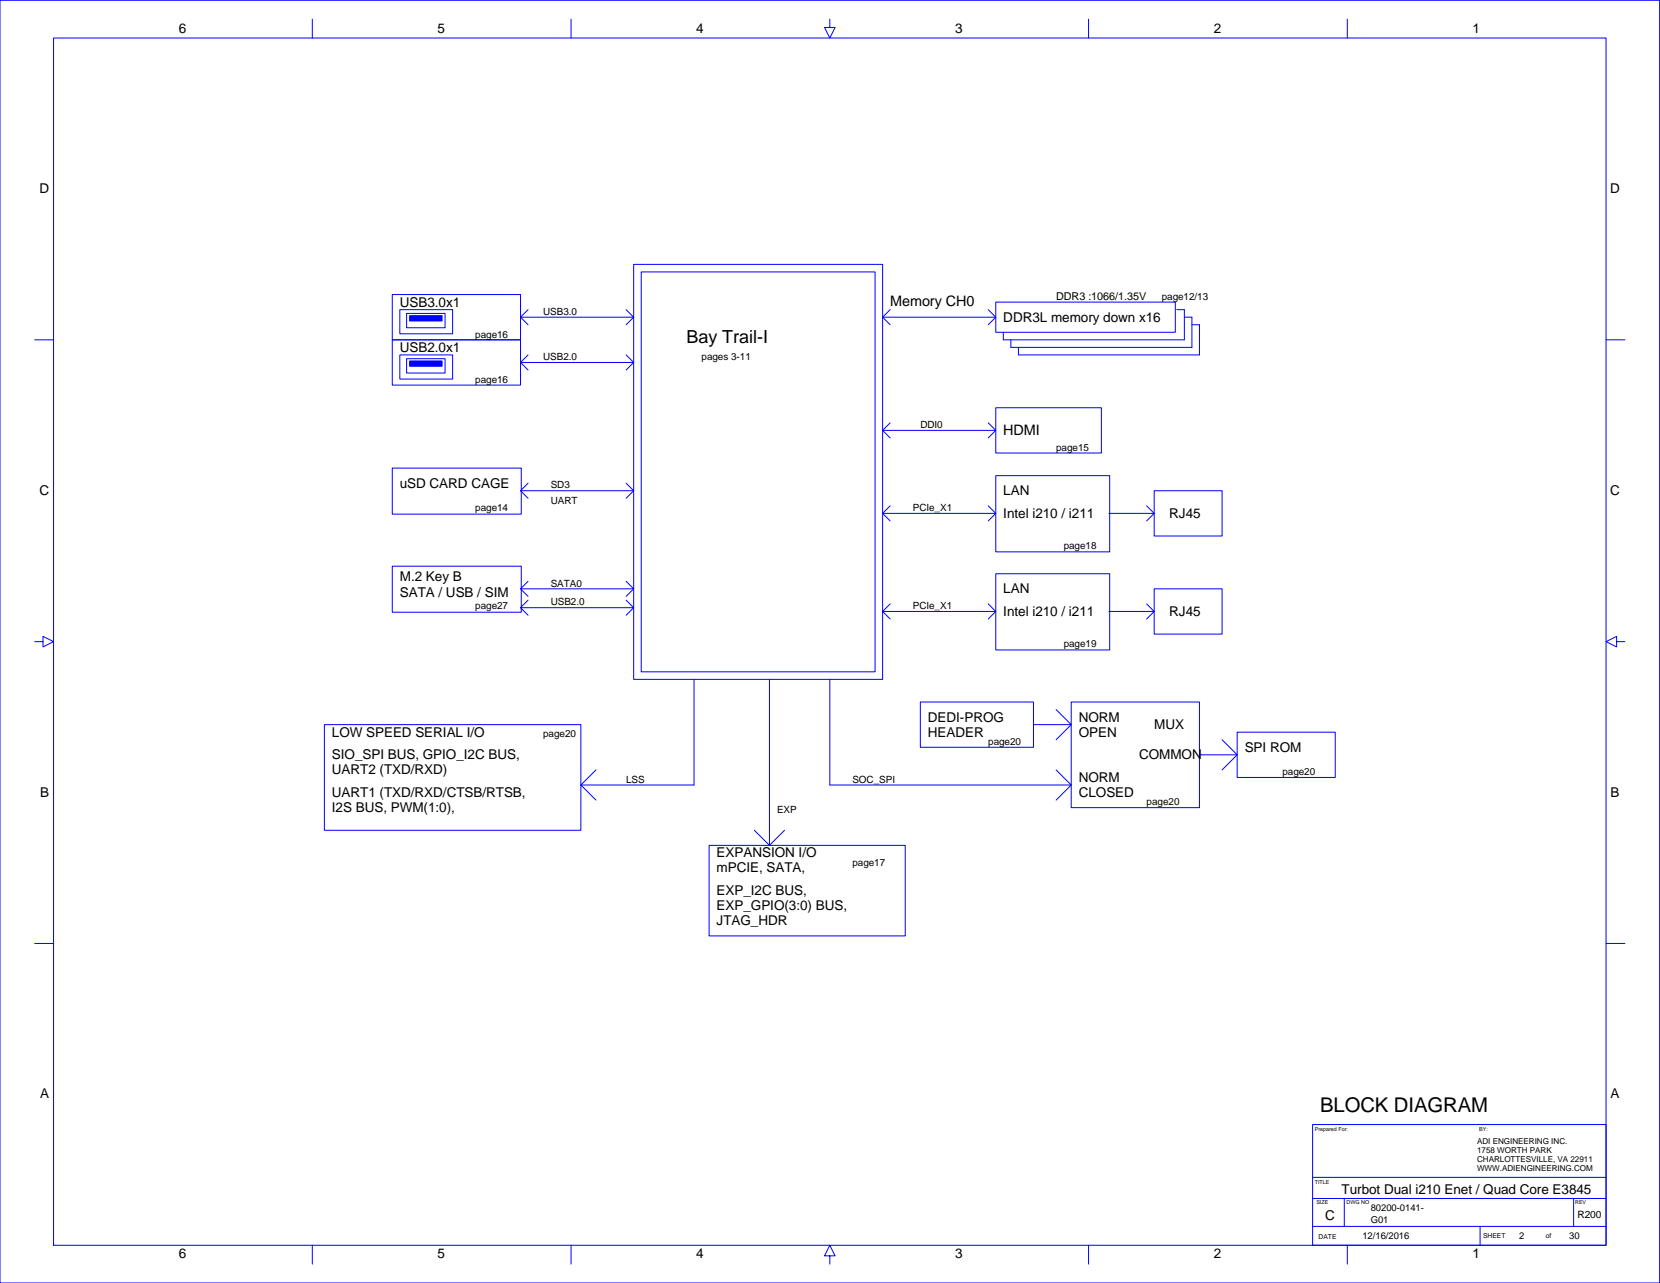
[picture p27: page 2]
pages 3-11; page20; COMMON; CLOSED; NORM; OPEN; MUX; HEADER; DEDI-PROG; EXP; LSS; page17; JTAG_HDR; EXP_GPIO(3:0) BUS,; EXP_I2C BUS,; mPCIE, SATA,; EXPANSION I/O; M.2 Key B; SATA0; page27; page19; page15; page14; page16; UART; USB2.0; USB2.0x1; USB3.0x1; USB3.0; DDI0; HDMI; SOC_SPI; SPI ROM; PCIe_X1; Intel i210 / i211; LAN; DDR3 :1066/1.35V DDR3L memory down x16; Bay Trail-I; BLOCK DIAGRAM; Prepared For:; page18; RJ45 PCIe_X1

uSD CARD CAGE

SATA / USB / SIM

LOW SPEED SERIAL I/O
SIO_SPI BUS, GPIO_I2C BUS,
UART2 (TXD/RXD)
UART1 (TXD/RXD/CTSB/RTSB,
I2S BUS, PWM(1:0),

ADI ENGINEERING INC.
1758 WORTH PARK
CHARLOTTESVILLE, VA 22911
WWW.ADIENGINEERING.COM

## for EDP ONLY

## STRAIGHT BIT ORDER is

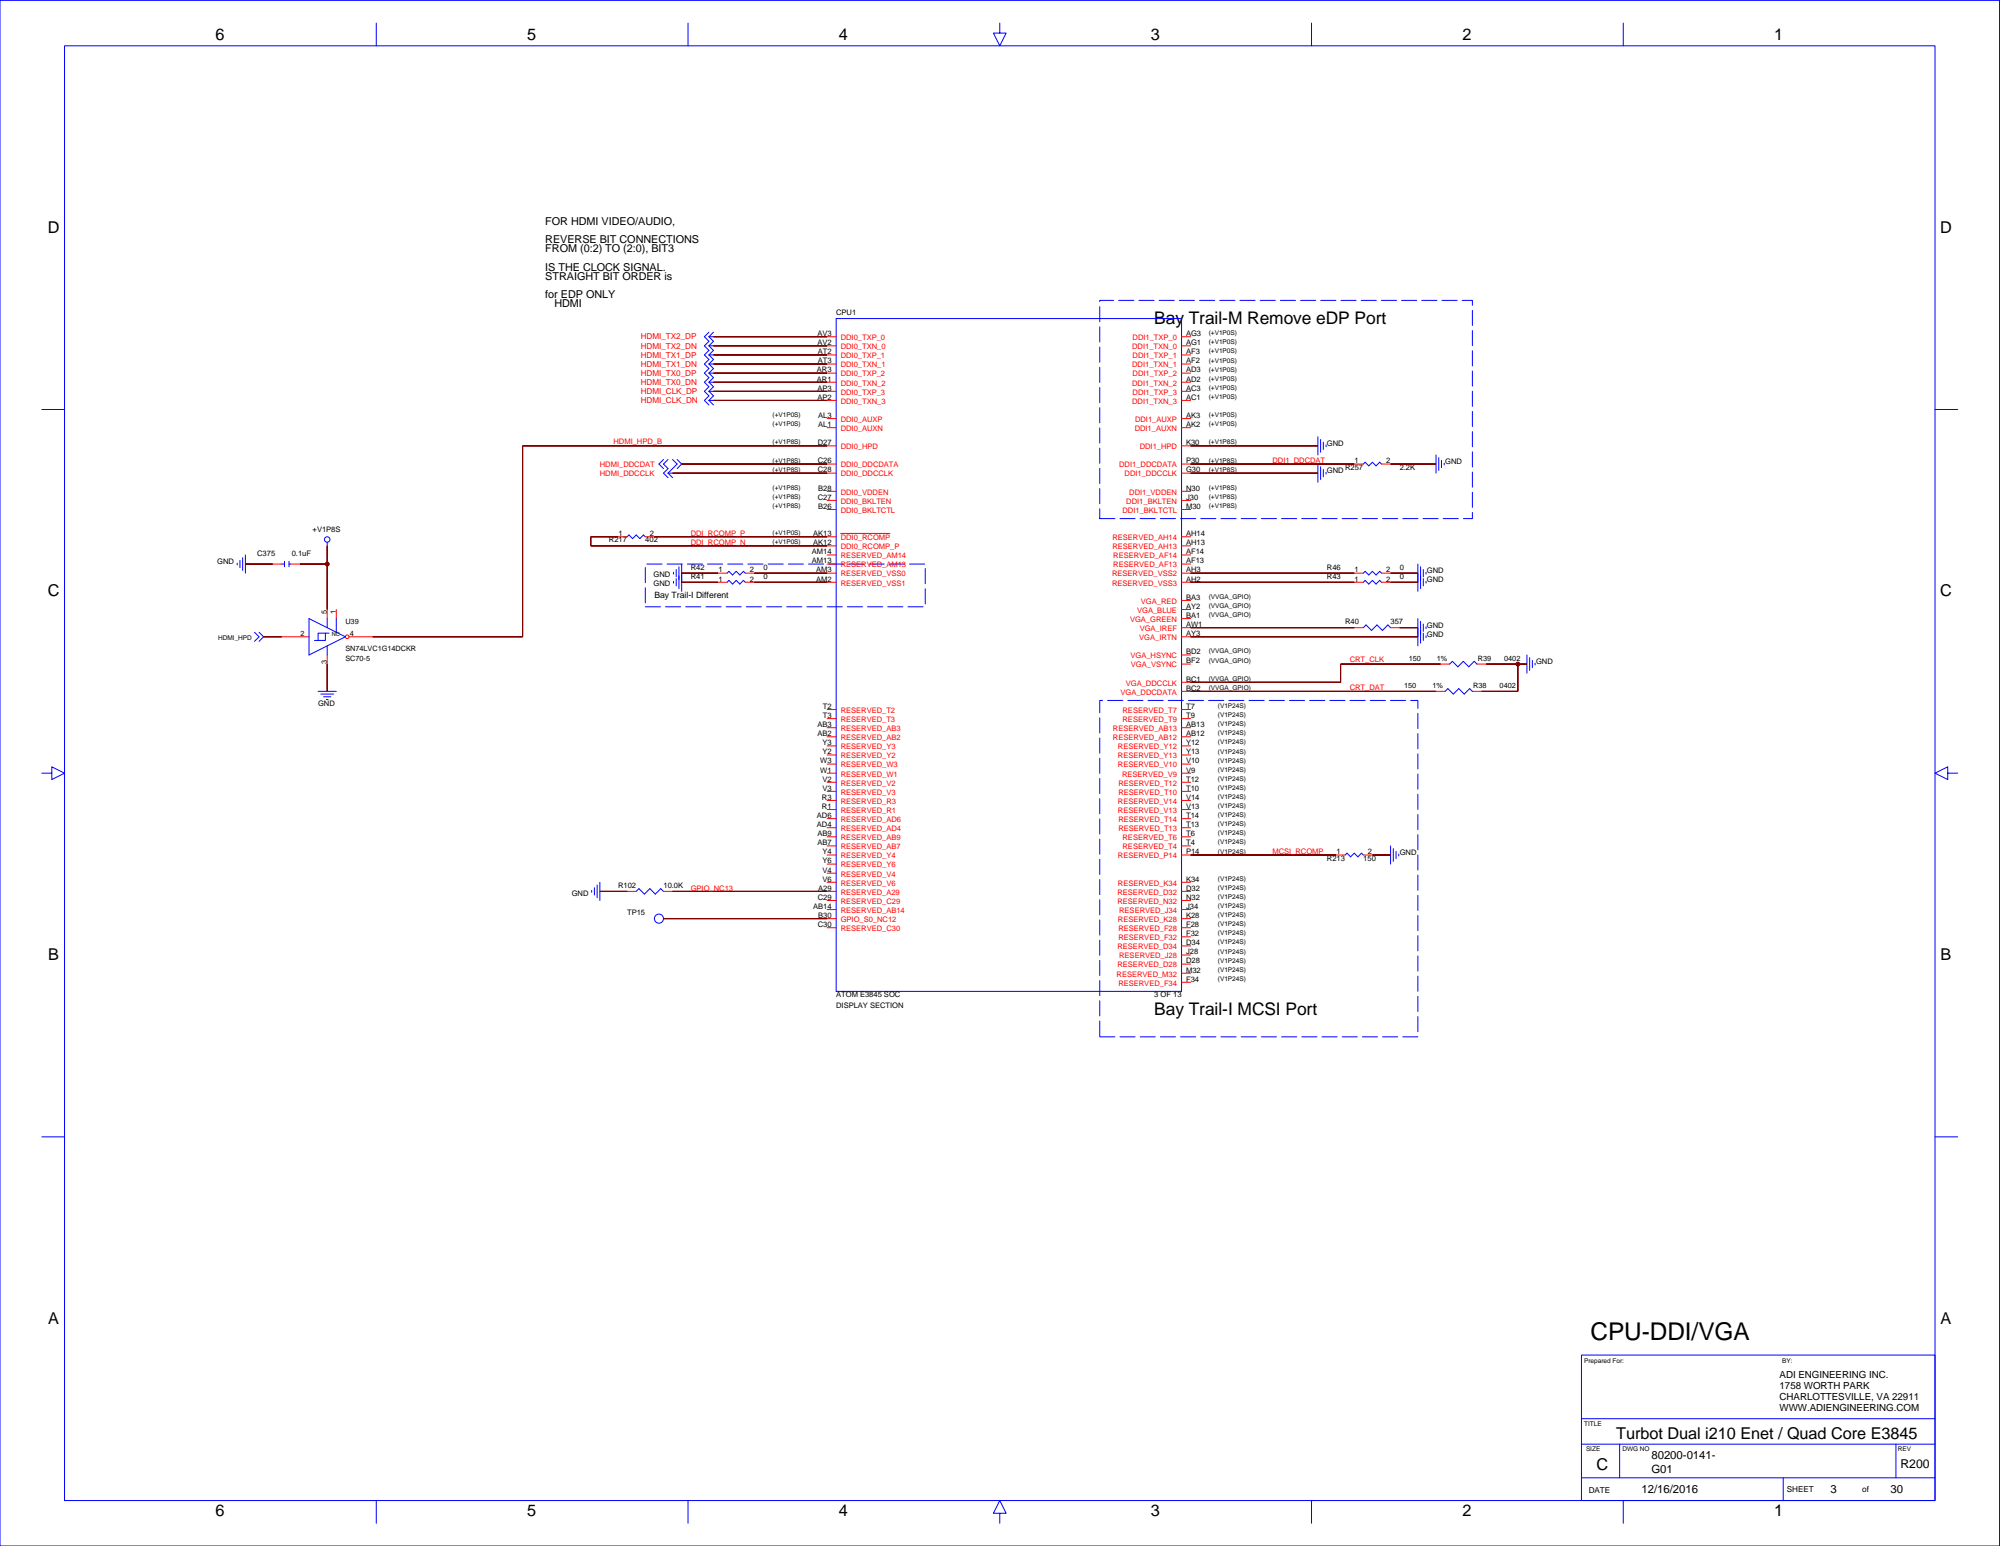
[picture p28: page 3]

FOR HDMI VIDEO/AUDIO,
REVERSE BIT CONNECTIONS
FROM (0:2) TO (2:0), BIT3
IS THE CLOCK SIGNAL.

Bay Trail-M Remove eDP Port

## ABCD

CD

## ABCD

CD

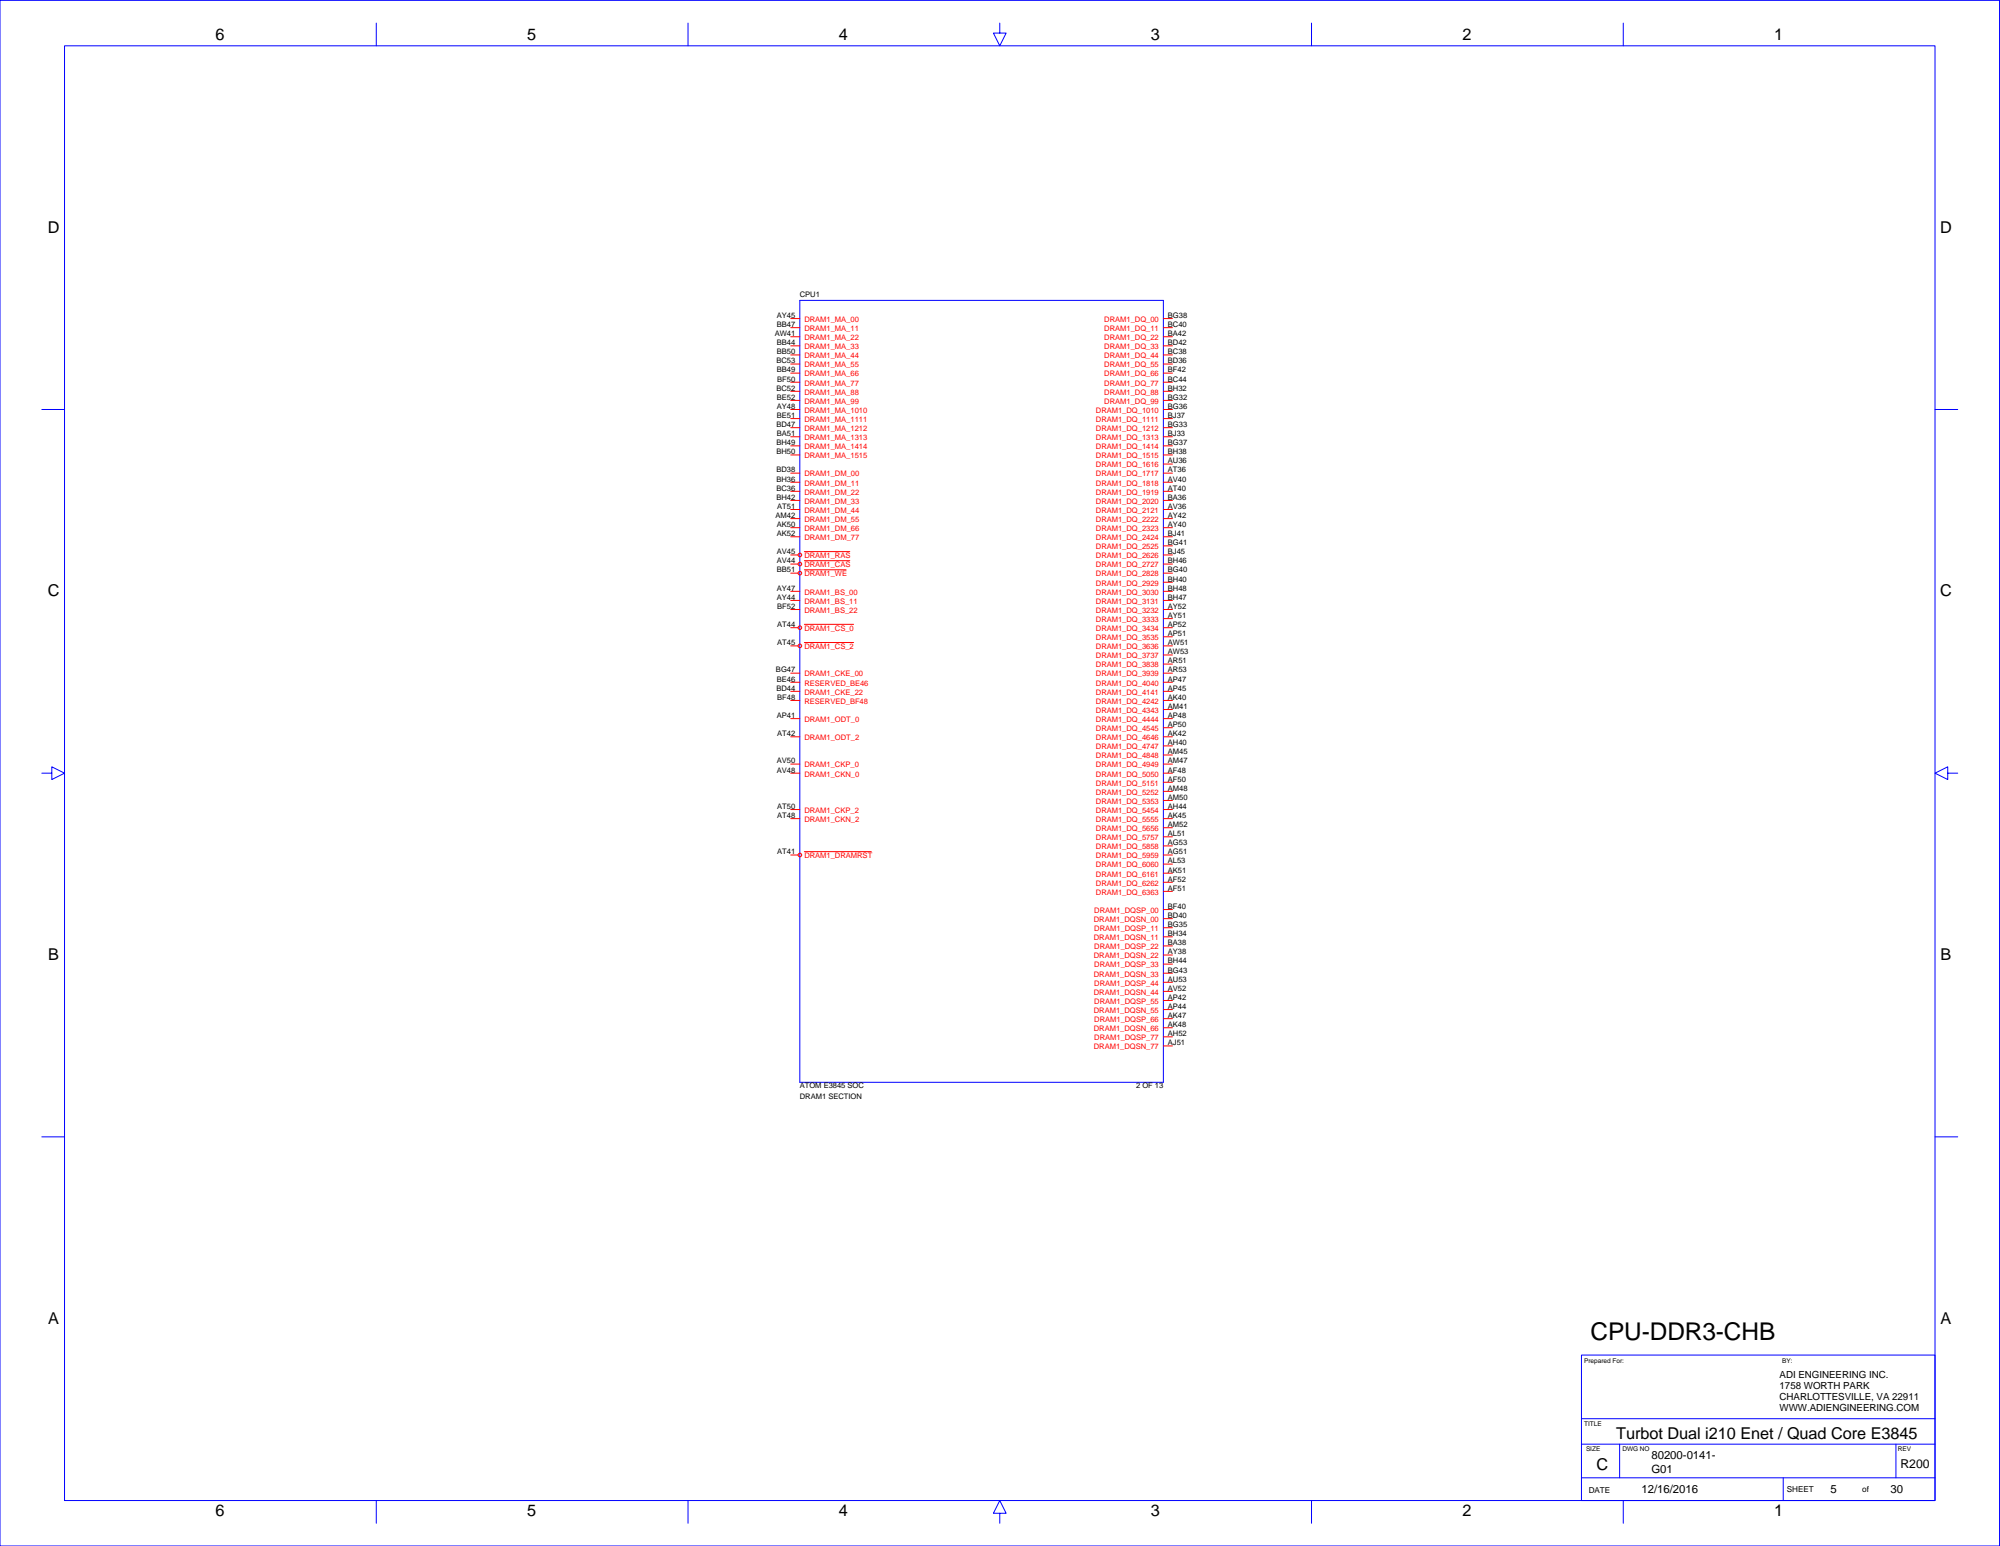
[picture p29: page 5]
DRAM1 SECTION; DRAM1_ODT_0; DRAM1_CKN_0; DRAM1_CKP_0; DRAM1_DRAMRST; DRAM1_CKN_2; DRAM1_CKP_2; DRAM1_DQSN_77; DRAM1_DQSP_77; DRAM1_DQSN_66; DRAM1_DQSP_66; DRAM1_DQSN_55; DRAM1_DQSP_55; DRAM1_DQSN_44; DRAM1_DQSP_44; DRAM1_DQSN_33; DRAM1_DQSP_33; DRAM1_DQSN_22; DRAM1_DQSP_22; DRAM1_DQSN_11; DRAM1_DQSP_11; DRAM1_DQSN_00; DRAM1_DQSP_00; DRAM1_DQ_6363; DRAM1_DQ_6262; DRAM1_DQ_6161; DRAM1_DQ_6060; DRAM1_DQ_5959; DRAM1_DQ_5858; DRAM1_DQ_5757; DRAM1_DQ_5656; DRAM1_DQ_5555; DRAM1_DQ_5454; DRAM1_DQ_5353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

ADI ENGINEERING INC.
1758 WORTH PARK
CHARLOTTESVILLE, VA 22911
WWW.ADIENGINEERING.COM

D

D

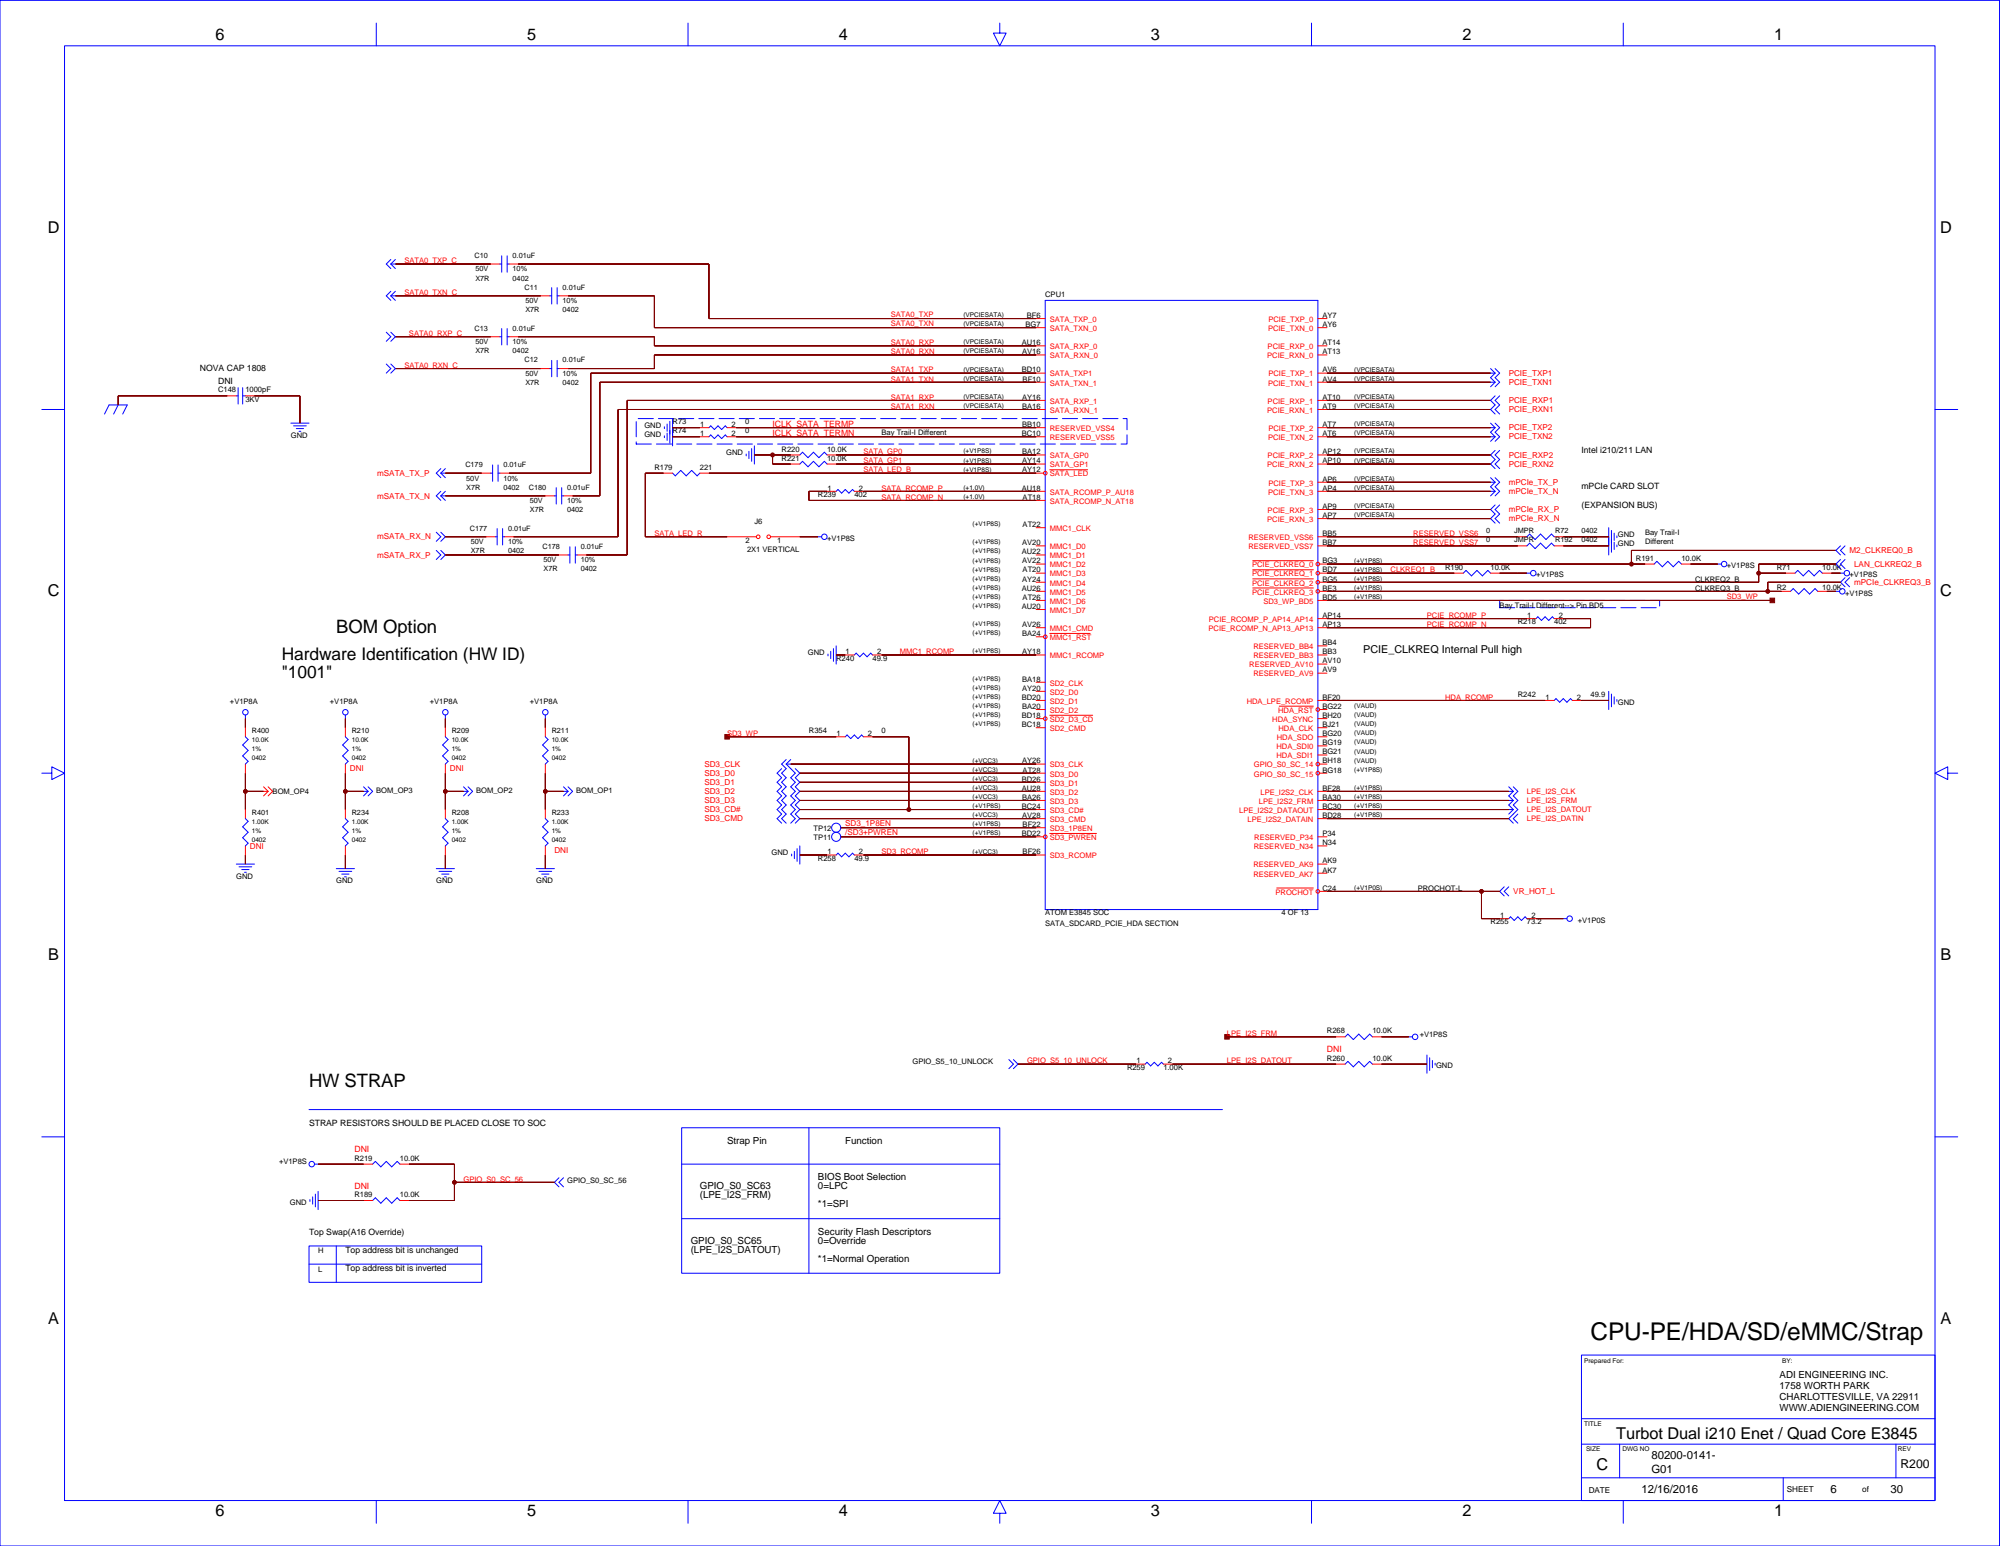
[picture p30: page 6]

Bay Trail-I Different--> Pin BD5

BOM Option
Hardware Identification (HW ID)

STRAP RESISTORS SHOULD BE PLACED CLOSE TO SOC

Top address bit is inverted

Top address bit is unchanged

CPU-PE/HDA/SD/eMMC/Strap

D

D

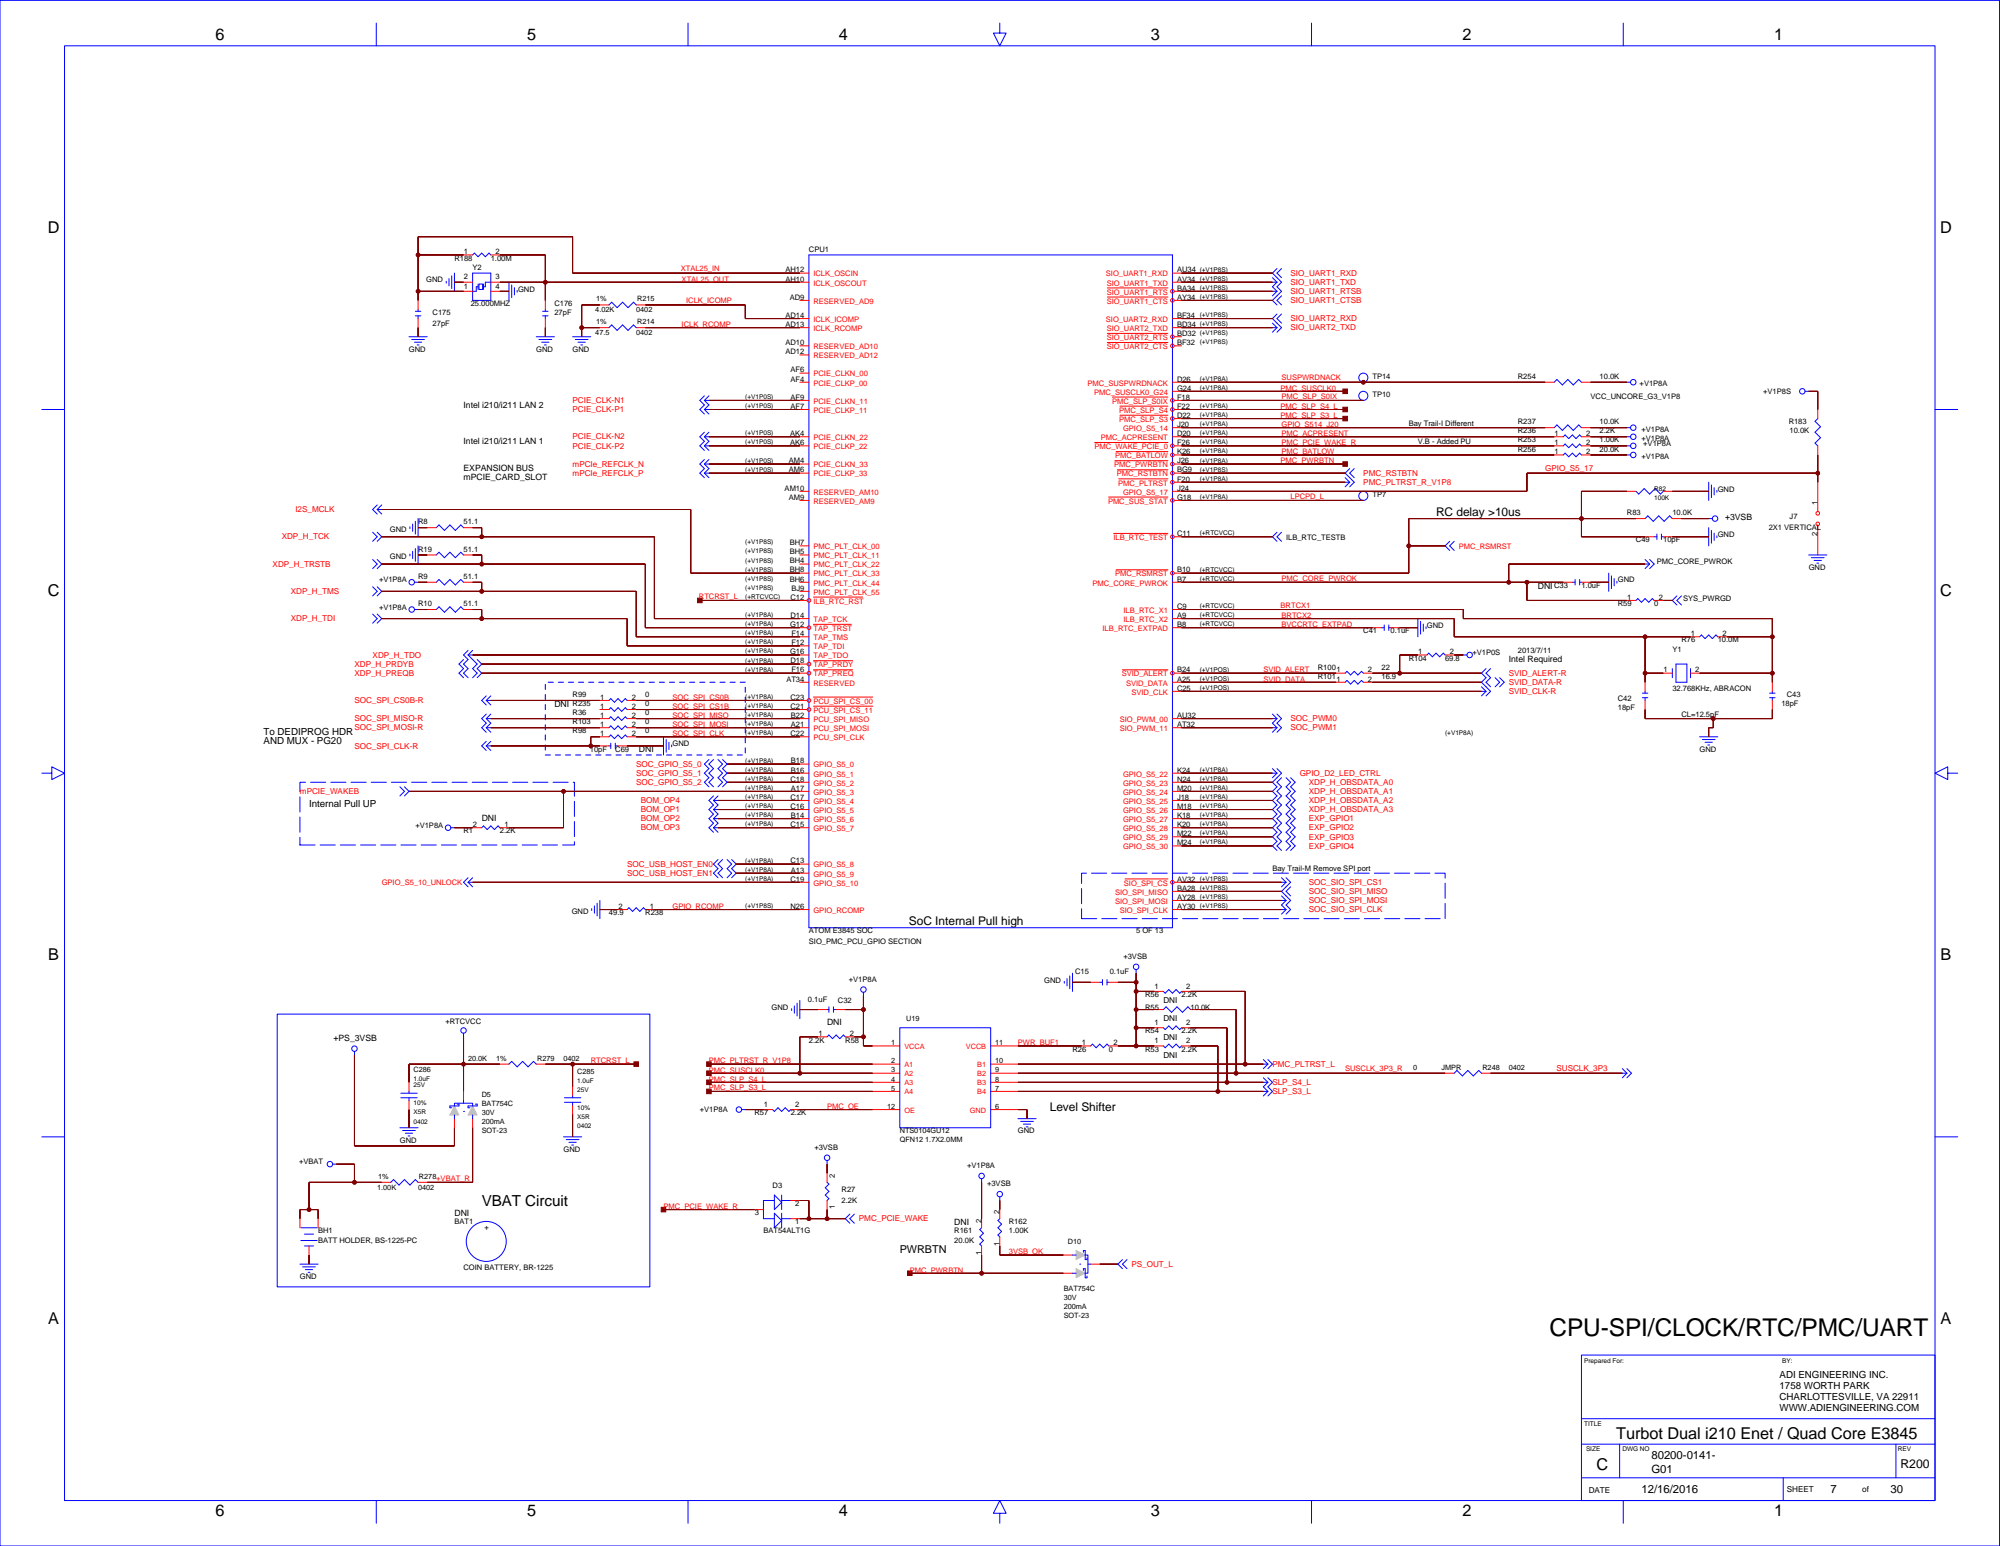
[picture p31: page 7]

Bay Trail-M Remove SPI port

SoC Internal Pull high

BATT HOLDER, BS-1225-PC

CPU-SPI/CLOCK/RTC/PMC/UART

## TX and RX LINES
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

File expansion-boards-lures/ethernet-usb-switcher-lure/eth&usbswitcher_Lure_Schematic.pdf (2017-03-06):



GND


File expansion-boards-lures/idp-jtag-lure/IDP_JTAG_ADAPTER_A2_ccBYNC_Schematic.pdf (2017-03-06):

GND; MSATA_TX_P; MSATA_RX_P; 4 MSATA_TX_N; MSATA_RX_N; 5VSB; MPCIE_REFCLK_P; USB_HOST_DP 10; MPCIE_REFCLK_N 11; USB_HOST_DN 12; GND 13 GND 14; MPCIE_TX_P 15; MPCIE_RX_P 16; MPCIE_TX_N 17; MPCIE_RX_N 18; 5VSB 19 5VSB 20; EXP_I2C_SCL; MPCIE_WAKEB 22; EXP_I2C_SDA; MPCIE_CLKREQ3_B 24; GND 25 GND 26; EXP_GPIO1; EXP_GPIO3; 28 EXP_GPIO2; EXP_GPIO4; 5VSB 31 5VSB 32; XDP_H_OBSDATA_A1; 33 XDP_H_OBSDATA_A0; XDP_H_OBSDATA_A2; XDP_H_OBSDATA_A3; GND 37 GND 38; XDP_H_PRDYB; XDP_H_PREQB_PB; HOOK0; HOOK1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

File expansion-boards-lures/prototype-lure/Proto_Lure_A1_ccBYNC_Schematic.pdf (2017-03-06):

A

A


PWM0 22

GPIO_S5_0 21

SPIO_S5_2 25

GND 1

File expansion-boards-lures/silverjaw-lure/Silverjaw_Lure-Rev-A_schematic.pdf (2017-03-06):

## mPCIe

## HSE


8 | I2C6_SDA | 4 | 5 | SDA

Released under the Creative Commons
Attribution-NonCommercial 4.0 International License
http://creativecommons.org/licenses/by-nc/4.0/
Designed by Rusty Herod
www.TinCanTools.com
Silverjaw Lure (mPCIe & mSATA)

Size B | Document Number Silverjaw Lure_Rev-A | Rev A

Date: Thursday, February 12, 2015 | Sheet 1 of 1

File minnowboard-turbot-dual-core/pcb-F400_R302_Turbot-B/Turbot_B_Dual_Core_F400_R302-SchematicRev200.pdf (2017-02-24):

# Rev : R200 TURBOT B

# POWER DELIVERY

Power Sequence; REVISION HISTORY:; Page; Index; Rev; Date; Notes; TABLE OF CONTENTS; TITLE; DATE; SHEET; SIZE; DWG NO; REV; Prepared For:; BOM Release for Pre-ordering Components; Pre-Release Design Review; Prototype Release; Production Release; Post DFx Release Production Release

Initial Design Review

Cover Page
Block Diagram
CPU-DDI/VGA
CPU-DDR3-CHA
CPU-DDR3-CHB
CPU-PE/HDA/SD/eMMC/Strap
CPU-SPI/CLOCK/RTC/PMC/UART
CPU-USB/LPC/SMB/I2C
CPU-PWR1
CPU-PWR2
CPU-GND
Memory_CHA-1
Memory_CHA-2
uSD CARD CAGE
HDMI / VGA
USB3+USB2
EXPANSION I/O
LAN Intel i210/i211
NOT USED
CSI/GPIO Header/UART_DBG
PWR BTN / LED / HOLE
DC-5VSB/3VSB / VCC / VCC3
DC/DC VCORE REGULATOR
DC/DC VGFX REGULATOR
DC-DIMM/DDR_VTT

DC-DC VOLTAGE
GPIO/HW Mapping

This work is licensed under the Creative Commons Attribution-Share
Alike 3.0 Unported License. To view a copy of this license, visit
http://creativecommons.org/licenses/by-sa/3.0/ or send a letter to
Creative Commons, 171 Second Street, Suite 300, San Francisco,
California, 94105, USA.
Minnowboard Turbot design derived from Minnowboard MAX as
designed by CircuitCo LLC.

All derivative works are to be attributed to ADI Engineering
and CircuitCo LLC .

For more information, see
http://creativecommons.org/license/results-one?license_code=by-sa

ADI ENGINEERING
1758 WORTH PARK
CHARLOTTESVILLE, VA 22911
WWW.ADIENGINEERING.COM

For all design files, including bill of materials
and gerber files, please visit
www.minnowboard.org

Turbot B - i211 / Dual Core E3826

## page12/13

# Memory CH0

pages 3-11; page20; HEADER; DEDI-PROG; EXP; LSS; page17; JTAG_HDR; EXP_GPIO(3:0) BUS,; EXP_I2C BUS,; mPCIE, SATA,; EXPANSION I/O; SATA; SATA0; page6; page18; page15; page14; page16; UART; USB2.0; USB2.0x1; USB3.0x1; USB3.0; DDI0; uHDMI; SOC_SPI; SPI ROM; PCIe_X1; Intel i210 / i211; LAN; DDR3L memory down x16; Bay Trail-I; BLOCK DIAGRAM; Prepared For:; LEVEL TRANSLATOR

DDR3-L :1.35V
Capable of 1066 (E3826) or 1333 (E3845)

uSD CARD CAGE

LOW SPEED SERIAL I/O
SIO_SPI BUS, GPIO_I2C BUS,
UART2 (TXD/RXD)
UART1 (TXD/RXD/CTSB/RTSB,
I2S BUS, PWM(1:0),

ADI ENGINEERING
1758 WORTH PARK
CHARLOTTESVILLE, VA 22911
WWW.ADIENGINEERING.COM

## for EDP ONLY

## STRAIGHT BIT ORDER is


FOR HDMI VIDEO/AUDIO,
REVERSE BIT CONNECTIONS
FROM (0:2) TO (2:0), BIT3
IS THE CLOCK SIGNAL.
Bay Trail-M Remove eDP Port HDMI

## ABCD

CD


## ABCD

CD

ADI ENGINEERING
1758 WORTH PARK
CHARLOTTESVILLE, VA 22911
WWW.ADIENGINEERING.COM

D

D


Bay Trail-I Different--> Pin BD5

BOM Option
Hardware Identification (HW ID)

STRAP RESISTORS SHOULD BE PLACED CLOSE TO SOC

Top address bit is inverted

Top address bit is unchanged

CPU-PE/HDA/SD/eMMC/Strap

D

D


Bay Trail-M Remove SPI port

SoC Internal Pull high

BATT HOLDER, BS-1225-PC

CPU-SPI/CLOCK/RTC/PMC/UART

## TX and RX LINES

## USB3 HIGH SPEED


LOW SPEED SERIAL I2C BUS
EXPANSION I2C BUS

CPU-USB/LPC/SMB/I2C

D

D


AC30 | | AC22
AD27 | | AC24
AD29 | | AD22
AD30 | | AD24 | Under the PKG Shadow
AF27 | | AF22
AF29 | | AF24
AG27 | | AG22
AG29 | | AG24
AG30 | | AJ22
P26 | | AJ24
P27 | | AK22
U27 | | AK24
U29 | | AK25
V27 | | AK27
V29 | | AK29
V30 | | AK30
Y27 | | AK32
Y29 | | AM22
Y30 | | AA22

Under the PKG Shadow

Edge of the Board

10mA

900mA


Place close to Pin BJ6.

Place close to Pin AF16,AF18.

Place close to Pin G1

Place close to Pin AN21

Place close to Pin AN19

Place close to Pin AN18

Place close to Pin AN25.

Can be grounded if MIPI
CSI not used.
Bay Trail-I

USB_HSIC_V1P24_G3 Can connect to V1P0A when USB HSIC not used.

Place close to Pin AA18
Place close to Pin U25

Place close to Pin AF36.

Place close to Pin AD35, AF36

Place close to Pin AK19/AK21

Place close to Pin AJ18.

Place close to Pin AM16.

Place close to Pin N18,P18.

Place close to Pin AF21,AG21

Place close to Pin AG21,V24,Y22,Y24.

Place close to Pin V18 400mA

Place close to Pin AD36.

Place close to Pin U36

Place close to Pin AF19

Place close to Pin AC32,Y32.

Place close to Pin AG32

Place close to Pin AA25

D

D
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

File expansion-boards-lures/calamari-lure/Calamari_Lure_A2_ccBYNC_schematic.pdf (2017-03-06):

A

A



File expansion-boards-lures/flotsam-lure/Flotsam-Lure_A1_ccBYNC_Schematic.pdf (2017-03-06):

A

A


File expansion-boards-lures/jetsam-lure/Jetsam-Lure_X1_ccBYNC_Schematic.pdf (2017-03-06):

A

A


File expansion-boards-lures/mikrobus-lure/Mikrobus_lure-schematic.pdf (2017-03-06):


Released under the Creative Commons Attribution Share-Alike 3.0 License
http://creativecommons.org/licenses/by-sa/3.0

Document Number: | REV: A1

Date: 4/28/2015 4:15:02 PM | Sheet: 1/1

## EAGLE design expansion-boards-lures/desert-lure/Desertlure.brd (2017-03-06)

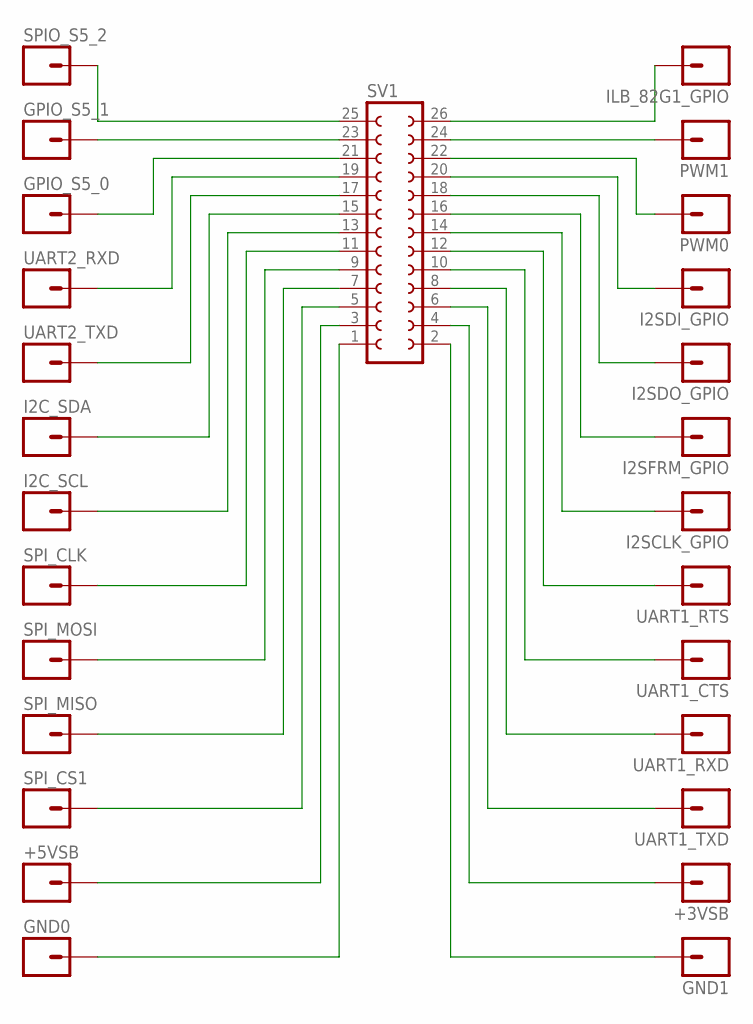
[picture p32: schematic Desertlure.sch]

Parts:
+3VSB, +5VSB: M01NOSILK-KIT; 1X01NS-KIT
GND0, GND1: M01NOSILK-KIT; 1X01NS-KIT
GPIO_S5_0, GPIO_S5_1: M01NOSILK-KIT; 1X01NS-KIT
I2C_SCL, I2C_SDA, I2SCLK_GPIO, I2SDI_GPIO, I2SDO_GPIO, I2SFRM_GPIO: M01NOSILK-KIT; 1X01NS-KIT
ILB_82G1_GPIO: M01NOSILK-KIT; 1X01NS-KIT
PWM0, PWM1: M01NOSILK-KIT; 1X01NS-KIT
SPIO_S5_2: M01NOSILK-KIT; 1X01NS-KIT
SPI_CLK: M01NOSILK-KIT; 1X01NS-KIT
SPI_CS1: M01NOSILK-KIT; 1X01NS-KIT
SPI_MISO: M01NOSILK-KIT; 1X01NS-KIT
SPI_MOSI: M01NOSILK-KIT; 1X01NS-KIT
SV1: FE13-2W
UART1_CTS, UART1_RTS, UART1_RXD, UART1_TXD, UART2_RXD, UART2_TXD: M01NOSILK-KIT; 1X01NS-KIT

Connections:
unnamed: GND0.1, SV1.1
unnamed: +5VSB.1, SV1.3
unnamed: SPI_CS1.1, SV1.5
unnamed: SPI_MISO.1, SV1.7
unnamed: SPI_MOSI.1, SV1.9
unnamed: SPI_CLK.1, SV1.11
unnamed: I2C_SCL.1, SV1.13
unnamed: I2C_SDA.1, SV1.15
unnamed: SV1.17, UART2_TXD.1
unnamed: SV1.19, UART2_RXD.1
unnamed: GPIO_S5_0.1, SV1.21
unnamed: GPIO_S5_1.1, SV1.23
unnamed: SPIO_S5_2.1, SV1.25
unnamed: GND1.1, SV1.2
unnamed: +3VSB.1, SV1.4
unnamed: SV1.6, UART1_TXD.1
unnamed: SV1.8, UART1_RXD.1
unnamed: SV1.10, UART1_CTS.1
unnamed: SV1.12, UART1_RTS.1
unnamed: I2SCLK_GPIO.1, SV1.14
unnamed: I2SFRM_GPIO.1, SV1.16
unnamed: I2SDO_GPIO.1, SV1.18
unnamed: I2SDI_GPIO.1, SV1.20
unnamed: PWM0.1, SV1.22
unnamed: PWM1.1, SV1.24
unnamed: ILB_82G1_GPIO.1, SV1.26

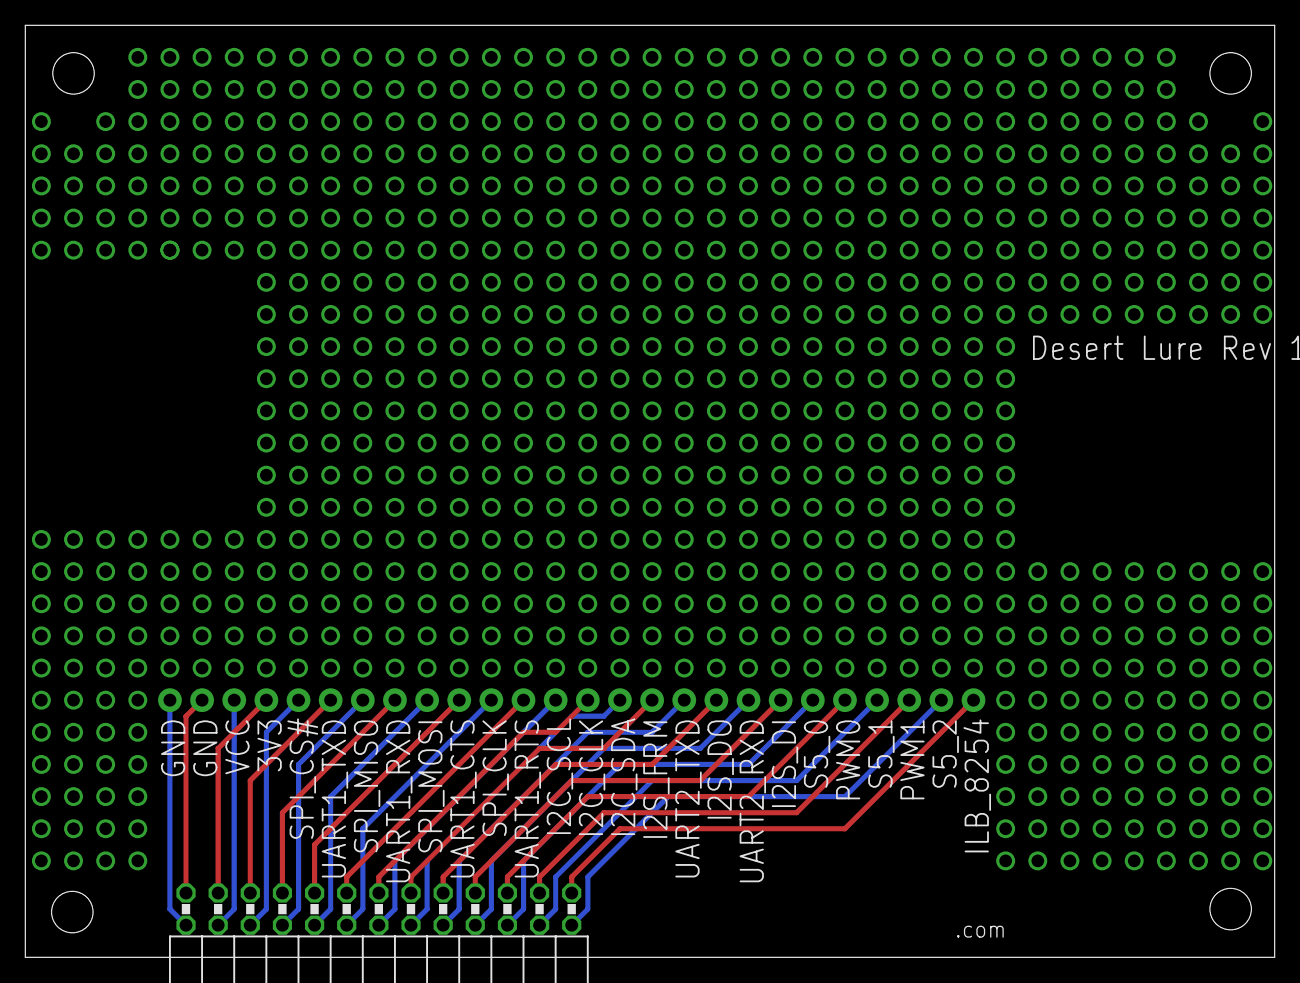
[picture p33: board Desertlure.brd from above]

Board: 2 copper layers, 98.7 x 73.7 mm, 27 parts (0 on the bottom side), 26 nets.

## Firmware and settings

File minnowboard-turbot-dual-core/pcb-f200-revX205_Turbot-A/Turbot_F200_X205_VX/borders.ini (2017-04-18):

[SYMBOLS]
A0SHEETL=builtin:a0sheet.1
A0SHEETL1=builtin:a0sheet.1
A0SHEETP=builtin:a0sheet.2
A0SHEETP1=builtin:a0sheet.2
A1SHEETL=builtin:a1sheet.1
A1SHEETL1=builtin:a1sheet.1
A1SHEETP=builtin:a1sheet.2
A1SHEETP1=builtin:a1sheet.2
A2SHEETL=builtin:a2sheet.1
A2SHEETL1=builtin:a2sheet.1
A2SHEETP=builtin:a2sheet.2
A2SHEETP1=builtin:a2sheet.2
A3SHEETL=builtin:a3sheet.1
A3SHEETL1=builtin:a3sheet.1
A3SHEETP=builtin:a3sheet.2
A3SHEETP1=builtin:a3sheet.2
A4SHEETL=builtin:a4sheet.1
A4SHEETL1=builtin:a4sheet.1
A4SHEETP=builtin:a4sheet.2
A4SHEETP1=builtin:a4sheet.2
ASHEETL=builtin:asheet.1
ASHEETL1=builtin:asheet.1
ASHEETP=builtin:asheet.2
ASHEETP1=builtin:asheet.2
BSHEETL=builtin:bsheet.1
BSHEETL1=builtin:bsheet.1
BSHEETP=builtin:bsheet.2
BSHEETP1=builtin:bsheet.2
CSHEETP=builtin:csheet.2
CSHEETP1=builtin:csheet.2
DSHEETL=builtin:dsheet.1
DSHEETL1=builtin:dsheet.1
DSHEETP=builtin:dsheet.2
DSHEETP1=builtin:dsheet.2
ESHEETL=builtin:esheet.1
ESHEETL1=builtin:esheet.1
ESHEETP=builtin:esheet.2
ESHEETP1=builtin:esheet.2
[ZONE CSHEETL]
OFFSETLEFT=1778000
OFFSETRIGHT=1778000
OFFSETTOP=1270000
OFFSETBOTTOM=1270000
VERTNUMBER=2
HORZNUMBER=2
VERTLABELING=1
HORZLABELING=0
[ATTRIBUTES]
AUTHOR=ADI
CONFIDENTIAL=
DRAWING=
DRAWING2=ADI -80204-0125-G00
ORGADDR1=
ORGADDR2=
ORGADDR2_1=1758 WORTH PARK
ORGADDR2_2=CHARLOTTESVILLE, VA 22911
ORGINFO=
ORGINFO2=WWW.ADIENGINEERING.COM
ORGNAME=
ORGNAME2=ADI ENGINEERING
REVISION=X205
TITLE=TURBOT
[ANNOTATIONS]
[DEFAULTS]

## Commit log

2017-02-01 new files
    [0402C.step, 0402C_V3.step, 0402R.step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]
2017-02-01 Create license.md
    Replicated the license provided for PCB rev F200, originally open sourced at the old wiki.minnowboard.org.
2017-02-01 Create PCB-a2 license
    replicates license established for original release of files on old website wiki.minnowboard.org
2017-02-09 lower case pcb rev directory
    that is it.
2017-02-10 MB v1 files from wiki
    [MinnowBoard_BOM_002-003195_REVA_CCR_BOM.XLSX, Minnow_RevA_ASSY.dxf, Minnow_RevA_FAB.dxf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]
2017-02-10 Created license file that replicates original files release.
    License file created for rev-a of MinnowBoard-v1. This file exactly
    copies the license appearing on schematic pdf, and applies to all the
    PCB design files posted.
2017-04-17 Removed placeholder PCB folder
2017-04-18 moved Turbot A21 files under single Turbot dual folder
    moved Turbot A21 files under single Turbot dual folder. NO Content
    changes.
    [0402C.step, 0402C_V3.step, 0402R.step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]
2017-04-18 Removed Duplicate license.md file for the F400-R302 pcb.
    removed duplicate license.md. Master license file for F400-R302 remains
    under the associated PCB folder containing the collatera.
2017-09-27 README.md: fix markdown formatting
    The markdown formatting of the README.md file was slightly incorrect causing the rendering to be broken. This fixes the formatting and also adds a couple of hyperlinks.
2017-10-04 .dxf file as provided by Len at ADI
    Mentor output to dxf.
    [TurbotB_F400.dxf]
2017-10-04 .dxf file addition
    Direct Mentor output to .dxf, as provided by Len at ADI Engineering.
    [TurbotB_F400.dxf]
2017-10-04 DXF Showing Mounting and Part Holes. Units are thousandths of an inch.
    [Turbot-DualE_F300_Mounting_Part_Holes.dxf]
2017-10-23 Design for MinnowBoard Turbot fan less heatsink
    Design sketch for MinnowBoard Turbot B Dual-Core fan-less heatsink.
2017-10-23 Added sketch for MB Turbot Quad-Core fan-sink
    Design sketch for MinnowBoard Turbot Quad-Core fan based heat-sink.

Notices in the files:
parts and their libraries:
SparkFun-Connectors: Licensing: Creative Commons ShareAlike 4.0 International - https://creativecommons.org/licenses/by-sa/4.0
